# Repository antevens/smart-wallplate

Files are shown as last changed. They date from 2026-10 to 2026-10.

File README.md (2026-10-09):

# Smart wall plate

Replacement for a single-gang light switch: recessed IKEA BILRESA remote, hidden
emergency rocker, Apollo MSR-2 mmWave presence + SHT45 climate + a push-to-talk
microphone for Home Assistant voice, powered by a Mean Well IRM-03-5 on the wiring board.

Start with `AGENTS.md` (for people too), then `docs/SAFETY.md`. `docs/PRINTING.md` lists the print
jobs in order, `docs/ASSEMBLY.md` what holds each part, `docs/MEASUREMENTS.md` what is measured and
what is still an estimate.

Two variants: **NA** (single-gang Decora box, this page's main renders) and **EU** (round DIN 49073
box, `cad/build123d/eu/`, `pcb/eu/`). Both can run the BILRESA without batteries through a
replacement back cover powered from the plate.

The plate is two printed parts: a **box insert** (all mains/low-voltage barrier
geometry, UL94 V-0 PC-FR) and a **trim plate** (PETG/ASA), for an Elegoo Centauri
Carbon 2.

The house wiring lands on one board: L/N/PE in and out on a WAGO push-in block,
the Marquardt 1802.2504 DPST emergency rocker, and the PSU, all in a 2.5"
single-gang box. The KiCad project is in `pcb/`.

```bash
make system-deps     # once, Ubuntu 24.04 (KiCad 9, headless slicer libs)
make setup           # once (venv + pinned OrcaSlicer)
make cad check       # CAD -> build/, all checks must pass
make print           # OrcaSlicer projects -> print/*.3mf
make pcb             # all boards and flexes: ERC/DRC, STEP, PCBWay packs -> pcb/fab/, pcb/eu/fab/
make eu              # EU variant: CAD, checks, renders
make renders         # docs/renders/*.png
```

Nothing here is certified or code-compliant; see `docs/SAFETY.md`.

## How it is meant to be used

The design assumes every light bulb and device on the switched circuit is a smart
device that turns itself on and off (here IKEA Matter-over-Thread bulbs). The circuit
stays powered; day-to-day control is wireless: the BILRESA remote in the plate, Home
Assistant, the IKEA app, or Alexa / Google / other assistants.

The rocker hidden behind the remote is not the everyday light switch. It is there for
two cases:

- **Controller or cloud down.** When Home Assistant, the IKEA hub or the voice
  assistant is unavailable, turn the rocker off and on again. The bulbs restart and come
  on by themselves at their built-in power-on brightness. This needs each bulb's power-on
  behaviour set to "On" (D-8); check it per bulb.
- **Safety.** Off cuts line and neutral to the fixtures on this circuit (and powers down
  the plate's sensors), for example when a bulb or fixture misbehaves or needs changing.
  It is not a substitute for the breaker: turn the breaker off before working on any
  wiring (`docs/SAFETY.md`).

Voice: the plate's microphone streams to Home Assistant's Assist pipeline only when
listening is started from Home Assistant, for example by an automation on a BILRESA button
(D-29). There is no wake word and no speaker in the plate; replies go to another device.

Plain (non-smart) bulbs on this circuit would just follow the rocker, and the remote,
the sensors and the automations could not control them.

## Renders

### v0.3

Shaded views of the assembly: trim plate (white), box insert (grey), BILRESA
remote (model), Marquardt 1802.2504 rocker (red), wiring board (green, KiCad
model), board posts (orange). Regenerate with `make renders`.

| Front | Remote lifted out |
| --- | --- |
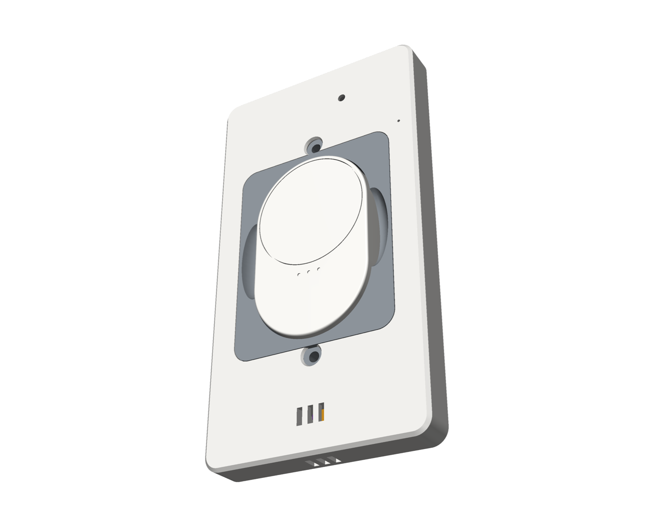
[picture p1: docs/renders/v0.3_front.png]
v0.3 front
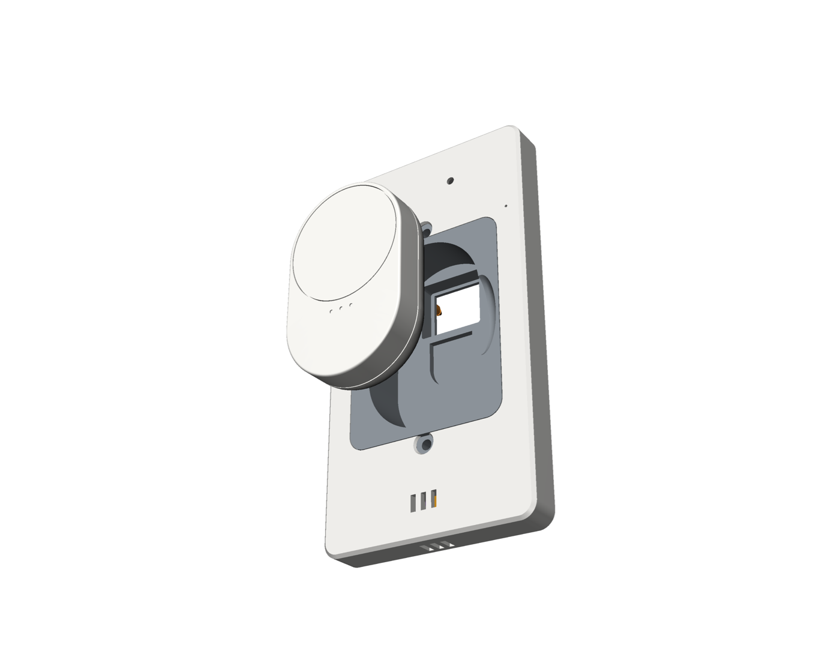
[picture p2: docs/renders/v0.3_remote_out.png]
v0.3 remote out
|  |  |

| Half-section | Back, mains side |
| --- | --- |
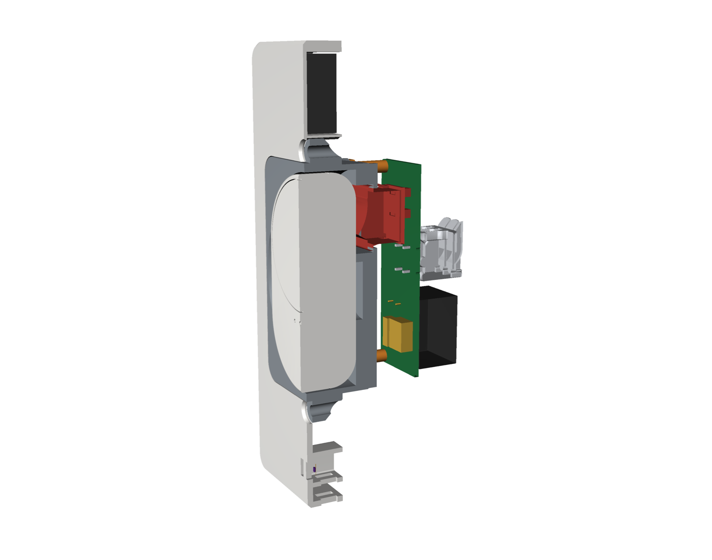
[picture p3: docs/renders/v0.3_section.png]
v0.3 half-section
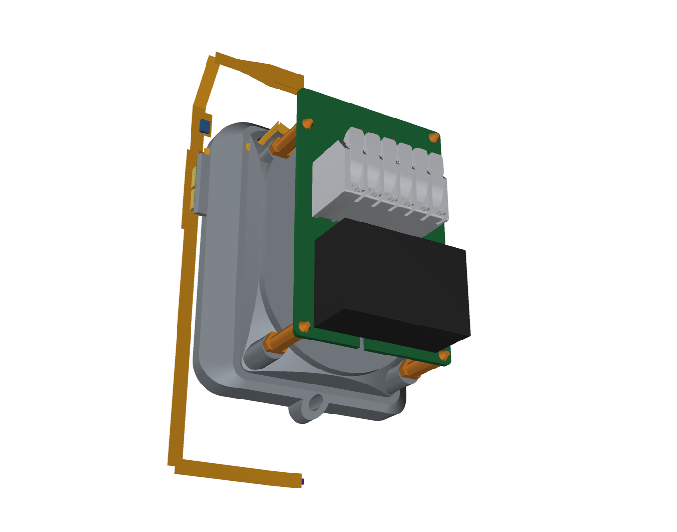
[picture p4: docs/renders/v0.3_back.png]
v0.3 back
|  |  |

Exploded: remote, trim plate, box insert, the four board posts that screw into
the insert's bosses (D-28), wiring board (with the rocker, WAGO block and PSU from
the KiCad model).

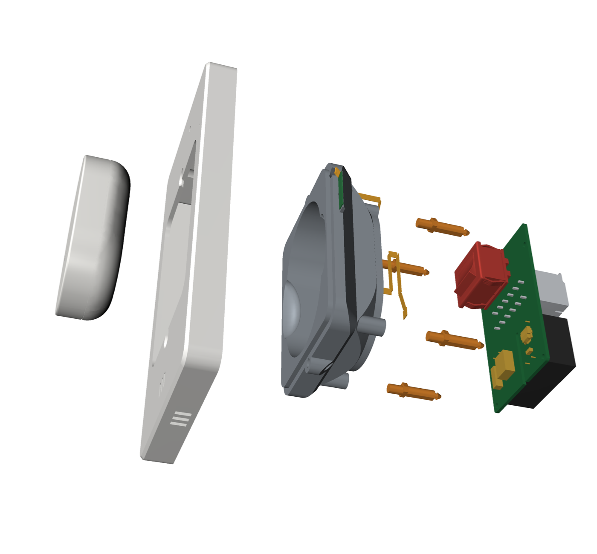
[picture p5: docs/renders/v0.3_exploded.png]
v0.3 exploded assembly


Sensor flex (D-27, trim and remote hidden): from the MSR-2's rear connector across
the top, down the right channel past the insert, to the SHT45 on its tail.

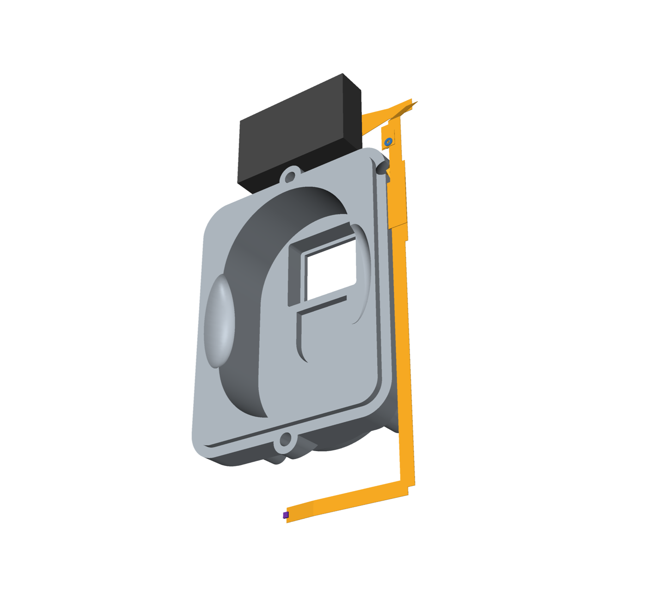
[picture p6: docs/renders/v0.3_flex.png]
v0.3 sensor flex route


Power contact: two spring fingers on the flex press on the gold pads of the 5 V jumper's
stiffened end, which sits on a shelf off the insert flange.

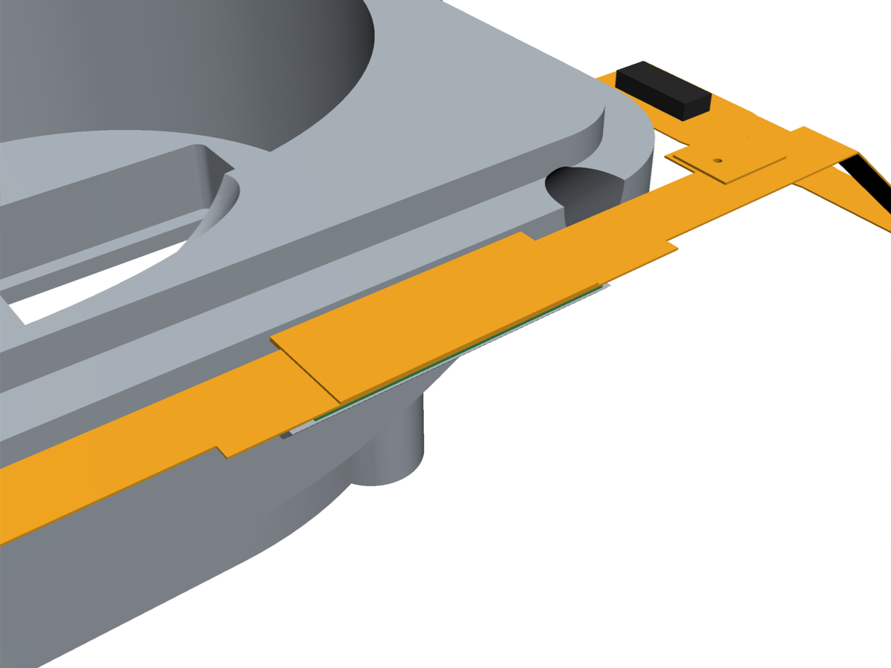
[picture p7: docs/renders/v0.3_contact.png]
v0.3 spring-finger power contact


5 V power path (insert cut at the pass-through, seen from the right): a single-layer flex
jumper plugs into J2 on the wiring board (Hirose FH12-6S, slide lock), folds once between the
board and the insert (a 40 mm service loop: plug it in with the board held beside the insert,
where the latch can be seen), goes up through the pass-through and out of the flange, and ends
on the shelf under the spring fingers. No wires, no solder joints at assembly.

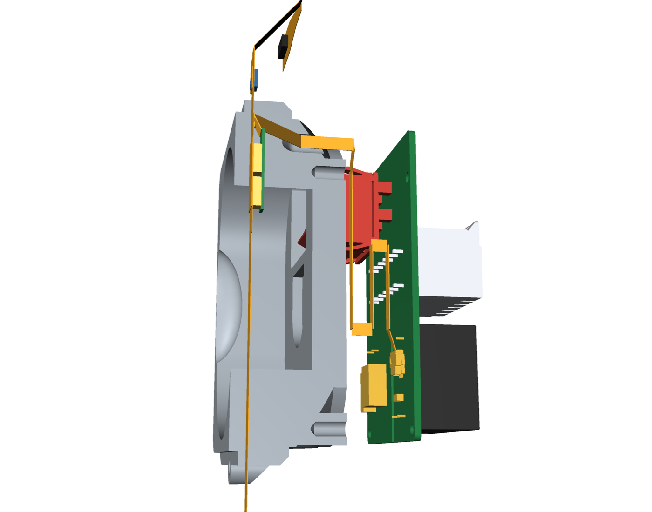
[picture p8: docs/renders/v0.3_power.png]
v0.3 5 V power path


Face plate lifted off (trim see-through): the flex with the MSR-2, SHT45, mic and spring fingers goes
with the face plate; the 5 V jumper (wiring board J2 -> pass-through -> pad end on the shelf) stays on
the insert side. The fingers on the jumper's pads are the only electrical interface (R9, checked).

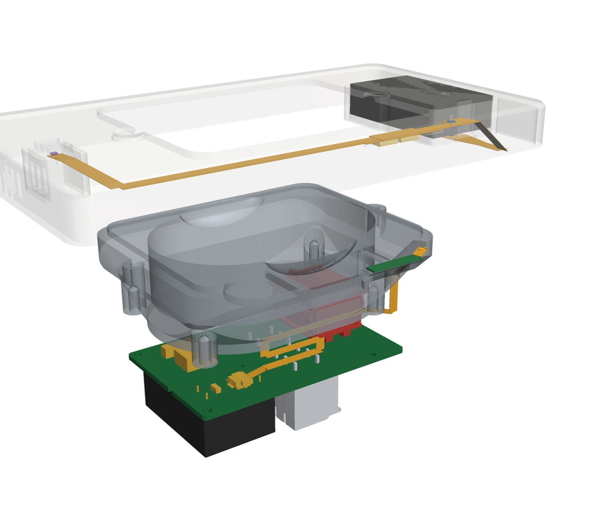
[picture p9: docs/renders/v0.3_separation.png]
v0.3 face plate and insert separated


Microphone (D-29, push-to-talk voice to Home Assistant): an I²S MEMS microphone under the
flex in the right channel, its port sealed by a gasket ring to a Ø1.0 sound hole in the face
skin. Sections through the sound hole, across and along the channel:

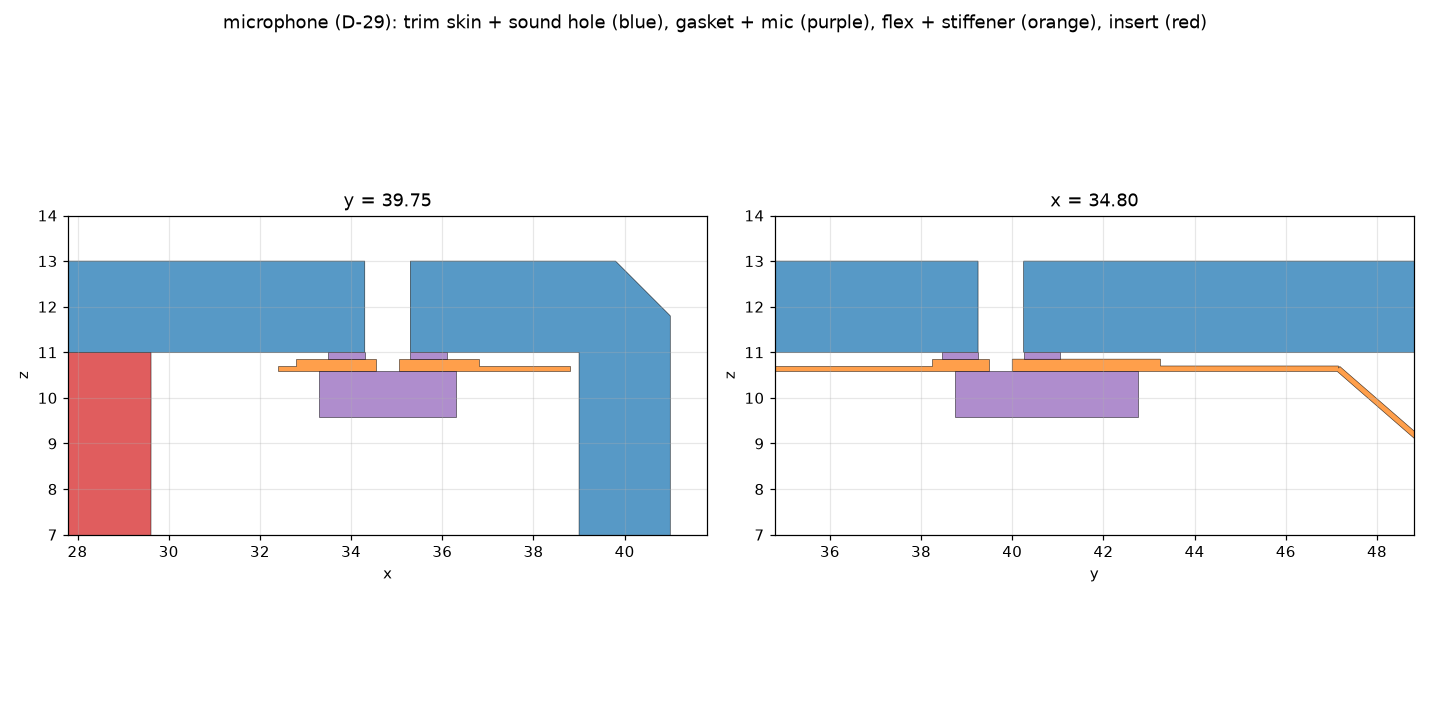
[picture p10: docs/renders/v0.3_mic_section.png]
v0.3 microphone sections


BILRESA model: stadium outline, wheel with its gap ring, three LEDs, side
parting line, and a back that curves from a flat central pad out to the sides.

| Front | Back |
| --- | --- |
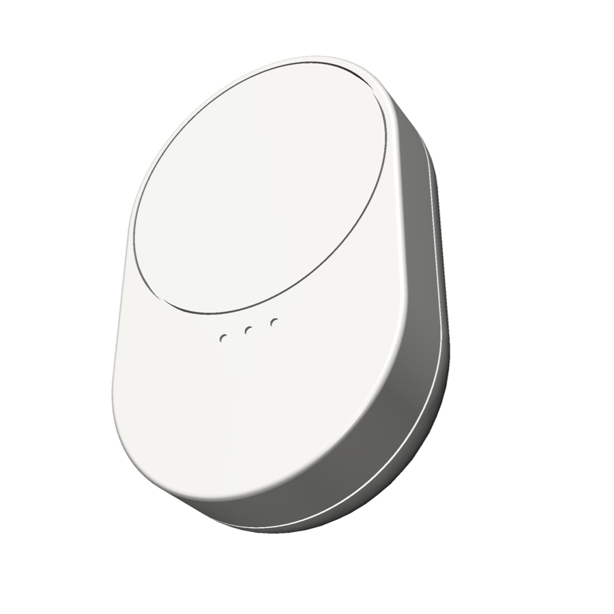
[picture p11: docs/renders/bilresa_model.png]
BILRESA model, front
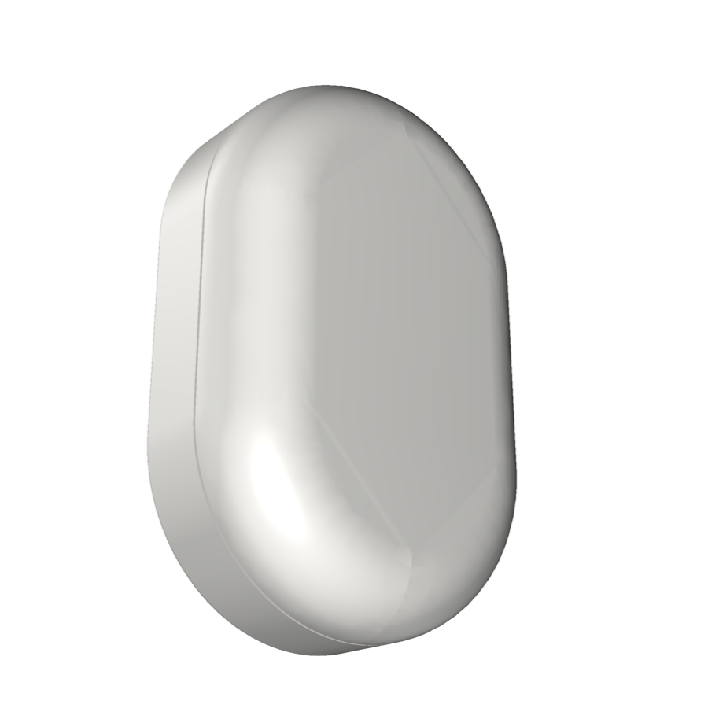
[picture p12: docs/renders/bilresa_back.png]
BILRESA model, back
|  |  |

Cross-sections: box insert (red, UL94 V-0), trim plate (blue), wiring board
(green), board posts (orange), BILRESA (grey). The dashed line is the wall surface;
the x = -21 cut runs through two posts and their bosses.

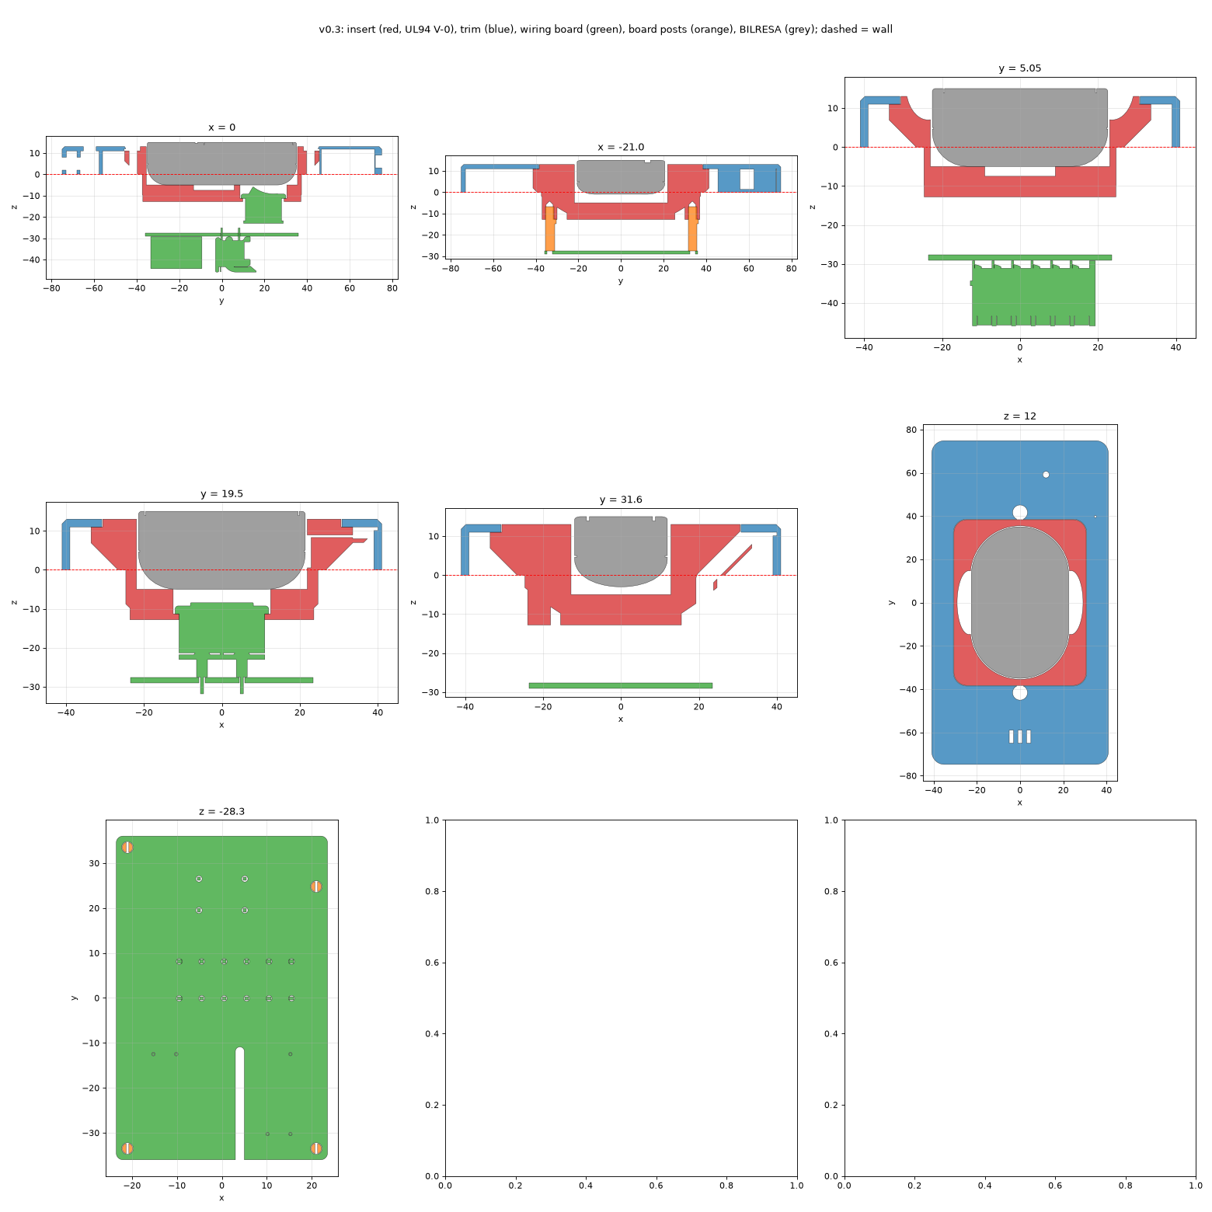
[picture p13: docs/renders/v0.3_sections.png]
v0.3 assembly cross-sections


### v0.3 wiring board

KiCad renders of `pcb/`. The front faces the plate (rocker, SMD
fuse and MOV, 5 V connector); the back faces the box (WAGO block, PSU). The four
corner holes take the insert's snap posts; they are unplated with no copper round them, and the
PE ring detours round them, so earth continuity never depends on the posts or on vias.

| Front | Back |
| --- | --- |
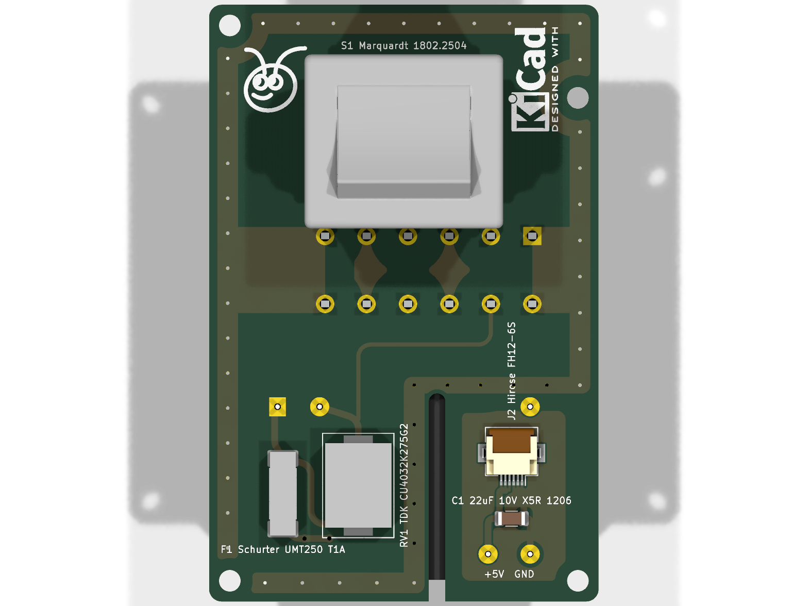
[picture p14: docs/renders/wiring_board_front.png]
Wiring board, front
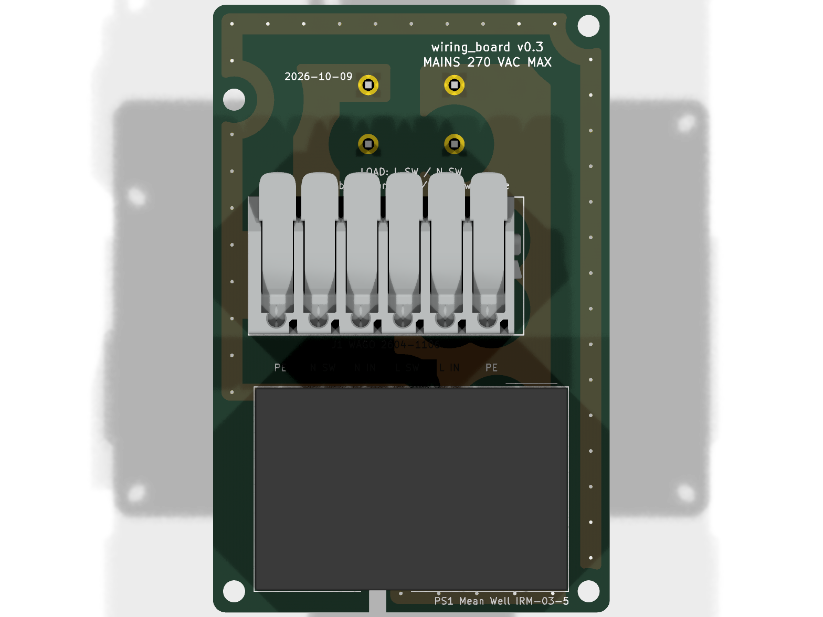
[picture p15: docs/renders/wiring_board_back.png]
Wiring board, back
|  |  |
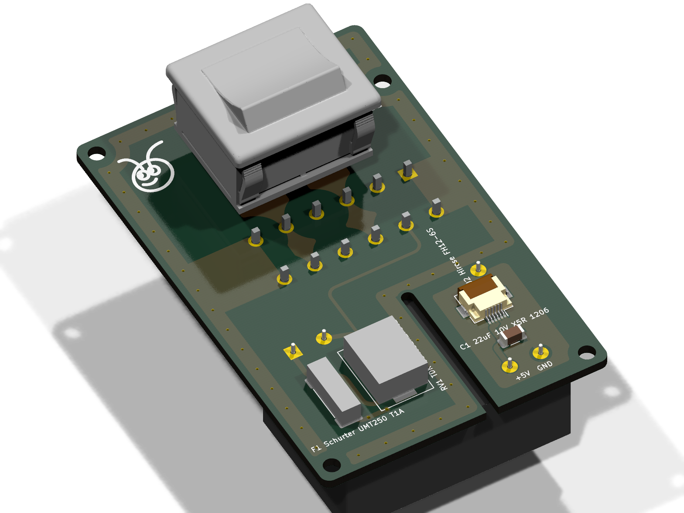
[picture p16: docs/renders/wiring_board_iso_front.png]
Wiring board, front, angled
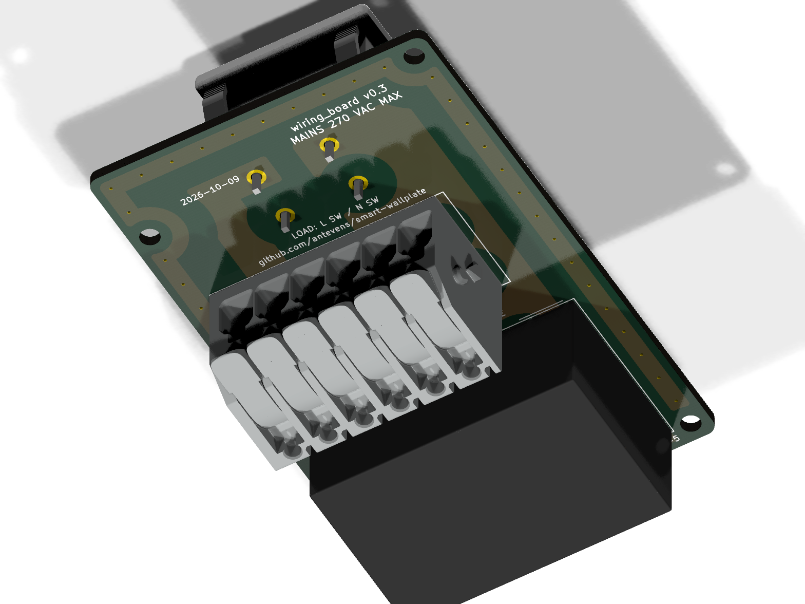
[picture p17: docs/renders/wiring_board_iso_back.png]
Wiring board, back, angled
|  |  |

Without components, so every trace and pour shows:

| Front | Back |
| --- | --- |
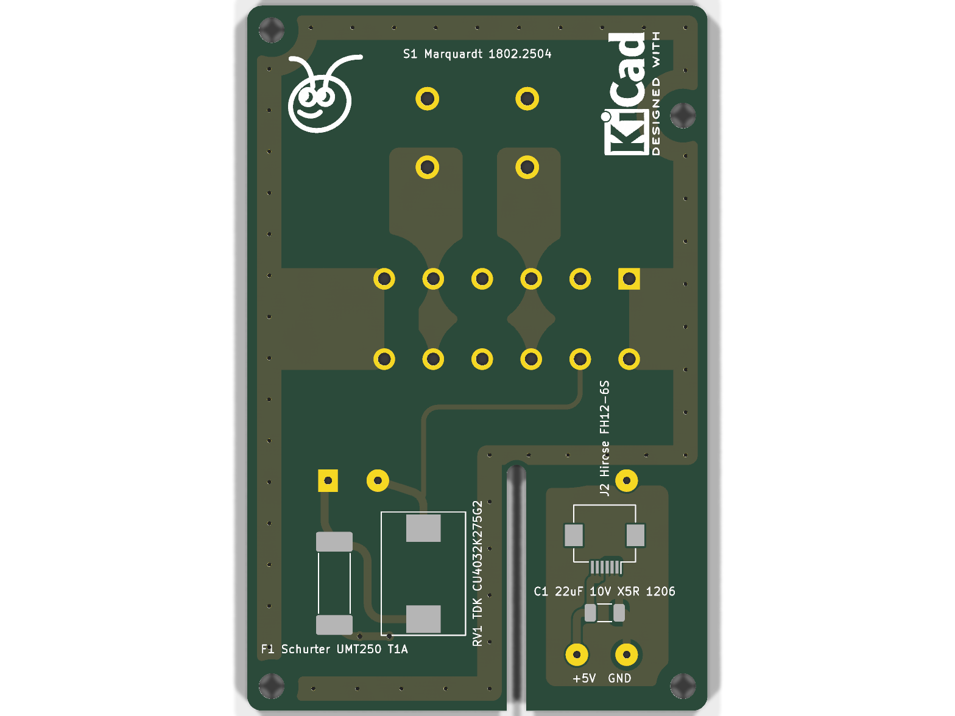
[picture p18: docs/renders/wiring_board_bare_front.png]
Wiring board, bare front
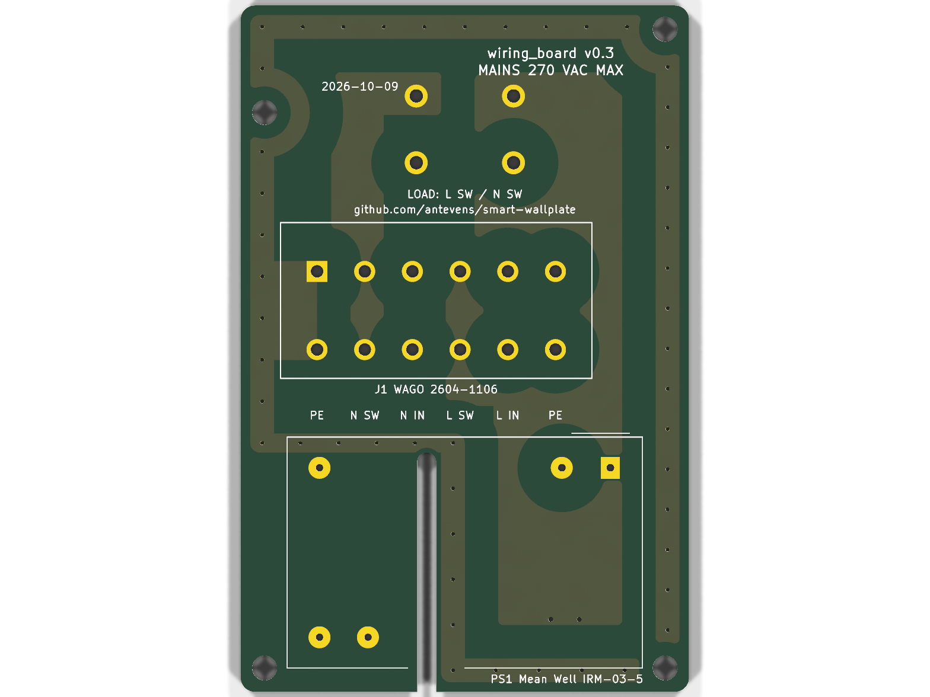
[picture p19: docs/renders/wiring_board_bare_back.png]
Wiring board, bare back
|  |  |
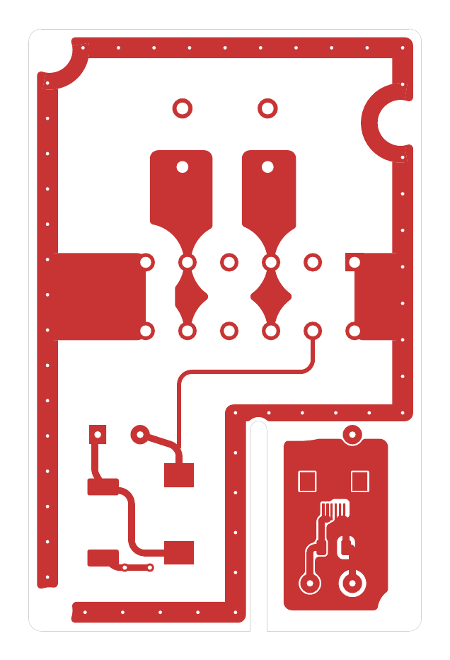
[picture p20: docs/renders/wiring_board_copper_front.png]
Wiring board, front copper
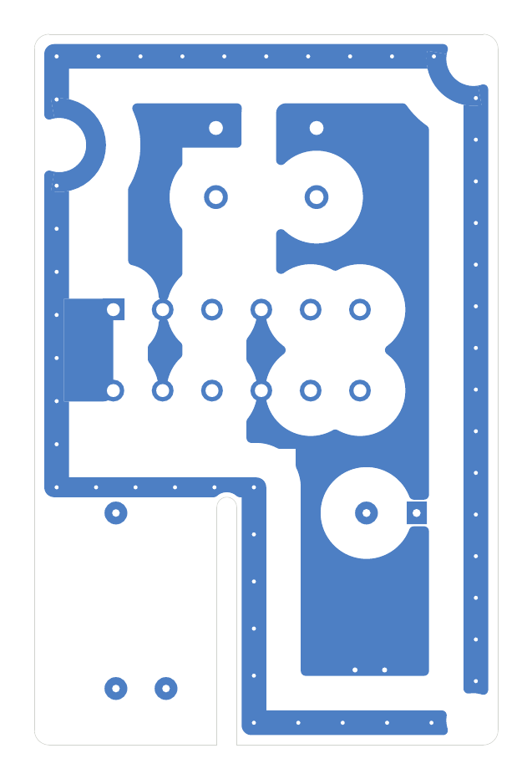
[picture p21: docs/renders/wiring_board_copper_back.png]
Wiring board, back copper, seen from behind
|  |  |

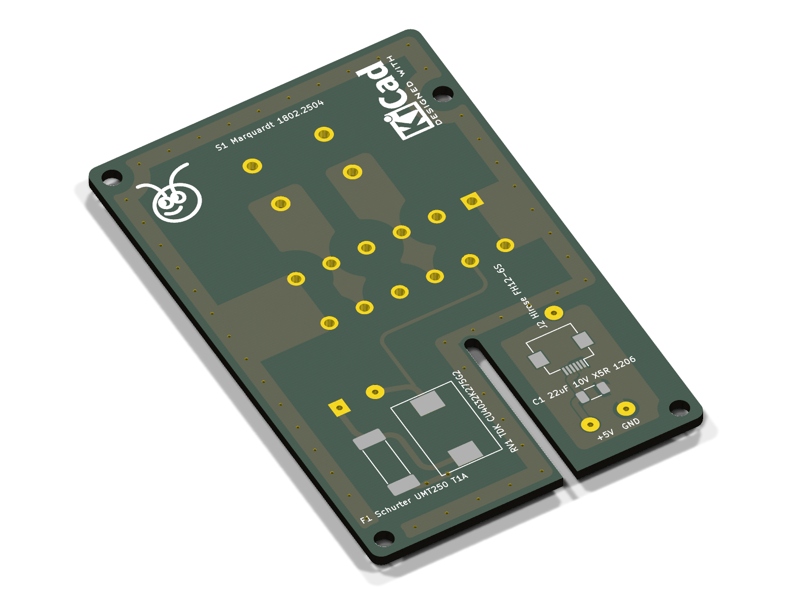
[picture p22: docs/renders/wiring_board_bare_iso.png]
Wiring board, bare, angled


### EU variant (concept, D-30, D-36)

A separate design for a round EU flush box (68 mm hole saw, Ø60 inside); `make eu`, `cad/build123d/eu/`,
`pcb/eu/`. The remote sits flush on a V-0 cap over the box; the emergency rocker (Marquardt 1802.2504,
as on the NA plate) under it is hidden until the remote is lifted out. Two boards: a mains board at
the rocker's PCB seat (rocker, two WAGO push-in blocks, fuse, MOV, PSU over a routed relief slot,
5 V island with a header) and a 5 V board just under the cap (pin socket on the header, two spring
pins up through the cap onto gold pads on the sensor flex: nothing soldered, wired or plugged
across). Box values are catalogue placeholders until measured; the stack reaches 43 mm deep (to be
tried in a box).

| Remote in place | Remote lifted: rocker |
| --- | --- |
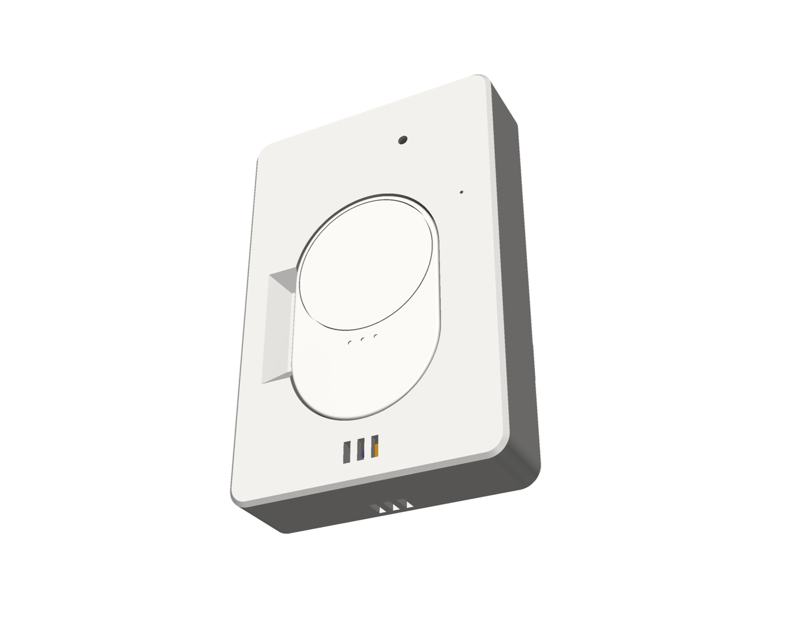
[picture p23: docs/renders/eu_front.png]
EU plate
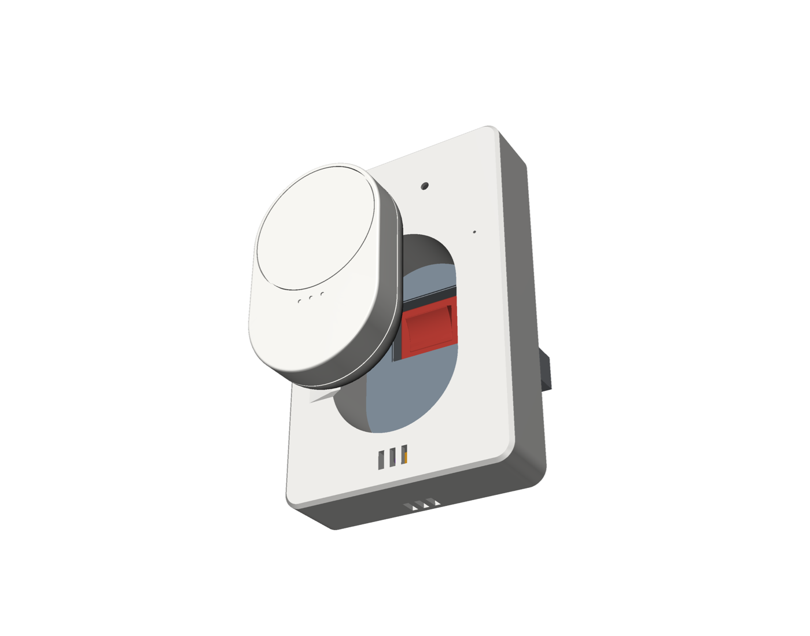
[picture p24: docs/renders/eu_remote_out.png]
EU plate, remote out
|  |  |
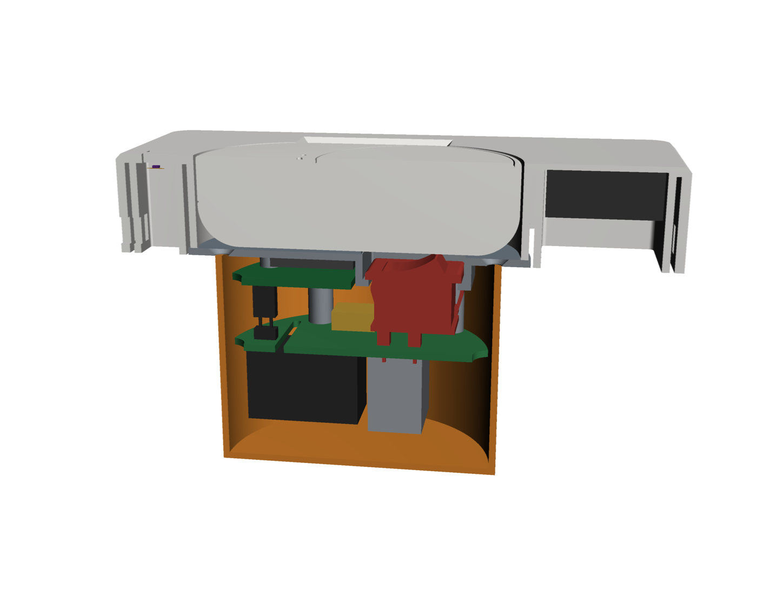
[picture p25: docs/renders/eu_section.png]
EU section
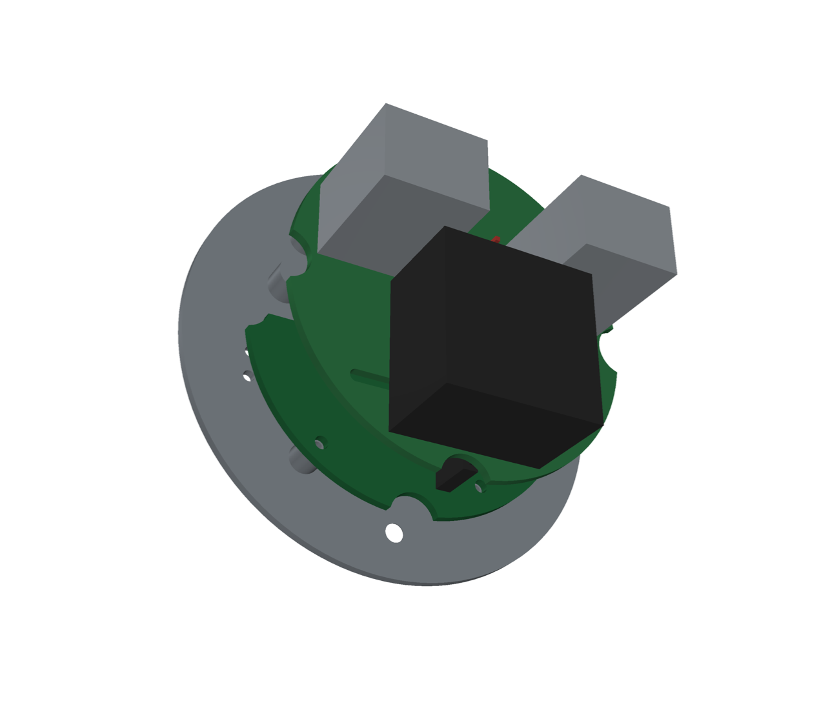
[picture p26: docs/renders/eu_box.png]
EU box from behind
|  |  |

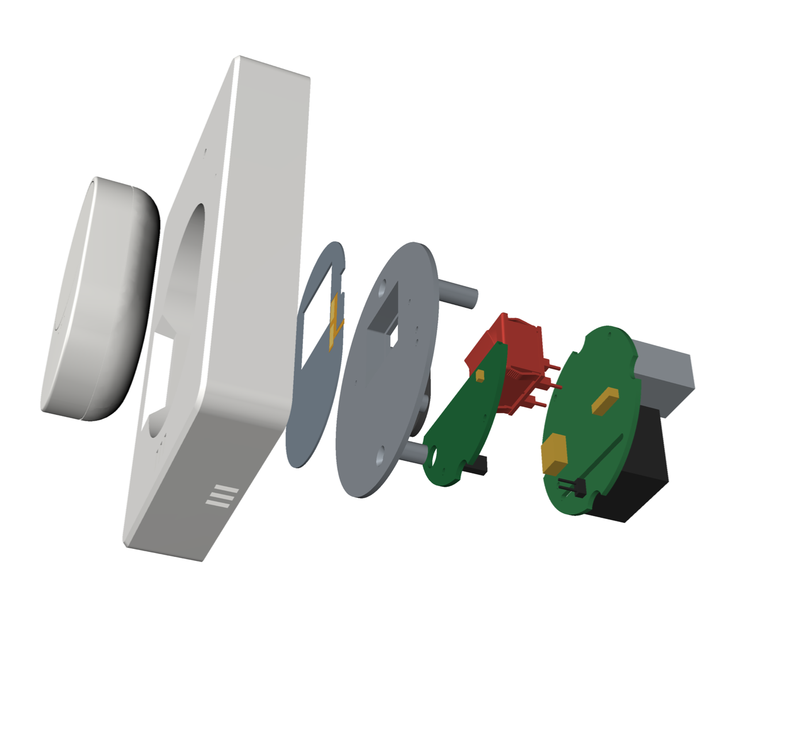
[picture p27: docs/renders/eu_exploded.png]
EU exploded


Face plate lifted off: the spring pins on the 5 V board stand through the cap; the flex's pads on
the pins are the only interface (R9, checked).

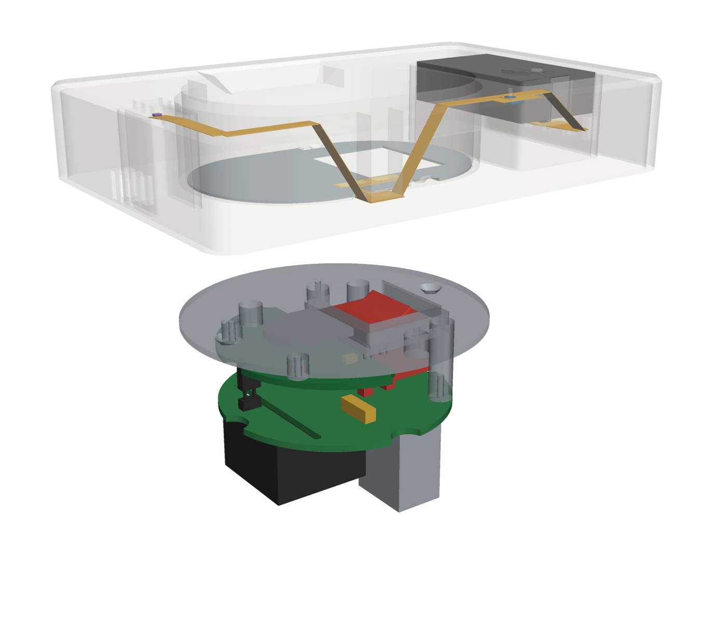
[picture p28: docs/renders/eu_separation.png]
EU face plate and cap separated


| Flex | Power contact through the cap |
| --- | --- |
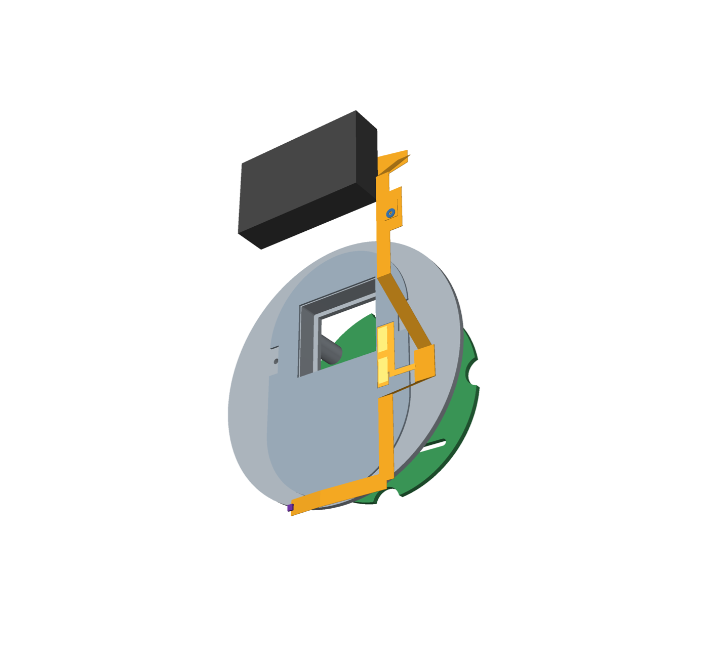
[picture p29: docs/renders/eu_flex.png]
EU flex
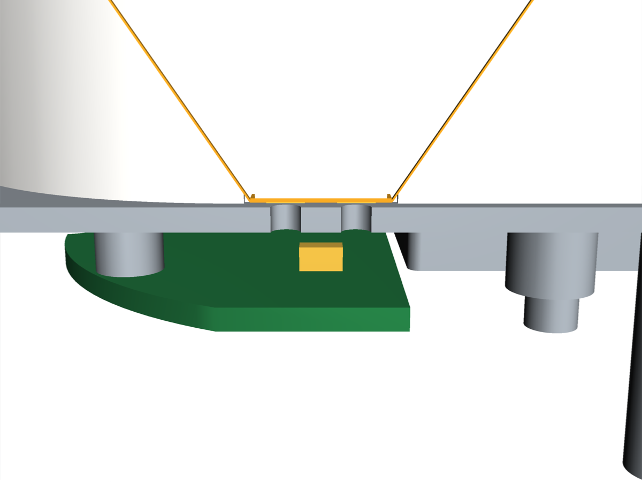
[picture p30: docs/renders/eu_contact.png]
EU spring-pin contact
|  |  |

Section through the spring pins: 5 V board, pins through the cap, flex pads, trim rib behind them.

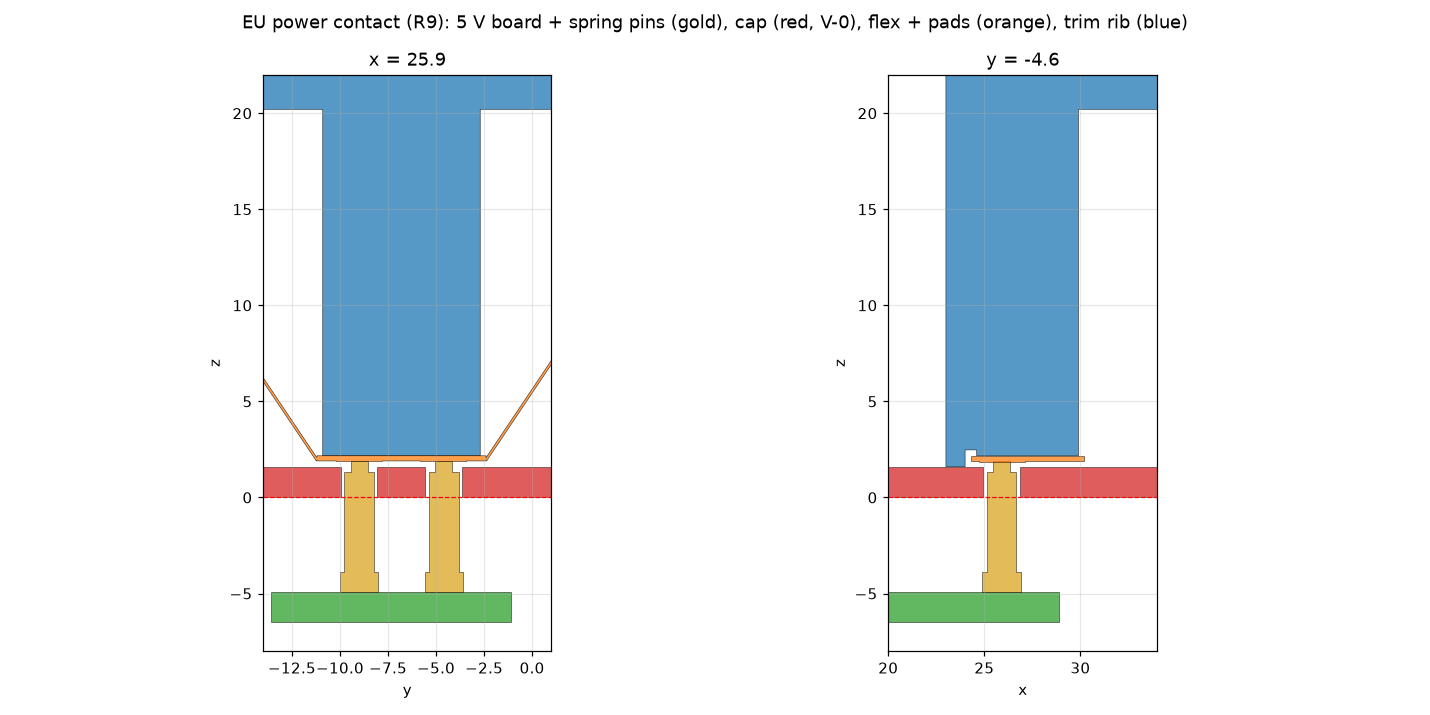
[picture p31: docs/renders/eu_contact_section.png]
EU contact section


Mains board: L pours on the front, N pours on the back, the relief slot under the PSU, the 5 V island
with the header; installer labels on the back.

| Mains board, front | Mains board, back |
| --- | --- |
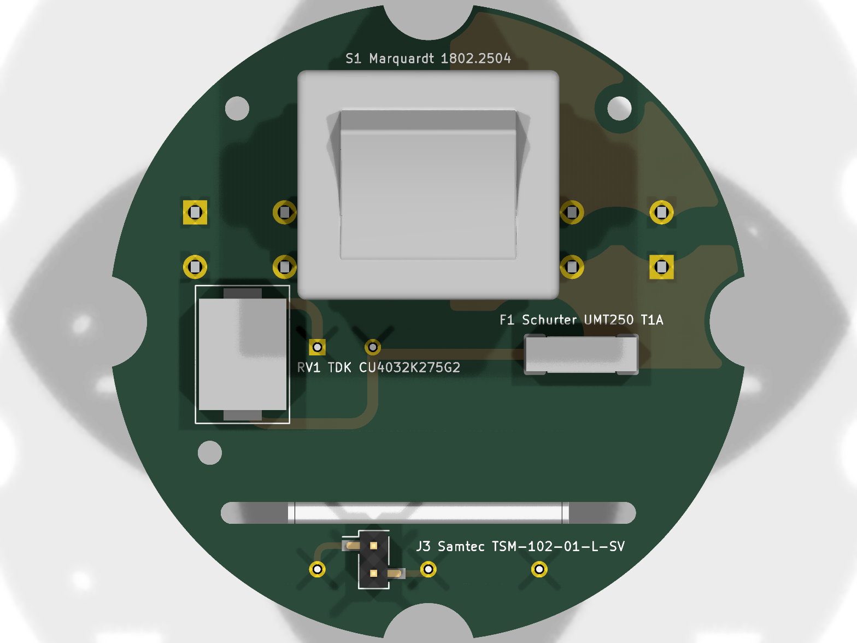
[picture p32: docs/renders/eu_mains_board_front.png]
EU mains board, front
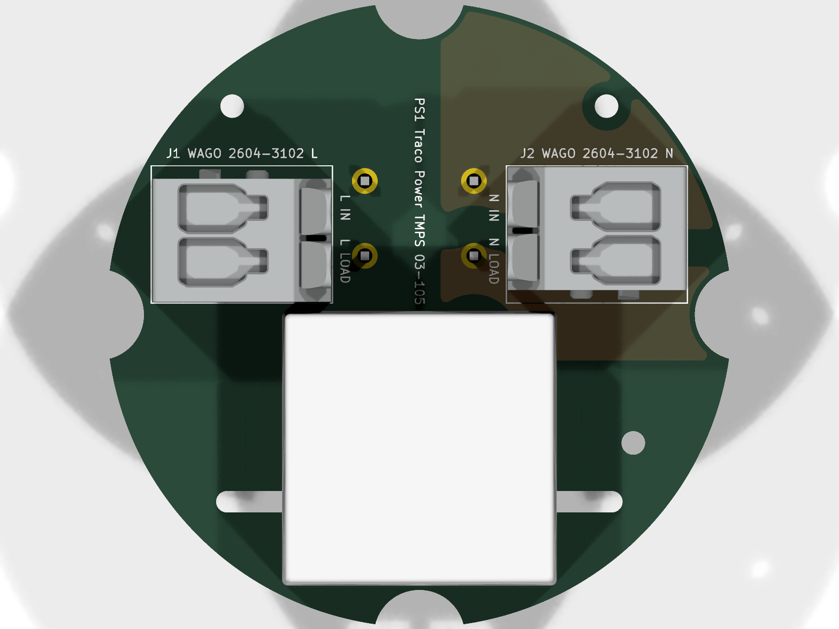
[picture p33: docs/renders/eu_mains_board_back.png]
EU mains board, back
|  |  |
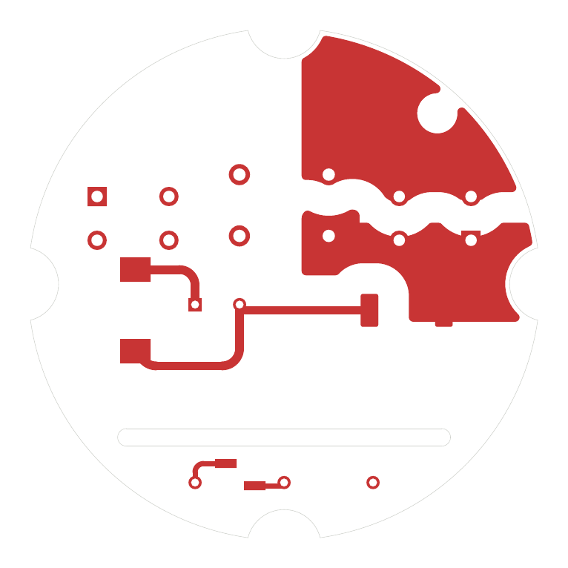
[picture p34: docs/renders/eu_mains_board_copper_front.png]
EU mains board, front copper
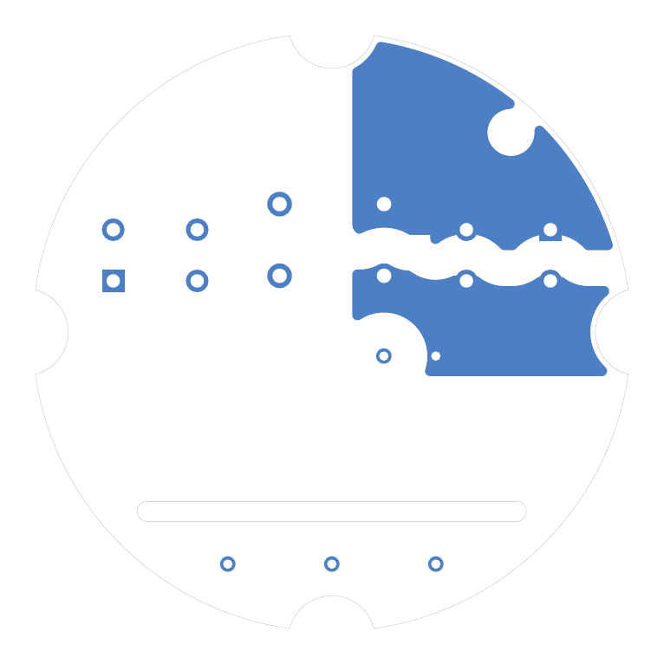
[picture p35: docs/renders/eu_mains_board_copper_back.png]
EU mains board, back copper
|  |  |

| 5 V board, front | 5 V board, back |
| --- | --- |
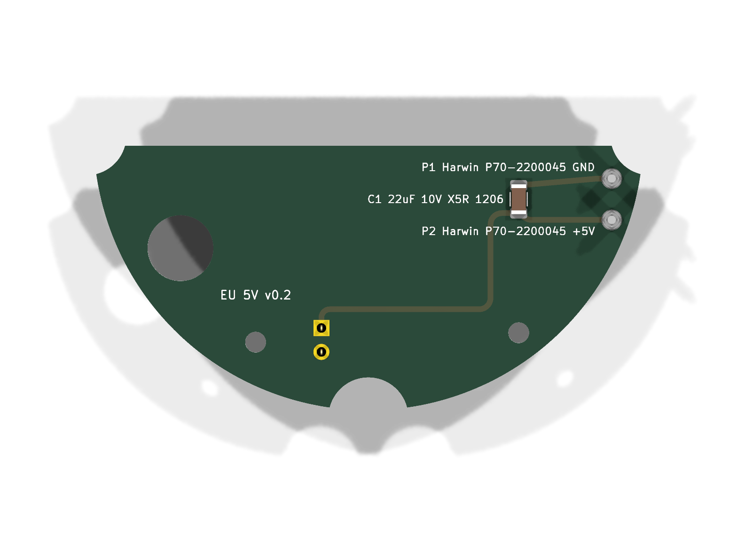
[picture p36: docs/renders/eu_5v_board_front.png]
EU 5 V board, front
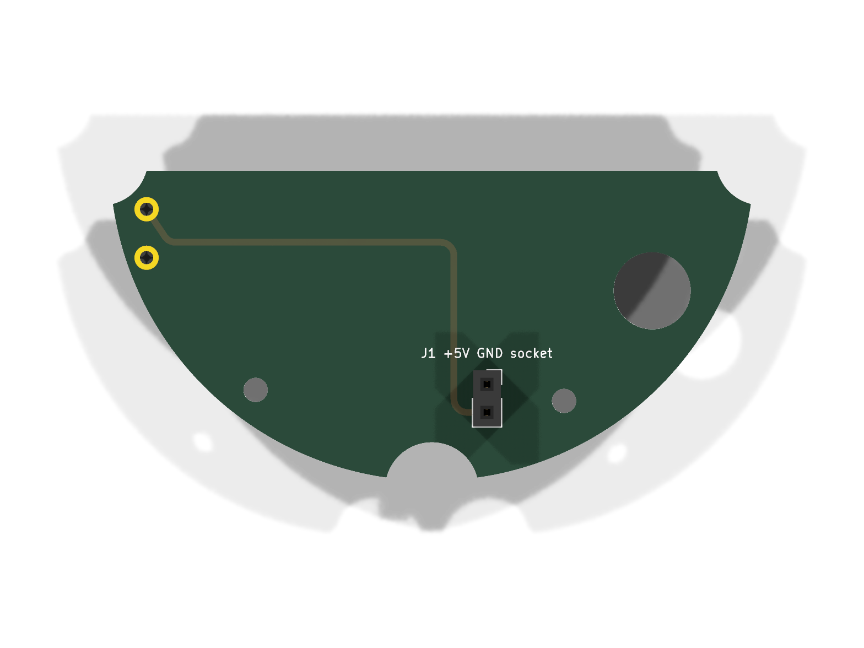
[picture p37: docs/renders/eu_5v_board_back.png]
EU 5 V board, back
|  |  |

### Replacement back cover (D-35, D-40, D-41, D-44, D-45)

Runs the remote without cells. The printed cover snaps onto the remote like the original (clips at
the top and bottom, side ribs, a pry notch) and carries the remote's magnet plate in a clipped pocket
and a flex: two spring fingers poke through windows in its back onto flush gold pads (+5 V, GND) in a
thin pocket-floor insert, a 3.3 V regulator on the flex feeds the remote, and at the terminal end two
more fingers press on the remote's VBAT plate and GND spring. The flex is held by a stiffener and two
heat-staked pegs and, at the end, by lips and hooks on the contact blocks. On NA the floor pads come
from a tongue of the 5 V jumper through the insert above the wall plane; on EU from a tongue of the
sensor flex. No new openings in the mains barrier. Several remote dimensions are still estimates
(`docs/MEASUREMENTS.md`).

| NA, exploded: floor insert, tongue, cover, remote | NA, section on the tongue |
| --- | --- |
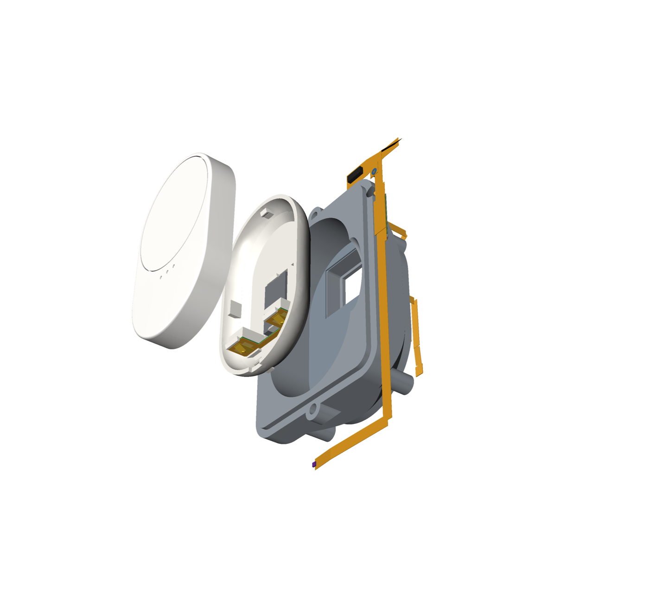
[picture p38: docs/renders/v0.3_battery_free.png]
Battery-free, exploded
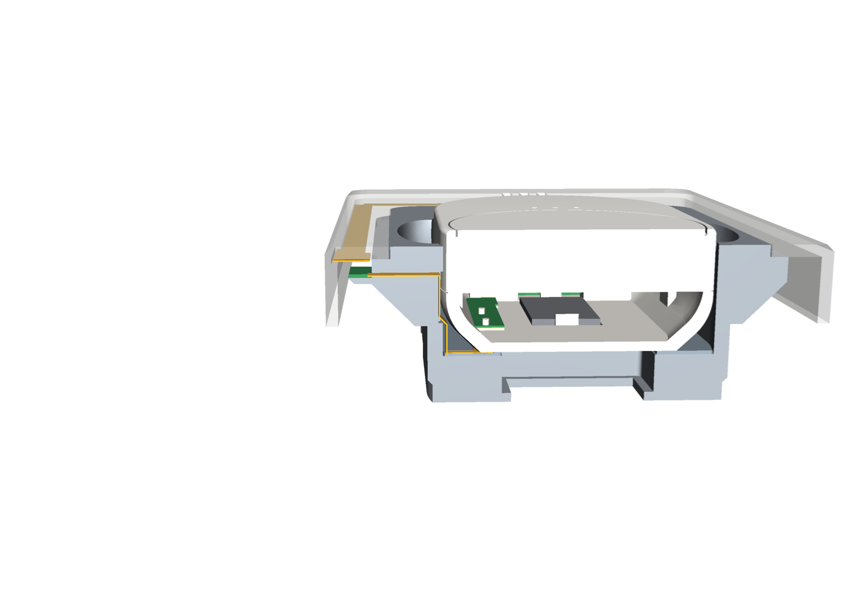
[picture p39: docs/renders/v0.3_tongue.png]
Battery-free, tongue section
|  |  |

| Cover, inside | Cover, back (fingers free) |
| --- | --- |
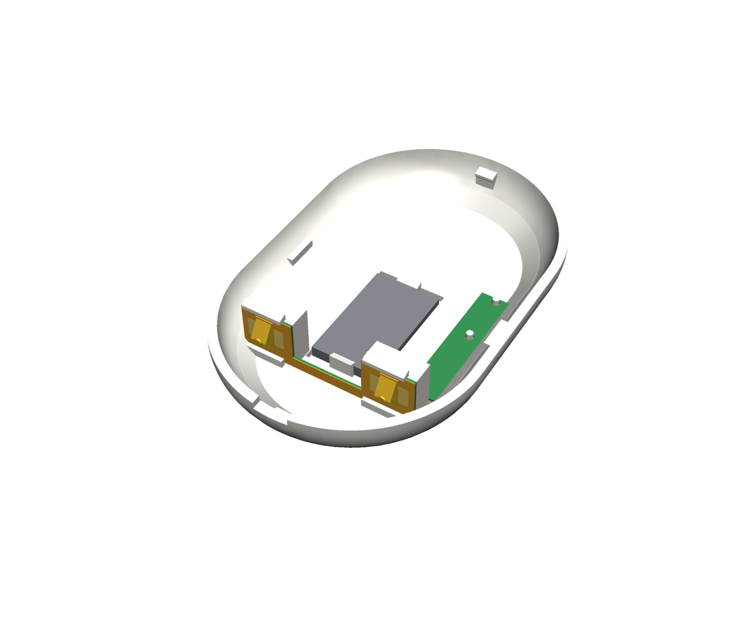
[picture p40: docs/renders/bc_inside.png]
Back cover, inside
|  | Back cover, back |

| Pocket-floor insert in the EU plate | Exploded: remote, cover, floor insert, plate |
| --- | --- |
| Pocket-floor insert | Back cover, exploded |

Cut through a finger: window, finger on the floor pad, ledge, flex. And through the VBAT contact:
the finger on the end section, its dome on the remote's battery plate.

Back cover, finger section

Back cover, VBAT contact section

Back cover flex, copper

### Sensor flex and 5 V jumper

KiCad projects in `pcb/sensor/` (D-27). The flex is drawn flat: one strip, folded twice at 45°
in the trim. Left to right: CN2 plug (placeholder, not for fabrication yet), the microphone on
its widened section (D-29), the two spring fingers over the jumper's pads, the SHT45 at the tail.

Sensor flex, copper

5 V jumper, drawn flat (two layers): FH12 contacts at the left, gold pads for the spring fingers at
the right (+5 V first, GND passing it to the far pad), and the battery-free tongue down to its two
floor pads.

5 V jumper, copper

EU sensor flex, drawn flat: CN2 plug, the microphone on its outer side, the two pads under the
spring pins, the battery-free tongue between them (folded 45° on the floor), the SHT45 at the tail.

EU sensor flex, copper

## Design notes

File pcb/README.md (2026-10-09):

# Wiring board (v0.3)

The single wiring board for the v0.3 plate (docs/DESIGN.md D-24, D-25, D-26). One board
carries the house wiring terminal block, the
emergency rocker that switches line and neutral, and the PSU that feeds the MSR-2.

Spacing values below are design targets for human review. Nothing here is a
compliance claim, and nothing on this board has been checked by a third party.

## Layout

Coordinates are front view in millimetres: X right, Y up toward the rocker, origin at
the board centre. F faces the plate, B faces the box.

- Board: 47 x 72 x 1.6 mm, corner radius 1.5 mm.
- Routed slot: 5 mm wide at X 3.0, from the bottom edge up to Y -10.9, under PS1.
- PE ring on both layers round the AC part, with stitching vias about every 4 mm. Earth
  continuity does not depend on vias or on copper the posts press on: on F.Cu alone, J1.6 ->
  left edge -> round MH1 -> top -> round MH3 -> J1.1 is one piece of copper, and `gen_pcb.py`
  fails the build if it is not (checked with the vias left out). The ring detours round MH1
  and MH3 on the inside; MH2 interrupts the ring's bottom-left corner (the lower part stays joined
  to both arms). B.Cu is a parallel ring joined to J1.6 by the vias.
- PE arms from the ring to J1.6 (left, F) and J1.1 (right, F and B): 10.4 mm wide, flush with
  the outer edges of the pin pair's pads (row distance 8.2 plus the 2.2 mm pad),
  ending square at the pins' centre line so the pads keep the 3.5 mm to the neighbouring
  L / N terminals.
- Pours that compete for copper have fixed priorities (line over neutral), so the fill is
  the same on every rebuild.
- 5 V area: bottom right (X 7 to 19.5, Y -33.5 to -13), GND pour on F.
- Mounting holes for the insert's snap posts (D-28), 2.6 mm, all unplated: MH1 (-21, 33.5),
  MH2 (-21, -33.5), MH3 (21, 24.77), MH4 (21, -33.5). A rule area keeps all copper 2.75 mm
  from each hole on both layers (the post's shoulder and snap head bear on bare laminate).
  Board-only footprints, not in the BOM or centroid. Mains copper keeps 1.0 mm from holes.

## Parts

| Ref | Part | MPN | Side, position | Source |
| --- | --- | --- | --- | --- |
| S1 | Marquardt rocker, DPST, PCB pins | 1802.2504 | F, (0, 19.5), turned 90 degrees | Marquardt drawing 1802.2504 rev g (K-drawing 18022504.03) |
| J1 | WAGO PCB terminal block, 6-pole, 5 mm, lever | 2604-1106 | B, pin 1 at (15.5, 8.1) and (15.5, -0.1) | <https://www.wago.com/global/pcb-terminal-blocks-and-pluggable-connectors/pcb-terminal-block/p/2604-1106> |
| PS1 | Mean Well AC-DC module, 5 V 600 mA | IRM-03-5 | B, under the slot | <https://www.meanwell.com/Upload/PDF/IRM-03/IRM-03-SPEC.PDF> |
| F1 | Schurter UMT 250 SMD fuse, T1A 250 VAC | 3404.2416.22 | F, (-14.6, -23) | <https://us.schurter.com/bundles/snceschurter/epim/_ProdPool_/newDS/en/typ_UMT_250.pdf> |
| RV1 | TDK SMD varistor 275 VAC | B72660M0271K093 (CU4032K275G2) | F, (-5.5, -22) | <https://www.farnell.com/datasheets/2921094.pdf> |
| C1 | Murata MLCC 22 uF 10 V X5R 1206 | GRM31CR61A226KE19L | F, (13, -26) | <https://www.murata.com> |
| J2 | Hirose FH12 FPC connector, 6 contacts, 0.5 mm, slide lock, 5 V out to the flex jumper | FH12-6S-0.5SH(55) | F, (13, -19.5) | <https://www.hirose.com/product/en/products/FH12/FH12-6S-0.5SH(55)/> |

S1 data from the drawing:

- Contacts 1-1a and 2-2a.
- Holes 1.3 (+0.1) mm (drilled 1.4 mm here) on a 10.2 x 7 mm grid as mounted.
- Body 22 x 18.6 mm below the panel, flange 24 x 21 mm.
- PCB seat 16.2 mm below the panel face; rocker 5.3 mm above it.
- Marked ratings: ENEC 12(4) A 250 V~; UL/CSA 15 A 125-250 VAC.
- The drawing is not in the repository.

## Nets

| Net | Class | Connects |
| --- | --- | --- |
| /L_IN | Mains_L | J1.5, S1.1 |
| /L_SW | Mains_L | J1.4, S1.1a, F1.1 |
| /L_F | Mains_L | F1.2, PS1.1 (AC/L), RV1.1 |
| /N_IN | Mains_N | J1.3, S1.2 |
| /N_SW | Mains_N | J1.2, S1.2a, PS1.3 (AC/N), RV1.2 |
| /PE | PE | J1.1, J1.6, PE ring |
| +5V | SELV | PS1.16, C1.1, J2.4–6 |
| GND | SELV | PS1.14, C1.2, J2.1–3 |

S1 pin positions (front view): L_IN (-5.1, 19.5), L_SW (-5.1, 26.5), N_IN (5.1, 19.5),
N_SW (5.1, 26.5). Pins 1 / 2 lie on the body's centre line, 1a / 2a 7 mm off it (drawing
1802.2504 rev g), so the body is centred on the in pins.

Load current path:

- Line: J1.5 to S1.1 on F, then S1.1a to J1.4 on B. The B path runs down under J1 and
  up the left edge.
- Neutral: J1.3 to S1.2 on F, then S1.2a to J1.2 on B. The B path runs up the right side.

## Rules

The rules are in `kicad/wiring_board.kicad_dru`, written by `tools/gen_project.py`.

- L to N: 3.5 mm.
- L_IN to L_SW and L_F: 3.5 mm.
- N_IN to N_SW: 3.5 mm.
- Mains to PE: 3.5 mm.
- Mains to SELV: 8.0 mm clearance and creepage, with the routed slot.
- Mains to the PSU NC pin: 8.0 mm.
- Mains copper to board edge: 1.0 mm; other copper 0.5 mm.
- Pads of one footprint keep the part's own spacing. This is the exception for
  certified parts.

Creepage is checked only for mains to SELV. On this flat board the surface path
between copper on one layer is never shorter than the straight gap, so the 3.5 mm
targets are checked as clearance. KiCad evaluates creepage rules without the
footprint, so a per-part creepage exception cannot be written.

## Status

Done:

- Generators for the libraries, the project and rules, the schematic, the board and the
  3D envelopes.
- Placement, outline and slot, PE ring with stitching vias, pours, tracks and silkscreen.
- All nets routed.
- ERC: 0 errors, 0 warnings.
- DRC (`--severity-all --schematic-parity`): 0 violations, 0 unconnected, 0 parity issues.
- STEP model in `build/wiring_board.step`; PCBWay order pack in `fab/`; renders in
  `docs/renders/wiring_board_*.png` (`make renders`).

Open:

- Meter-check the S1 pin numbering on a sample. The drawing's side view labels the
  pins 1a / 1 / 1b.
- Check the J1 pin rows on a part. They come from WAGO's 3D model (rows y 8.1 and -0.1,
  8.2 apart, D-37).
- Thermal review of the 15 A paths. The 3.5 mm targets to the neighbouring J1 pads (round,
  2.2 mm, 5 mm pitch) leave 1.6 to 1.8 mm of pour beside each pad (N_SW 1.3 mm, beside
  the PE arm) over the 2 to 3 mm where the pours leave J1. Options are 2 oz copper, or
  different targets between in and switched terminals of one pole.
- S1's body sits on the front over J1's first pin row: pad edge 1.0 mm from the body
  outline (`PAD_BODY_GAP`, checked by `make check` for every through-hole pad against the
  bodies on the other side). J1's levers overhang the S1 pins 13.9 mm or more above the
  board.
- F1 rating (T1A) is a designer's choice. Its 200 A breaking capacity at 250 VAC
  needs review against the branch circuit's prospective fault current.
- RV1 pad gap: the datasheet's D = 10.1 mm does not match B + C + B; the larger gap
  is used.
- C1 is a generic part; any 22 uF 10 V X5R 1206 fits.

## Silkscreen labels and 3D models (all boards)

Every part carries a silkscreen label with its reference and maker / model (value and size for
generic passives; net names on bare contact pads), on the side it is mounted, placed by
`tools/kigen.py` (`place_labels`): next to the part, clear of pads, other silkscreen, other parts'
courtyards and the board outline (slots included). On a single-layer flex with no room on the
copper side the label goes on the bare back. ERC / DRC (all severities) check the result.

3D models come from `tools/gen_3d.py` into each project's `kicad/3d/`: a vendor STEP from
`scratch/3d/` when present (moved into footprint coordinates by its entry), otherwise an envelope
from the datasheet dimensions. Vendor files stay in the git-ignored `scratch/` (their terms).

| Model | Source now | Vendor model |
| --- | --- | --- |
| Traco TMPS 03 | vendor (tracopower.com, 3D drawings; pins checked against the pads) | in use |
| Mean Well IRM-03, Hirose FH12-6S, Samtec TSM (EU J3), 0402 / 1206 passives | KiCad library | in use |
| Schurter UMT 250 | envelope | <https://www.schurter.com/en/datasheet/UMT%20250> |
| TDK SIOV CU4032K275G2 (B72660M0271K093) | envelope | <https://product.tdk.com/en/search/sensor/protect/varistor/info?part_no=B72660M0271K093> |
| WAGO 2604-3102 | vendor (wago.com, CADENAS; pins checked against the pads) | in use |
| WAGO 2604-1106 | vendor (wago.com, CADENAS; pins checked against the pads) | in use |
| Marquardt 1802.2504 | vendor 1802.1108 housing (Marquardt LIB_1802.1108; same 1802 flange, rocker, body) on the 1802.2504 underside from its drawing (body to 11.7, pin stems to the 16.2 seat, 0.8 pins; pins checked against the pads) | 1802.2504 itself: on request from Marquardt |
| Harwin P70-2200045 | envelope | <https://www.harwin.com/products/P70-2200045/> |
| Harwin S7081-42R | envelope (shape from the drawing) | <https://www.harwin.com/products/S7081-42R/> |
| PUI DMM-4026-B-I2S-R | envelope | <https://puiaudio.com/product/microphones/dmm-4026-b-i2s-r> |
| Sensirion SHT45 (DFN-4) | envelope | <https://sensirion.com/products/catalog/SHT45> |

To use a vendor model: put its STEP in `scratch/3d/`, add the file name and its transform to the
entry in `tools/gen_3d.py`, run `make pcb`, and check the pins against the pads (export the board
to STEP).

## Regenerate

Needs KiCad 9 (`kicad-cli` and the `pcbnew` Python module) and the repository's
`.venv` with build123d.

```bash
make pcb        # runs pcb/tools/build.sh
```

The script runs these steps:

- `gen_3d.py`: the 3D models in `kicad/3d/` (vendor STEP from `scratch/3d/` when present).
- `gen_libs.py`: the symbol and footprint libraries.
- `gen_project.py`: the project seed and DRC rules.
- `gen_schematic.py`: the schematic.
- `gen_pcb.py`: the board, including the zone fill.
- ERC and DRC: reports go to `build/`.
- STEP export to `build/` and the PCBWay order pack in `fab/` (`gen_fab.py` writes the
  BOM and the centroid; S1 is not fitted).

All part data, nets and geometry live in `tools/parts.py`.

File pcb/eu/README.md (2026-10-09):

# EU mains board and 5 V board (D-30, D-36)

Two boards in the round EU flush box (DIN 49073, Ø60 inside), both hanging from bosses under the
V-0 cap. Generated from `tools/eu_parts.py`, which takes its geometry from
`cad/build123d/eu/params_eu.py`.

## Mains board (`kicad/eu_mains_board.*`)

Round, at the rocker's PCB seat (16.2 mm below its panel face). The rocker breaks line and neutral
of the lights; the PSU is fed from the switched side, so the rocker also turns the sensor off.

| Ref | Part | Side | Nets |
| --- | --- | --- | --- |
| S1 | Marquardt 1802.2504 rocker, DPST, PCB pins, ENEC 12(4) A 250 V~, UL/CSA 15 A | front (through the cap's panel) | 1 L_IN, 1a L_SW, 2 N_IN, 2a N_SW |
| J1 | WAGO 2604-3102, push-in, 2-pole, 4 mm², entry 90° to the board, 400 V III/2; turned 180° from J2 | back | L_SW (pole 1), L_IN (pole 2, upper) |
| J2 | WAGO 2604-3102 (as J1) | back | N_IN (house neutral), N_SW (to the lights) |
| F1 | Schurter UMT 250, T1A 250 VAC | front | L_SW to L_F |
| RV1 | TDK CU4032K275G2, 275 VAC | front | L_F to N_SW |
| PS1 | Traco TMPS 03-105, 5 V 600 mA (IEC/UL 62368-1, IEC 60335-1; OVC II, PD2, reinforced) | back | inputs L_F / N_SW above the slot, outputs +5V / GND below it |
| J3 | Samtec TSM-102-01-L-SV, SMT pin header 1x2, 2.54 mm, 5.84 mm post (no pin tails under the PSU) | front, 5 V island | +5V, GND |
| MH1-MH3 | M2 holes on the cap's long bosses | - | - |

- The lights' current runs in copper pours: L_IN and L_SW on F.Cu (right), N_IN and N_SW on B.Cu
  (left), in above switched, as the rocker's poles; the split between them steps from the rocker's
  poles down to the WAGO block's. WAGO pin rows and body from WAGO's 3D model (8.2 mm apart, levers
  towards the board centre, where the blocks' pins stay 1.0 mm clear of the rocker body on the
  front); blocks at x ±16.6, y 7.5. The PSU feed (L_F, N_SW to F1 / RV1 / PS1) is
  1.0 mm track. Order with 2 oz copper for the load paths (sizing: human review).
- A routed relief slot under the PSU, between its input and output rows, cuts off the 5 V island
  (PSU outputs, J3). Mains copper keeps ≥ 8 mm (clearance and creepage) from it.
- Keep-out areas round the mounting holes: mains copper ≥ 1.0 mm from them.
- No PE on the board: the lights' protective earth is joined in the box (lever connector).
- Installer labels on the back: L IN / L LOAD, N IN / N LOAD at the WAGO blocks, MAINS 230 VAC.

## 5 V board (`kicad/eu_5v_board.*`)

D-shaped, just under the cap, cut below the switch cup; a hole lets the mains board's lower long
boss through. No mains on it.

| Ref | Part | Side | Nets |
| --- | --- | --- | --- |
| J1 | 2.54 mm pin socket 1x2 (8.5 mm), on the mains board's J3 | back | +5V, GND |
| C1 | 22 µF 10 V X5R 1206 | front | +5V to GND |
| P1, P2 | Harwin P70-2200045 SMT spring pins, 2 A | front | GND (P1, upper), +5V (P2) (through the cap onto the flex's pads; order set by the flex's tongue, D-42) |
| MH1, MH2 | M2 holes on the cap's bosses | - | - |

The header posts reach 3.2 mm into the socket (boards 13.8 mm apart; check with the parts).
Nothing is soldered or wired between the boards or across the cap (DESIGN R9, R10).

## Rules

`kicad/eu_mains_board.kicad_dru`: L–N ≥ 3.5 mm, any two different mains nets ≥ 3.5 mm (line / switched
line / fused line, neutral / switched neutral), mains to the 5 V side ≥ 8.0 mm (clearance and
creepage), mains to the PSU's NC pin ≥ 8.0 mm, mains copper ≥ 1.0 mm from the board edge and the
holes; pins of one rated part keep the part's own spacing. The mains pours carry their own 3.5 mm
clearance. Design targets for human review, not a compliance claim.

The net classes come from the project file; `tools/gen_eu.py` rewrites it after every save
(pcbnew's SaveBoard resets it). The single EU PSU board before D-36 was checked without them, so
its isolation was never verified by DRC.

## Regenerate

```bash
make pcb        # or pcb/eu/tools/build.sh
```

PCBWay packs for both boards in `fab/` (`fab/README.md`: order settings and the review checklist).
Order only after the review and a dry fit of the stack in a real box.

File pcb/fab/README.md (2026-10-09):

# Wiring board v0.3 – PCBWay order pack

Generated by `make pcb` (`pcb/tools/build.sh`). Do the human-review checklist below
before ordering. Spacing values are design targets, not a compliance claim.

| File | Use |
| --- | --- |
| `wiring_board_v0.3_gerbers.zip` | Upload as the PCB file: RS-274X Gerbers, Excellon drills in mm (PTH and NPTH separate), drill maps |
| `wiring_board_v0.3_bom.csv` | Assembly BOM with MPNs. S1 has quantity 0 (do not fit) |
| `wiring_board_v0.3_centroid.csv` | Centroid, both sides, origin = board centre. S1 is left out |
| `wiring_board_v0.3_assembly_front.pdf` | Assembly drawing, front (F) |
| `wiring_board_v0.3_assembly_back.pdf` | Assembly drawing, back (B), mirrored view |
| `wiring_board_v0.3_schematic.pdf` | Schematic |
| `erc.rpt`, `drc.rpt` | ERC and DRC reports of this build (all severities, schematic parity on) |
| `gerbers/` | The unzipped Gerber and drill files |

## PCB order settings

- Size 47 × 72 mm, 2 layers, FR-4, 1.6 mm.
- Copper weight: open, see the thermal review below (1 oz as designed, 2 oz option).
- Surface finish HASL lead-free or ENIG. Solder mask and silkscreen on both sides.
- **The outline has a 5 mm routed slot** from the bottom edge up under PS1. It is part of
  Edge.Cuts, not a drill. Add "routed isolation slot in outline, do not omit" to the order
  remarks.
- Four 2.6 mm mounting holes, all unplated (NPTH drill file), with no copper under the posts.
- No castellations, impedance control or V-cut.

## Assembly

- Front (F): F1, RV1, C1, J2 (SMD, reflow). Back (B): J1, PS1 (THT).
- **S1 is not fitted by PCBWay.** The rocker snaps into the printed insert from the front
  first, then the board goes onto its pins from behind and S1 is soldered by hand.
- PS1 sits flush on the back. IRM-03 soldering limits per its datasheet: wave 265 °C 5 s,
  hand 390 °C 3 s.
- J1 wire entries face the board's top edge (towards S1), away from PS1.
- Source exactly the BOM MPNs for S1, J1, PS1, F1 and RV1 (safety-critical; no substitutes
  without review). C1 may be any 22 µF 10 V X5R 1206.

## Human review before ordering

- [ ] F1 rating T1A is the designer's choice; Mean Well gives none (inrush 20 A typ at
      230 VAC). Its 200 A breaking capacity at 250 VAC needs review against the branch
      circuit's prospective fault current.
- [ ] Isolation targets in `../kicad/wiring_board.kicad_dru` (D-24: L–N, L in to switched
      L, mains to PE ≥ 3.5 mm; mains to 5 V ≥ 8.0 mm plus the slot) reviewed against IEC
      60664-1 / 62368-1 and UL/CSA 62368-1.
- [ ] Thermal review of the 15 A paths (narrowest 1.3–1.8 mm between J1's pads, D-37); choose
      the copper weight.
- [ ] J1 pin rows (8.2 mm apart, from WAGO's 3D model, D-37) checked on a part.
- [ ] S1 pin numbering checked with a meter on a sample (D-26).
- [ ] Approvals of S1, J1, F1 and RV1 adequate for the BC homeowner permit and inspector.
- [ ] Gerbers opened in a viewer (PCBWay's online viewer is fine): the slot is present.

## Sources

- IRM-03 datasheet, rev 2025-08-08: <https://www.meanwell.com/Upload/PDF/IRM-03/IRM-03-SPEC.PDF>
- Mean Well PCB-type installation manual: <https://www.meanwell.com/Upload/PDF/PCB_EN.pdf>
- Further part sources: `../README.md`.

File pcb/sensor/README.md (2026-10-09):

# Sensor flex and 5 V jumper (D-27, D-29)

Two flex circuits on the 5 V side, generated from `tools/sensor_parts.py`, which takes its
geometry from `cad/build123d/params.py` (the same routes and shelf as the CAD models in
`cad/build123d/sensor_flex.py` and `cad/build123d/jumper.py`).

Nothing here touches mains. Both boards are low-voltage only.

## Sensor flex

Single copper layer (F.Cu; KiCad keeps an empty B.Cu), polyimide, 0.12 mm, FR4 stiffeners.

In the trim the flex runs from the MSR-2 across the top, down the right channel and along the
bottom to the SHT45. Each of the two 90° corners is a 45° fold, which turns the strip over, so
in the flat it is one straight strip about 195 mm long with every part on the copper side:

- J1: mating plug for the MSR-2's rear connector CN2 (faces the MSR-2).
- J2, J3: Harwin S7081-42R spring fingers, +5 V and GND (face the jumper's pad end).
- U1: Sensirion SHT45 with C1 (100 nF) on the tail (face the trim's vents).
- MK1: PUI Audio DMM-4026-B-I2S-R I²S microphone with C2 (100 nF) and R1 (100 kΩ SD pull-down),
  in the right channel above the fingers, port towards the face skin (D-29).

The fold lines are on `Cmts.User`, the stiffeners (behind J1, behind J2/J3 and behind MK1) on
`User.1`.

Between the plug end and the strip the flex tapers over 10 mm (`FLEX_NECK_L`), shallow enough
for the ten lanes to run in parallel; the MSR-2 bay frame's notch is sized from that outline.

Over the finger section the flex widens: towards the flange over the finger pads, and into a
1 mm recess in the trim's side wall for the four tracks that pass the pads.

Above the finger section the flex widens towards the flange (to 4.4 mm from the centre line,
room y 38–46) for the microphone. Its pins face the plug, the port end the fingers; the GND ring
(soldered all round, it seals the port) surrounds a Ø0.5 hole through flex and stiffener. On the
skin side an adhesive gasket ring (OD 2.6, ID 1.0, 0.15 mm) seals the stiffener to the face
skin around the Ø1.0 sound hole.

Nets: +5V (fingers to CN2), GND, +3V3 (CN2 to the SHT45), SDA = IO1, SCL = IO0 (MSR-2 I²C
bus; SHT45 at 0x44), I2S_SCK = IO4, I2S_WS = IO6, I2S_SD = IO7, MIC_3V3 and MIC_GND (the
microphone's own CN2 contacts, joined to +3V3 and GND on the MSR-2, so its lanes cross no
others).

## Microphone firmware (D-29)

ESPHome on the MSR-2, push-to-talk: Home Assistant starts listening (for example from a BILRESA
button automation calling the action) and the voice pipeline ends it on silence. Untested
starting point:

```yaml
i2s_audio:
  - id: i2s_mic_bus
    i2s_lrclk_pin: GPIO6
    i2s_bclk_pin: GPIO4

microphone:
  - platform: i2s_audio
    id: plate_mic
    i2s_audio_id: i2s_mic_bus
    adc_type: external
    i2s_din_pin: GPIO7
    channel: left              # LR tied to GND
    bits_per_sample: 32bit     # 24-bit data in a 32-bit word
    sample_rate: 48000         # BCLK 3.072 MHz; the mic sleeps below 2.048 MHz

voice_assistant:
  microphone: plate_mic

api:
  actions:
    - action: start_listening
      then:
        - voice_assistant.start:
    - action: stop_listening
      then:
        - voice_assistant.stop:
```

Open: whether the pipeline accepts 48 kHz from this microphone on the C3 or needs 32 kHz, and
the C3's RAM / CPU headroom next to the radar, Wi-Fi and BLE.

**Not ready to fabricate.** J1's footprint (0.4 mm, 2 x 15) and its contact map are
placeholders: CN2's part and pin map are not confirmed (D-27, `docs/MEASUREMENTS.md`). The map
in `CN2_MAP` only keeps the single-layer fan-out from crossing. `tools/build.sh` writes no flex
fab files while `CN2_CONFIRMED` is false.

## 5 V jumper

Two copper layers, polyimide, 0.2 mm (design value, confirm with the PCBWay stack-up), 156 mm long
in the flat (`params.jumper_length()` plus the two ends) plus the battery-free tongue (D-41). It replaces the 5 V lead and the target board: nothing on the 5 V path is wired or
soldered at assembly (DESIGN R9).

- J1: six exposed contacts at 0.5 mm pitch on a stiffened end (3.5 wide, 0.3 thick in total,
  `JUMPER_END`, MEASURE: check against Hirose's FPC drawing for the FH12-6S) that plugs into J2
  of the wiring board (Hirose FH12-6S-0.5SH, slide lock). Contacts 1–3 GND, 4–6 +5V, as on J2.
  Which face carries the contacts against J2's bottom contacts is to be checked on a sample.
- Run: 3.0 mm wide, +5V and GND tracks 0.5 mm (the MSR-2 draws < 0.2 A).
- TP1, TP2: gold pads (4.5 × 1.8) on the stiffened pad end (0.6 mm in total, FR4), which lies
  on the insert's shelf under the spring fingers: +5 V nearer the run, GND at the far end, its
  track passing the +5 V pad on the wall side.

Assembly: plug the connector end into J2 with the wiring board held beside the insert, where
the latch can be seen; thread the end up through the pass-through (3.5 mm end, Ø4.5 hole); fit
the board; the 40 mm service loop (`JUMPER_SERVICE`) folds between board and insert; the pad end
lies on the shelf (adhesive on its stiffener).

- Battery-free tongue (D-41): leaves the pad end's inner edge between TP1 and TP2, through a tunnel in
  the insert flange (above the wall plane), down a groove in the pocket wall and the wall into the NA
  floor insert's recess (two 90° bends, copper stays up), then a run, a down strip clear of the switch
  well's opening and the pad strip: TP3 / TP4, 7 × 4 mm gold pads (+5V, GND) under the back cover's
  fingers. GND stays on F.Cu off the edge lane; +5V leaves TP1 through a via and passes under it on
  B.Cu, which is why the jumper has two layers. Drawn flat from `sensor_parts.TONGUE_PTS`.

## Back cover flex

Single copper layer, polyimide, for the replacement back cover that powers a BILRESA E2490
without cells (`cad/build123d/backcover.py`, DESIGN D-35). Drawn flat, seen from the copper side.

- J1, J2: Harwin S7081-42R spring fingers (+3V3, GND) on the pad section, which lies copper down
  on a ledge in the cover; the fingers reach through windows onto the plate's flush floor pads
  (working height 2.0 mm).
- A 2.6 mm run (through a slot under the GND contact block) to the terminal end; one 90° bend
  (copper outside).
- J1 takes +5 V from the floor (D-41); U1 TI TLV75533PDBVR (3.3 V, SOT-23-5) with C3 / C4 1 µF on
  the section below the fingers, copper down in a recess in the cover (0.4 mm wall left), feeds VBAT.
- J3, J4: Harwin S7081-42R spring fingers (VBAT, GND) on the end section, on the cell axes, long
  axis vertical with the bend end up (the battery contacts ride down the arm's ramp as the cover
  goes on), on a 0.4 mm FR4 stiffener (back side). The end section stands 2.0 mm (the fingers'
  working height) in from the cell end plane: J3 presses the remote's fixed VBAT plate, J4 its GND
  leaf spring (finger and leaf share the travel). Between them only a band passes under the
  remote's PCB strip.

Not ready to fabricate: the positions come from the FCC internal photos (REF) or are MEASURE;
`tools/build.sh` writes no `fab/cover_flex/` while `COVER_CONFIRMED` is false.

## EU sensor flex (`kicad/eu_sensor_flex.*`, D-30, D-42)

Single copper layer, the NA topology on the EU route (`cad/build123d/eu/sensor_eu.py`), drawn flat by
`tools/eu_flex_parts.py` (X developed along the strip through the dip, Y inwards).

- J1: CN2 mate (placeholder footprint and contact map, as on the NA flex). GND comes out on two
  contacts: GND (pin pad, tongue) and GND_SHT (the SHT45), joined on the MSR-2; MIC_3V3 / MIC_GND as
  on the NA flex.
- MK1 on the strip's outer side (mic section widened outwards): WS / SCK enter the inner pad column
  from above, SD from below through the gap with R1 (100k to MIC_GND) before the body; MIC_GND /
  MIC_3V3 run under the outer column with C2 across them; GND on to the port ring.
- TP1 / TP2: Ø2.4 pads under the 5 V board's spring pins, GND first (P1), then +5V (P2); +5V and
  the SHT45 lanes step under TP1.
- Battery-free tongue (D-41): off the pad section's inner edge between TP1 and TP2 (GND from TP1,
  +5V from TP2, no crossing on one layer), under the pocket wall, 45° fold beside the floor pads
  (copper up), TP3 / TP4 2.9 × 7 mm floor pads under the back cover's fingers.
- U1 SHT45 + C1 on the tail. Fab files withheld while the CN2 contact map is a placeholder.

## Regenerate

```bash
make pcb        # also builds the wiring board; or pcb/sensor/tools/build.sh
```

`build.sh` runs `tools/gen_sensor.py` (libraries, projects, schematics, boards), ERC and DRC
(all severities, schematic parity), then writes `fab/power_jumper/`. Reports go to `build/`.

## Open

- CN2 mate: part, footprint, contact count and contact map (from the GPIO add-on's plug or
  Apollo). Then set `CN2_CONFIRMED`, regenerate, check the fan-out.
- Flex fab notes for PCBWay: folds, stiffener thickness and side, rolled-annealed copper for
  the folds, MK1's port hole through flex and stiffener, the gasket ring.
- Jumper: the FH12 contact end (`JUMPER_END`, `FPC_PAD`) against Hirose's FPC drawing, and the
  contact side, before ordering; the jumper passes through the mains volume (SAFETY item 4).
- MK1 pin 1 orientation against a part (footprint mirrored from the datasheet's bottom view).
- Microphone firmware test on an MSR-2 (sample rate, load).

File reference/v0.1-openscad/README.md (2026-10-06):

# Smart wall plate – first pass (v0.1)

Recessed IKEA BILRESA (intact, batteries in) + hidden emergency rocker behind it +
Mean Well IRM-03-5 PSU slot + Apollo MSR-2 bay + vented SHT45 bay.
NA single-gang device box (2" × 3" opening, #6-32 ears at 83.3 mm).

## Files
- `wallplate.scad` – parametric OpenSCAD source (OpenSCAD 2021+). `part="plate"` exports the printable part; `part="assembly"` shows ghost components; `explode=50` lifts the remote out.
- `plate.stl` – printable plate (print face-down; open back sits against the wall).
- `01`–`04` renders, `05` PSU carrier PCB + box wiring concept.

## Key dimensions (v0.1)
| | |
|---|---|
| Plate | 82 × 150 mm, 13 mm proud of wall |
| Remote | sits 2 mm proud; seat 5 mm into the box |
| Rocker well floor | 15 mm into box; switch body to ~40 mm |
| PSU slot | 40 × 36 mm PCB, IRM-03-5 to ~28 mm into box |
| Left for wiring/wire nuts | ~23 mm in a 2.5" box |

## MEASURE before printing (placeholders in the .scad)
`B_W, B_H, B_D` (BILRESA outline/depth) · `SW_BEZEL, SW_ROCKER_H, SW_BODY, SW_PANEL_T` (Bulgin C1300 datasheet) · `MSR` (bare MSR-2 envelope) · `LUX_POS` (light sensor) · steel target size · your box depth `BOX_D`.

## Notes
- Pocket shell + collar form the barrier between mains (box) and low voltage (plate hollow). Print those in a flame-rated filament; PLA/PETG only for test fits.
- Metal boxes: ears intrude at top/bottom of the opening and can shield the remote's radio – check both.
- The lighting circuit (15 A) is switched with wire nuts, not through the PCB.
- PCB is a concept: take the IRM-03 footprint and pinout from Mean Well's datasheet; size F1/RV1 per datasheet.

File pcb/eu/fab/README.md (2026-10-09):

# EU boards v0.2 – PCBWay order packs

Generated by `make pcb` (`pcb/eu/tools/build.sh`), one folder per board. Do the review checklist
below before ordering. Spacing values are design targets, not a compliance claim, and the EU stack
depth is still to be tried in a real box (D-36).

| File (in each board's folder) | Use |
| --- | --- |
| `<board>_v0.2_gerbers.zip` | Upload as the PCB file: RS-274X Gerbers, Excellon drills in mm (PTH and NPTH separate), drill maps |
| `<board>_v0.2_bom.csv` | Assembly BOM with MPNs (the mains board's S1 has quantity 0: do not fit) |
| `<board>_v0.2_centroid.csv` | Centroid, both sides, origin = board centre (S1 and the mounting holes left out) |
| `<board>_v0.2_assembly_front.pdf`, `_assembly_back.pdf` | Assembly drawings (back mirrored) |
| `<board>_v0.2_schematic.pdf` | Schematic |
| `erc.rpt`, `drc.rpt` | ERC and DRC reports of this build (all severities, schematic parity on) |
| `gerbers/` | The unzipped Gerber and drill files |

## Mains board (`eu_mains_board/`)

- Round, 57.9 mm across, notched for the box's four screw domes; 2 layers, FR-4, 1.6 mm.
- Copper weight: 2 oz recommended for the load paths (L / N pours carry the lights' current);
  confirm in the thermal review.
- **The outline has a routed relief slot under the PSU.** It is part of Edge.Cuts, not a drill: add
  "routed isolation slot in outline, do not omit" to the order remarks.
- Three Ø2.2 holes for the cap's long bosses (M2), no copper within 1.0 mm.
- Front (F): F1, RV1, J3 (SMD). Back (B): J1, J2 (WAGO 2604-3102), PS1 (Traco TMPS 03-105), THT.
- S1 (Marquardt 1802.2504) is **not fitted** by PCBWay: it snaps into the cap's cup first and is then
  soldered by hand.

## 5 V board (`eu_5v_board/`)

- D-shaped, 57.9 × 27.9 mm, notched round the domes and the mains board's boss; 2 layers, FR-4, 1.6 mm,
  1 oz.
- Front (F): C1, P1 (GND) and P2 (+5V) Harwin P70-2200045 SMT spring pins. Back (B): J1, Samtec
  SSW-102-01-L-S socket (THT) onto the mains board's TSM header.

## Review checklist (before ordering)

- [ ] Isolation targets on the mains board (L–N and L–L(switched) ≥ 3.5 mm, mains to the 5 V island
      ≥ 8.0 mm plus the slot) reviewed against IEC 60664-1 / 62368-1.
- [ ] Thermal review of the load paths; choose the copper weight.
- [ ] F1 T1A (Traco's recommended input fuse) against the branch circuit's prospective fault current
      (UMT 250 breaking capacity).
- [ ] WAGO 2604-3102 pin rows checked on a part (from WAGO's 3D model).
- [ ] Header / socket stack: TSM post 5.84 mm into the SSW socket (body 8.51 mm), 13.8 mm between the
      boards; 3.08 mm engagement as designed.
- [ ] Spring pin working height on a printed cap (6.4–7.2 mm, designed 6.8 ± 0.3).
- [ ] EU stack depth tried in a real 47 mm box (−43.2 mm deepest part).
- [ ] Approvals of S1, J1, J2, PS1, F1 and RV1 adequate for the installation.

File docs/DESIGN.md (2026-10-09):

# Design: requirements and decision log

## Context
- NA single-gang device boxes, 2" × 3" opening (≈50.8 × 76.2 mm).
- Every light socket has an IKEA Matter (Thread) smart bulb(s). Typically controlled by Home Assistant.

## Requirements
| ID | Requirement |
|----|---|
| R1 | Replace each light switch with a plate that holds an IKEA BILRESA scroll-wheel remote, flush/recessed. |
| R2 | mmWave presence sensing in every switch location. |
| R3 | Temperature + humidity in every location. |
| R4 | Emergency means to (a) turn lights on when Home Assistant is down and (b) de-power the circuit. Need not be easily accessible. |
| R5 | Emergency off must also de-power the presence sensor. |
| R6 | Keep the face plate as thin as practical. |
| R7 | Same electronics usable in EU/UK (250 VAC-rated parts). |
| R9 | No soldered or plugged connection between the face plate (trim) and the insert / cap: every electrical interface across that split is a spring ("pogo") contact, so the face plate lifts off and goes back on blind (human requirement 2026-10-08). |
| R10 | No wires and no soldering at assembly between any two boards or modules. 5 V, NA and EU: spring (pogo) contacts preferred; a flex with a latching connector, long enough to plug and unplug by hand with the latch in view, only where spring contacts cannot reach. Mains: house wiring and mains leads end in WAGO push-in terminals on the board, never soldered (human requirements 2026-10-08). |
| R8 | Printable on a hobby FDM printer (Elegoo Centauri Carbon 2 Combo, ElegooSlicer); PCB fab + THT assembly by PCBWay. |

## Decision log
| ID | Decision | Why / rejected alternatives |
|----|---|---|
| D-1 | No existing product does R1+R2+R4 → custom plate. | Inovelli Blue mmWave dimmer (Zigbee, smart-bulb mode) considered; has no humidity, no Bilresa mount. |
| D-2 | Don't design own mains switching electronics or put Li-ion cells in the box. | Certification (CEC approved-equipment requirement), heat, fire risk. |
| D-3 | Presence: Apollo MSR-2 (ESPHome, Wi-Fi) rather than Matter sensor. | Aqara FP300 too big (42×42×50) and battery-tuned; IKEA has no mmWave (MYGGSPRAY is PIR); Everything Presence Lite too big, no climate. HA is the controller, so ESPHome native API is fine/better. MSR-2 is 40×24×15 cased. |
| D-4 | Climate: SHT45 on MSR-2 I²C, thermally isolated bay at plate bottom. | MSR-2's DPS310 reads high from ESP32 heat (Apollo says so); IKEA TIMMERFLOTTE (70×70×30) too big. |
| D-5 | Keep BILRESA intact (batteries in), recessed in box, removable. | De-cased board option explored (I-beam PCB, encoder + tactile) but intact is simpler, stays usable as handheld. |
| D-6 | Emergency control = mechanical rocker in series with the load, hidden behind the remote. | Shelly relay dropped: all bulbs are smart, a relay adds nothing. Spring-carrier "push the remote" idea dropped once the switch could be hidden. |
| D-7 | PSU fed from the load side of the rocker. | R5. |
| D-8 | Bulbs' Matter power-on behaviour set to On. | Off→on of the rocker then turns lights on without HA (R4a). Must be verified per bulb. |
| D-9 | Rocker: Bulgin/Arcolectric C1300AABBEN602A (16 A 250 VAC, CSA/UL, 27.3×12.3 cutout). | R7. E-Switch RB141C1100 is 125 V only. Würth 471005264152 has ENEC/UL but no Canadian mark listed. ENEC on the Bulgin part still to be confirmed from datasheet. |
| D-10 | PSU: Mean Well IRM-03-5 (85–305 VAC, 5 V 600 mA, 37×24×15, cURus/CB/TÜV) on a carrier PCB with fuse + MOV. | Encapsulated, reputable, universal input (R7). Headroom for MSR-2 CO₂ variant. |
| D-11 | Low-voltage electronics in the plate, mains parts in the box; plate stands ~13 mm proud. | 50 mm box width can't hold remote + sensor side by side; puts sensors in room air; clean barrier. |
| D-12 | **v0.2 (done):** split into V-0 "box insert" (all barrier geometry) + "trim plate". | Face-down single-piece print needs supports in the pocket; limits flame-rated material to the part that needs it. |
| D-13 | Fix the v0.1 scoop leak: the region between the pocket shell and the collar is now **solid insert material**, and the scoops sit wholly inside the insert. | In v0.1 that region was hollow under a 2 mm face skin; the finger scoops (bottom at z = 8.5) cut through the skin, opening the mains side to the room. Found by the new barrier test in `checks.py`. |
| D-14 | Insert printed floor-down with no supports: thick floor down to the bed, 45° taper carrying the flange underside, flange underside chamfered outside a 1.25 mm flat seal band on the wall, PSU rails integral with a **gabled (45°) roof** over the PCB back instead of a flat bridge. | Every downward face is either on the bed, ≤ 45°, or a ≤ 2.3 mm ledge (checked). A separate screwed PSU cradle was considered; no room for screws that don't block the PCB or breach the floor. |
| D-15 | PSU carrier 42 × 44 mm (was 40 × 36), slides in from the bottom end of the rails, stops at a top end stop; the box wall keeps it in. | 37 mm IRM-03 + 2 mm rail keep-outs need ≥ 41 mm; J1/F1/RV1 and the isolation slot need the extra height. Top edge stays 4 mm under the rocker body. |
| D-16 | Trim–insert interface: the insert's island is flush with the face; the trim's face clamps the insert flange; both are held by the two #6-32 box screws; two asymmetric Ø3 pins key the orientation. | One screw set, no extra fasteners in the barrier, can't be assembled rotated. |
| D-17 | 5 V pass-through: vertical leg out of the box (room-right, J2 side) then 45° out through the flange into the trim hollow; carries the 5 V flex jumper (D-31). | Only barrier opening; the jumper never crosses the box rim below the wall plane. |
| D-18 | Insert material: **Elegoo PC-FR** (retailer listing: UL 94 V-0; Elegoo's data sheet states no UL94 class or thickness. Certification deferred: a spool with a stated V-0 rating is chosen before an installed build, human decision 2026-10-08 → `V0_RATED_T`). Stock "Elegoo PC-FR @ECC2" slicer profile, 6 walls. | Printable on the CC2 (280 °C), has a vendor profile. A filament's V-0 rating is for moulded bars; a printed part is not certified by it. |
| D-19 | F1 = T1A 250 V TR5 (Littelfuse 39211000000). **Designer's choice, needs human review.** | Mean Well's IRM-03 spec and PCB installation manual give no external fuse rating; inrush 20 A typ at 230 VAC (datasheet). |
| D-20 | PCB: all THT, one side, PCBWay turnkey. Isolation targets enforced as KiCad 9 netclass + custom DRC rules (clearance and `creepage`). | See `pcb/SPEC.md` (removed with the v0.2 carrier; in git history). Targets, not a compliance claim. |
| D-21 | BILRESA modelled as 45 × 70 mm with an R8.5 back round-over; pocket clearance `CLR` 0.6 → 0.5 mm. | IKEA UK lists the product at 45 × 70 × 20 mm; a third-party wall mount's pocket measures 45.4 × 70.4 with a quarter-circle back of R≈8.5. At 45 mm, `CLR` 0.6 put the pocket shell 0.1 mm outside the insert's box-clearance outline. Reference values until measured. |
| D-22 | The supplied adhesive magnet goes in a recess in the pocket floor, centred under the remote's flat back, 0.5 mm below the seat (`MAGNET_SETBACK`). | The remote carries a steel plate; the magnet ships separately for wall mounting. Recessing it keeps the seat flat. The setback gap weakens the pull without cutting the magnet; spacers or shims tune it. Replaces the v0.1 "steel target" recess, which assumed the reverse. |
| D-23 | **Wiring board:** the house cables (line, neutral, ground in and out) land on push-in terminals on the PCB; the rocker switches line on the board; the PSU is fed from the switched line on the same board. Line on one side, neutral on the other, ground copper along both sides. Copper may be 2–6 oz. Supersedes hard constraint 1 ("15 A never on the PCB"), lifted by the human on 2026-10-07. | No tool-free termination exists for the certified rocker: the screw-terminal Bulgin 6000 option could not be confirmed as made, and users should not solder or crimp pigtails. Removes wire nuts and the internal pigtail. Cost: the uncertified board now carries the branch circuit. |
| D-24 | **One board, OVC III (human decision 2026-10-07):** L/N/PE in and out on push-in terminals, rocker on the board in the line path, PSU fed from the switched side, 5 V side isolated; must fit a single-gang box no deeper than 2.5". Spacing targets: L–N and L or N to PE ≥3.5 mm, mains to 5 V ≥8.0 mm plus a routed slot (IEC 60664-1 Tables F.2/F.5: 4 kV basic 3.0 mm, 6 kV reinforced 5.5 mm, 320 V PD2 group III creepage 3.2 mm basic / 6.4 mm reinforced; EN/UL/CSA 62368-1 to be checked for anything stricter). The IRM-03 is rated OVC II, so the fuse + MOV ahead of it carry the OVC III surge duty. | Replaces the two-board concept: the single board fits once the terminals (back, middle) and PSU (back, bottom) no longer overlap and the 5 V connector is surface-mount on the front. |
| D-25 | Field wiring lands on one 6-pole WAGO 2604-1106 push-in lever block (PE, L in, L out, N in, N out, PE; 4 mm², 12 AWG, 5 mm pitch), wire entry parallel to the board, on the board's back. Its pin spacing is covered by its voltage rating; the D-24 spacings apply to the board copper around it. | Human decision 2026-10-07. Rated for the voltage at OVC III / PD2 (verify the exact rating on the WAGO datasheet), so separate 1-pole blocks are not needed. |
| D-26 | Rocker: **Marquardt 1802.2504** (DPST, PCB pins, drawing 1802.2504 rev g 2003-09-16): ENEC 12(4) A 250 V~, UL-recognized/CSA 15 A 125–250 VAC; 5.3 mm above the panel, PCB seat 16.2 mm below; holes 1.3 mm on 7 × 10.2 mm; cutout 19.4 × 21.9 (1.25–2 mm panel). Human decision 2026-10-07. | Stack 21.5 mm against 28.5 mm for the Marquardt 1552.2602 (16(4) A), leaving ~12 mm behind the terminal block in a 2.5" box instead of ~5 mm. 12 A EU rating is above the usual 10 A wall-switch rating; inspector to confirm. Pinout to be checked with a meter on a sample. |
| D-27 | **Sensor flex.** One single-layer flex in the trim connects the MSR-2 and the SHT45 and takes 5 V from the insert: plug end under the MSR-2 on its rear connector CN2 (stiffened, flex + stiffener + mated stack fit the 1.8 mm behind the board), out through the bay frame, up the top-right corner to just under the face skin, down the right channel (X 34.8-38.8, leaving a 1.2 mm strip along the flange face for the 5 V jumper), along the bottom to the SHT45 bay, the SHT45 soldered on the flex tail under the vents. Signals: 5V, GND, 3V3, SDA = IO1, SCL = IO0 (Apollo pinout + ESPHome config). CN2: 0.4 mm pitch, 2 rows, ~26-30 contacts (measured from Apollo photos, scale from the board in the same plane); P4S / SlimStack / DF40 class; exact part and contact map open. Power contact: two Harwin S7081-42R SMT spring fingers (+5 V, GND; gold contact, 4 A, recommended working height 2.10 mm, minimum 1.70, free 2.30; drawing S7081-42R iss. 7) on the stiffened flex underside, working at 2.0 ± 0.2 mm on the gold pads of the 5 V jumper's stiffened end (0.6 mm, D-31), which lies on a shelf off the flange's right face (flat underside at z 7.0, where the flange is solid to its face, 2.8 mm wide, then 45° to the edge: prints unsupported). The MSR-2 is powered through CN2's 5V (human confirmed 2026-10-07). The flex is single-layer: each 90° corner of the route is a 45° fold, which turns the strip over, so the plug, fingers and SHT45 all sit on the copper side and the flat pattern is one straight strip (`pcb/sensor/`). | Replaces the sensor-board + pogo + breakout concept: one part, nothing to unplug when the trim comes off, and the flex fits the 1.8 mm behind the MSR-2 where a rigid board with Apollo's GPIO add-on (8.5 mm header) does not. Mill-Max 0907 / 825 pins dropped: their 6.5 mm height puts the target below the printable part of the flange (45° chamfer below z 6.8, printed floor-down); spring fingers need ~2 mm. |
| D-28 | **Board mounting: screw-in snap posts.** Four PC-FR posts screw into bosses on the insert's underside and snap through Ø2.6 holes near the board's corners (top right lowered to clear the 5 V pass-through). Bosses stand on the insert's print-bed plane; their blind holes are printed at M4 tap-drill size (Ø3.3, 7 mm + 45° cone tip) and tapped M4 × 0.7; the posts' studs are printed at Ø4.0 and cut with an M4 die. Post: stud, hex collar, Ø4.5 shoulder under the board's front face, Ø2.3 shaft, split Ø3.2 cone head over the back face; printed lying on a flat. All four board holes are unplated, with a 2.75 mm copper keep-out on both layers; the PE ring detours round MH1 and MH3 and is interrupted at MH2, so PE continuity (checked on F.Cu alone, no vias) never depends on copper under a post (human request 2026-10-08). | Edge arms needed space the box doesn't have; posts grown from the insert would have to be printed with supports under the whole floor and their snap heads across the layers; a separate frame would be flimsy. Screw-in posts keep the insert support-free, print the snap prongs along the layers, and a broken post is replaced alone. The top-right boss rises into the pocket corner under the remote's back round-over for a full thread (checked against the remote with `CLR`). |
| D-29 | **Microphone: push-to-talk voice to Home Assistant** (human decision 2026-10-08). PUI Audio DMM-4026-B-I2S-R (I²S, bottom port, 4.00 × 3.00 × 1.00 mm, 1.62–3.63 V) on the sensor flex's underside in the right channel at y 40.75, on a section widened towards the flange (where the flange corner rounds away). The port faces the face skin through a Ø0.5 hole in flex + stiffener, an adhesive gasket ring and a Ø1.0 sound hole through the skin. I²S on MSR-2 GPIOs SCK = IO4, WS = IO6, SD = IO7 (free on CN2; IO18/IO19 are the USB pins, IO2 a strapping pin); LR and CONFIG to GND (left channel), 100 nF, 100 kΩ SD pull-down per the datasheet. The mic has its own GND and 3.3 V contacts on CN2 (nets MIC_GND, MIC_3V3) so its lanes don't cross the others on the single layer. Listening starts from Home Assistant (e.g. a BILRESA button) via an ESPHome action calling `voice_assistant.start`; no on-device wake word, no speaker. | The ESP32-C3 on the MSR-2 has one I²S peripheral and no PSRAM; ESPHome supports PDM mics only on ESP32/ESP32-S3, and warns audio components use much RAM/CPU, so streaming only on demand is the realistic load. Rejected: ICS-43434 (TDK: EOL), SPH0645LM4H-B (DigiKey: obsolete), T5848 (1.62–1.98 V, needs a 1.8 V rail and level shifting), MSM261S4030H0R (top port: would have to sit on the SHT45 tail, 150 mm of flex from the MSR-2). Server-side wake word = continuous streaming; an S3-based voice board = a new board. |
| D-30 | **EU variant (concept, in progress; the push-button and single PSU board below are replaced by D-36)**: a design of its own for a round DIN 49073 flush box (68 mm hole saw, Ø60 inside), neutral assumed present, in `cad/build123d/eu/` (`make eu`). Shares only the BILRESA, the MSR-2, the SHT45 and the microphone with the NA plate (human decision 2026-10-08). The remote sits on a 1.6 mm V-0 cap floor over the box, centred on it, top flush with the face: plate 79.7 × 122.4 mm, 21.6 mm proud. The cap is the whole barrier: floor, a cup under the remote's upper half holding a latching DPST push-button (Marquardt 1684.1101, 16(4) A 250 VAC, ENEC/UL/CSA, 4.8 mm tabs), two holes for the spring pins (below); two countersunk screws into the box's top and bottom dome pair, in the pocket floor under the remote; the PSU board is notched round all four screw domes, which the checks model as obstacles. The push-button is hidden until the remote is lifted out. The supplied magnet is glued under the floor (box side). A D-shaped board (`pcb/eu/`, ERC/DRC clean) 6 mm behind the floor carries the PSU (Traco TMPS 03-105, D-32) on its back and fuse, MOV, capacitor on its front, held by two M2 screws in cap bosses; it carries only the PSU's current; L_SW from the push-button and N from the house neutral end in a WAGO 2604-3102 push-in block on its back (400 V III/2, conductors enter from the back of the box), no soldered leads (D-32). The sensor flex follows the NA topology in the trim's right channel (MSR-2 CN2, mic with its sound hole, SHT45 under its vents); two SMT spring pins on the PSU board's front (Harwin P70-2200045, 2 A, working height 6.4–7.2 mm, designed at 6.8 ± 0.3) stand through two Ø1.9 holes in the cap and press on gold pads on the flex where it dips in the channel, backed by a rib in the trim: no lead, no target board, no solder joint across (R9, R10). The pin barrels fill the holes (0.18 mm radial gap); the barrier check treats the holes as plugged by the pins. The PETG trim carries the face, pocket walls, 45° finger notches, MSR-2 and SHT45 bays, held by two M2 screws under the remote's rounded back edge. Deepest part −27.8 mm (the WAGO block): 19.2 mm free in a 47 mm box. | The remote cannot go below the wall in a Ø60 box (its flat back alone spans ~Ø60), so the plate is at least the remote's height plus the barrier floor; the magnet under the floor saves 2 mm (holding force to be tested). One piece with the floor and the cup would need supports either way up, hence the flat cap + trim split. Open: the push-button's 4.8 mm tabs take crimped receptacle leads (no PCB-mount latching DPST at 16 A 250 VAC found); push-button dimensions above / below the panel (MEASURE), magnet holding force through the floor, trim tab clearance against the remote's real back shape, KiCad EU sensor flex, fab files, box dimensions (MEASURE). |
| D-31 | **5 V flex jumper (NA).** The 5 V lead and the target board are replaced by one single-layer flex (`pcb/sensor/`, `cad/build123d/jumper.py`): a stiffened 6-contact end plugs into J2 on the wiring board (Hirose FH12-6S-0.5SH(55), 0.5 mm, slide lock; contacts 1–3 GND, 4–6 +5 V), the strip (3.0 mm wide) runs through a 40 mm Z-fold service loop between board and insert, up the pass-through (the 3.5 × 0.3 end threads the Ø4.5 hole) and out of the flange, and ends in a stiffened pad end (0.6 mm) on the insert shelf under the sensor flex's spring fingers. 156 mm flat. Plugged with the board held beside the insert, latch in view. Connector-end dimensions MEASURE (Hirose FPC drawing). | R10 (human requirement 2026-10-08). Spring pins board-to-flex are not possible on the NA plate: the board's front is about 37 mm behind the flange and the only route is the 45° pass-through, so pogo was the first choice and the human's second choice, a flex plus a snap connector, is used. The service loop sets the length: a 1-2 mm FPC latch needs room for fingers and eyes. |
| D-32 | **EU PSU and mains terminal (board split by D-36).** The IRM-03-5 (37 × 24 mm) is replaced on the EU board by a Traco TMPS 03-105 (25.4 × 25.4 × 16.3 mm, 5 V 600 mA, 780 mA peak 30 s; IEC/UL 62368-1, IEC 60335-1, CB, cURus; OVC II, PD2, reinforced, 3 kVAC; datasheet rev. 2026-07-01), which frees room for a WAGO 2604-3102 (12.4 × 16.7 × 21.3 mm, 2-pole, 4 mm², conductor entry 90° to the PCB, 400 V III/2, 32 A) beside it on the back. L on F.Cu, N on B.Cu. The soldered L_SW / N leads are gone (R10). | Human decision 2026-10-08 (shrink the PSU). A 2604 does not fit next to the IRM-03 in the Ø60 box; the smaller WAGO 2601 is rated 160 V at OVC III / PD2, below hard constraint 3. The 90° entry takes the house wires straight from the back of the box, where the round box has room; a 0° entry would point the wires at the box wall. |
| D-33 | **3.3 V rail for a battery-free BILRESA (EU board, first step). Superseded by D-35: the regulator moves to the face plate side, off the PSU board.** TI TLV75533PDBV (3.3 V, 500 mA, SOT-23-5) on the 5 V side with 1 µF in and out (TLV755P datasheet), net +3V3. Target: an insert version where the remote rests without batteries and back cover, powered on its battery contacts by spring pins (not placed yet). The IKEA manual (AA-2675003-2) gives 2 × AAA HR03 and recommends LADDA HR03 rechargeables (NiMH, 2.4 V nominal): 3.3 V is above that and near fresh alkaline cells. zigbee2mqtt (E2490 page) reports the remote's battery percentage as tuned for 1.5 V alkaline cells, i.e. a 3.0-3.2 V pack, and the remote reports its supply voltage in mV, so the voltage it sees can be read back. | Human decision 2026-10-08 (3.3 V rather than ~2.7 V). An LDO from 5 V keeps the certified AC-DC module unchanged; no 1 x 1 in certified module with 5 V + 3.3 V outputs was found. FCC ID FHO-E2490 internal photos: the cells are in series (strap at the radio-module end, GND / P1 terminals at the system-button end); the battery contacts face along the cell axis, so a spring pin square to the remote's back cannot press on them directly: a printed dummy-cell pair carrying the 3.3 V to the terminal contacts is the likely interface. Open: battery-contact positions (approx. in MEASUREMENTS) and spring travel, the remote's sleep and peak current, its response to 3.3 V (low-battery indication), the NA board's 3.3 V. |
| D-34 | **Dummy-cell insert (BILRESA E2490, first design). Superseded by D-35 (code removed).** A printed part replaces the remote's back cover and both AAA cells (`cad/build123d/dummy.py`): the remote's outline up to the parting line with a flat back (45° edge chamfer) and two D-shaped dummy cells (Ø10.3; dummy + stiffener + flex = 44.5, the AAA maximum). A single-layer flex (`pcb/sensor/` cell_flex) lies copper-down in a recess on the back with two gold pads 0.3 mm above the back face (+3V3, GND at (15, 2.8) and (15, −1.2), over the EU board's free SELV area at the EU spring pins' working height), runs to the terminal end, bends up once through a slot and stands against the dummy cells' end faces on a 0.4 mm FR4 stiffener, copper outwards: 6 × 6 mm gold pads on each cell axis meet the remote's VBAT (P1) and GND (P2) contacts; between the cells only a 2 mm band passes under the remote's PCB strip. The bridge-end contacts touch plastic (the remote's strap needs no current). The remote's steel plate moves into a pocket in the insert between the cells (0.4 mm under it). | No wires, no solder at assembly (R10); one bend, copper on the right side at both ends. Positions are REF from the FCC internal photos or MEASURE (cell axis height, PCB strip, steel plate, latch features), so the flex has no fab files (`CELL_CONFIRMED`). Open: how the insert clips to the remote (the cover's latches, MEASURE), the EU cap holes and pins for +3V3 / GND (two barrier openings: human approval), E2489 version. |
| D-35 | **Replacement back cover (BILRESA E2490).** A printed cover (`cad/build123d/backcover.py`) replaces the remote's back cover: the remote's back shape (below the round-over's 45° point filled out to its 45° tangent so it prints back down without supports) and the remote's steel plate in a pocket (0.4 mm wall under it). Inside, a single-layer flex (`pcb/sensor/` cover_flex) lies copper down on a ledge 2.0 mm above the back face; two Harwin S7081-42R spring fingers on it (free 2.30, working 2.0 ± 0.2, ≥ 1.2 N at 2.10, 4 A, 1000 cycles; drawing S7081-42R iss. 7) reach through windows onto the plate's floor pads. The flex runs (3 mm strip, slot under the GND contact block) to the terminal end, bends up once and stands on a 0.4 mm FR4 stiffener against two contact blocks: S7081-42R spring fingers on the cell axes press on the remote's VBAT (P1) and GND (P2) battery contacts (D-40); no dummy cells. On the face plate side a 0.6 mm printed pocket-floor insert (`eu/floor_eu.py`, bonded to the trim, openings over the push-button and round the trim tabs) carries a tongue of the sensor flex in a recess, its 4 × 7 mm gold pads flush; the tongue enters under the right pocket wall (notch) and folds 45° once so its copper faces up. The magnet holds the cover's back on the insert: that hard stop sets the fingers' working height. The 3.3 V regulator goes on the cover flex (D-41). EU plate +0.6 mm (remote seat on the insert). | Spring contact on the removable cover, flat wipeable pads in the plate (human: pad to pad is not reliable); no new openings in the barrier (D-34's pins would have needed two, exposed under the remote). Open: cover latches, steel plate, cell axis height, contact positions (MEASURE / REF), magnet hold vs. 2 fingers through 2.6 mm (cap + floor + cover wall), NA pocket (follows the original curve; the cover's 45° fill does not fit it), EU sensor flex KiCad layout with the tongue and regulator, E2489 version. |
| D-36 | **EU: two boards, PCB rocker.** The latching push-button and the single PSU board are replaced. The emergency rocker is the NA part (Marquardt 1802.2504, PCB pins, D-26), its panel in the cap's cup under the remote (SW_Y 12.5; the back cover's steel plate and the magnet move to y −8, clear of the cup). Mains board, round, at the rocker's PCB seat (front −20.3): rocker, two WAGO 2604-3102 blocks (L in / switched, N in / switched, wires from the back of the box), F1, RV1, TMPS 03-105 on the back over a routed relief slot; L pours on F.Cu, N pours on B.Cu, ≥ 3.5 mm between any two mains nets; the PSU's outputs land on the 5 V island below the slot, with a 2-pin header. 5 V board, just under the cap (as the old board): pin socket on the header (13.8 mm stack, 3.2 mm engagement), C1, the two P70 spring pins to the flex. Three long V-0 cap bosses carry the mains board (two beside the cup, one through the 5 V board). | Human request 2026-10-08: the single board had no relief slot and carried 230 V and 5 V side by side, and the push-button needed leads; the rocker on PCB pins removes them, and the only 5 V copper on the mains board is the island behind the slot. Depth: the stack reaches −43.2 mm, 3.8 mm short of 47 mm box; to be tried in a box before changing (human decision 2026-10-08), a 61 mm Elektronikdose leaves 18 mm. Open: load-path copper sizing (2 oz), header / socket engagement with the parts, PE joined in the box. |
| D-37 | **NA J1 re-laid from WAGO's 3D model.** The 2604-1106 has its two solder-pin rows 8.2 mm apart (not 5.0 as inferred from the 2601), the first row 5.0 behind the entry face, the second 2.9 inside the closed back; body 16.1 mm deep at the board, the levers overhang the entry side up top (≥ 13.9 mm above the board past the S1 pads). J1 moves to pin rows y 8.1 / −0.1 (centre at the board y 5.05), pads round 2.2 mm (drill 1.3), the pours reach both rows, the PE ring notch inner edge moves to y −8.9, the N_SW feed under J1 is 0.5 mm at y −5.0 (PSU current, behind F1). J1's closed back is 6.4 mm from the PSU; its entry face 0.2 mm short of the S1 pads. ERC / DRC clean; WAGO's model is the J1 3D model (kept in scratch/). | Human decision 2026-10-08 (re-lay the NA board). The old footprint would not take the part. Cost: the pours beside J1's pads narrow to 1.3–1.8 mm (were 2.4–2.9), for the thermal review. |
| D-38 | **Through-hole pads clear of bodies on the other side; EU WAGO from WAGO's 3D model.** Every through-hole pad keeps its edge `PAD_BODY_GAP` = 1.0 mm from the fab outline of any part on the other side of the board (pin tail, solder fillet, iron); `make check` / `make eu` check it on the KiCad files. NA: rocker S1 moves to y 19.5 (was 18.0; its body sat 0.5 mm over J1's first pin row), J2 to y −19.5 (PS1.5 was 0.95 mm from it). EU: the 2604-3102 has its pin rows 8.2 mm apart, 0.65 mm off the body centre towards the entries; footprint, round 2.2 mm pads and the vendor 3D model follow it; blocks at x ±16.6, y 7.5 with the levers towards the centre (J1 turned 180° from J2), the in / switched pour split steps from the rocker's poles to the blocks', F1 at y −3.0. | Human observation 2026-10-08: the rocker sat on the WAGO pins. EU J3 header pins under the PSU body: see D-39. |
| D-39 | **Rocker footprint centred on the body; combined rocker 3D model; EU 5 V board kept, SMT header.** Drawing 1802.2504 rev g puts pins 1 / 2 on the body's centre line and 1a / 2a 7 mm off it; the footprint had the body centred on the 7 mm grid (3.5 mm off the panel opening). Footprint origin = body centre (SW_Y in params); `SW_SW_DIR`: NA switched pins 7 mm above (in pins at 19.5, switched at 26.5, pours extended), EU 7 mm below (in 12.5, switched 5.5). 3D model: the 1802.1108 housing (Marquardt LIB_1802.1108: same flange 21 × 24, rocker 5.3, body 22 wide, terminals on the same 10.2 × 7.05 grid, but solder lugs and no PCB seat) above its body bottom, on the 1802.2504 underside from its drawing. EU: the 5 V board stays; J3 becomes a Samtec TSM-102-01-L-SV SMT header (insulator 2.54, post 5.84, 4.7 A per pin with SSW; datasheet F-226), 3.08 mm into the socket. | Human decisions 2026-10-08: build the combined model; remove the 5 V board only if it is easier. Board-mount spring pins top out near 10 mm (Mill-Max 3 mm stroke series 9.6 mm, SMT 807 series 8.5 mm); the 22.2 mm span from the mains board to the flex would need test-fixture probes in receptacles, and the 13.8 mm between the boards is too long for a spring pin, so header / socket stay. |
| D-40 | **Back cover: spring fingers on the battery contacts.** The E2490 has, at each end of the compartment, one leaf spring (− side) and one fixed plate with a dimple set in a pocket in the end wall (+ side; FCC FHO-E2490 internal photo 1), so at the terminal end only GND springs back; VBAT is a fixed plate. The cover flex's 6 × 6 mm pads are replaced by two Harwin S7081-42R (J3 VBAT, J4 GND) on the cell axes, long axis across x; the end section stands FINGER_WH (2.0 mm) in from the plate (`BC_COPPER_Y`; plate setback `BC_TERM_SETBACK` MEASURE, 0 for now), so J3 works at 2.0 mm on the plate and J4 shares the travel with the leaf spring. One flat end section, one bend, as before. | Human observation 2026-10-08 (one terminal is recessed and needs a spring); human decision: S7081 at VBAT. A flat GND pad on the same end section would meet the leaf spring 2 mm before the cell end plane, with little or no preload, so GND gets a finger too; it also works whichever side turns out to be the fixed one. Open: plate setback and pocket opening, leaf spring travel (MEASUREMENTS). |
| D-41 | **Battery-free remote on NA and EU.** The 3.3 V regulator moves to the replacement back cover's flex (TI TLV75533PDBVR, SOT-23-5, 1 µF in / out, TLV755P datasheet; copper down in a recess in the cover, 0.4 mm wall left), so the plate brings +5 V and GND to the floor pads on both variants (supersedes D-35's regulator on the sensor flex). Cover fingers at (14, 4.0) +5V and (14, −5.0) GND (moved 0.5 mm down so the NA floor strip clears the switch well's opening). End fingers stand vertical, bend end up: the battery contacts ride down the arm's ramp onto the dome as the cover goes on. NA: a printed floor insert (`floor_na.py`, 0.6 mm, openings over the switch well and the corner board-post boss) raises the remote 0.6 mm (face 2.6 mm proud); the 5 V jumper becomes a 2-layer flex (0.2 mm) whose pad end grows a tongue between its two contact pads (y 18.65): through a 2.8 mm tunnel in the insert flange at the pad end's height, down a 0.4 mm groove in the pocket wall (the stadium's curved end, wall position computed) to z 0.5, down the wall into the floor's recess, then to two 7 × 4 mm pads under the fingers; copper stays up after the two bends. Tunnel and groove lie wholly above the wall plane, between the trim hollow and the remote pocket (both low voltage); the mains-air check passes. EU: the floor insert and the tongue from the sensor flex's pin pads already exist in CAD (`floor_eu.py`, `sensor_eu.py`), carrying +5V / GND. | Human decisions 2026-10-08: battery-free on both variants; allow a slot above the wall plane (AGENTS hard constraint 2 wording updated); end contacts with the ramp into the remote. On one copper layer the jumper's GND edge lane cuts +5V off from any tongue on the inner edge (and the sensor flex has no +5V past its fingers), hence two layers. Open: the EU sensor flex has no KiCad layout yet (tongue included), jumper stack-up thickness, plate setback / leaf spring travel (MEASUREMENTS), magnet hold through floor + cover (90 % of the NA magnet over the cover's steel). |
| D-42 | **EU sensor flex in KiCad; estimates from photos.** `pcb/sensor/kicad/eu_sensor_flex` (`eu_flex_parts.py`): the NA topology on the EU route (plug, fold 1, mic on the outer side, dip to the spring-pin pads, fold 2, SHT45), single layer, ERC / DRC clean; fab files withheld with the CN2 placeholder. The battery-free tongue leaves the pad section between the pin pads; to need no crossing after its 45° fold the spring pins swap (P1 GND above, P2 +5V below; C1 on the 5 V board turned) and the plug brings GND out twice (GND, GND_SHT). EU floor pads x 13.5–16.3 (clear of the switch cup's opening), tongue at y −6.8 between the pins (trim notch moved), fold at x 17.6. Back cover fingers at x 14.4 (strip to x 16.5 for the estimated back curve), steel plate at y −5.5; NA magnet recess at y −1.0 (`MAGNET_REC_Y`, over the remote's own plate and the cover's steel), EU magnet derived (clear of the cup). `ESTIMATE` values from the FCC photos, the IKEA label drawings (1:1) and the IKEA product page (MEASUREMENTS) replace placeholders for the remote's outline details, seam, wheel, LEDs, steel plate, cell axes. | Human request 2026-10-08: estimates from pictures, finish the EU version. Open: the supplied magnet looks ~47 × 17.5 mm (drawing), too long for the space under the remote (decision); BC_TERM_SETBACK, BC_BRIDGE_H, leaf spring travel stay MEASURE; CN2 part. |
| D-43 | **Supplied magnet cut to length.** The BILRESA's magnet (~47.4 × 17.5 mm, full round ends, ESTIMATE from the label drawing) is cut once across by the user: an 18.5 mm piece from one round end. NA: in the insert's recess from y −13.0 (round end, in the recess's round end) to +5.5 (cut edge, SEAT_T clear of the switch well), 82 % under the remote's own steel plate (battery use) and 93 % under the back cover's. EU: the same piece under the cap, cut edge 0.5 below the switch cup, 79 % under the cover's steel. | Human decision 2026-10-08. Open: the real magnet size and thickness, pull test. |
| D-44 | **Back cover snap clips, side ribs, plate clips.** As the original cover (human photos IMG_5088-5090 and measurements 2026-10-09): cover 9.8 mm rim to back, 1.6 mm shell; snap clips at the top and bottom ends (x 0), 3.5 × 1.2 mm, from a ledge on the end wall up past the rim into the housing, 0.5 mm hook outwards, the bottom one at the flat-blade pry notch in the rim; free-standing ribs at mid-length on the curved floor, 36.1 mm apart inside, rising past the rim (stiffening, no hook); the plate in the cover (a magnet, 12 × 20 × 2) held by a clip at each end of its pocket. All print back down without supports. | Human corrections 2026-10-09. Open: clip and rib rise, hook size, pry notch size (MEASURE). |
| D-45 | **Every part held.** Review 2026-10-09 found loose parts; now: MSR-2 board by two snap hooks at its short ends hanging from the radar skin (0.5 mm lip over its back face, a relief in the bay frame behind each so it flexes; NA and EU trims); the back cover's flex by a 0.3 mm FR4 stiffener on its pad and regulator sections and two printed pegs heat-staked through it (between the fingers, above the +5V finger), its end section by a lip at each contact block's foot and a hook on each block's top; the 5 V jumper's pad end by a stop at the shelf's lower end plus tape; tape (3M 467MP) at named points for the light parts (sensor-flex stiffeners, SHT45 tail, NA floor insert, tongues). Inventory in docs/ASSEMBLY.md. | Human review 2026-10-09 ("the more I look the more parts I find that aren't secured"); mechanical holds where a spring loads the part, tape where nothing does. Open: MSR-2 board thickness and edge clearances, hook feel on a print. |

## Known risks / to verify
- Metal boxes: ears may collide with the pocket; BILRESA Thread signal may drop when recessed.
- Neutral may be missing in switch-loop boxes → PSU can't be fed there.
- BILRESA scroll wheel reportedly laggy/flaky over Matter in HA; test before scaling.
- Concealed emergency switch vs. code expectation of a wall switch: ask inspector.
- Plate is 82 × 150 mm (larger than standard); may shrink once the bare MSR-2 is measured.
- The insert reaches z = −12.8 (rocker panel) with a 45° corner taper to −10 mm, and the wiring board with the WAGO block and PSU sits behind it: include both in the box-fill calculation. The taper reaches into the box's opening corners; check against your box ears / device-screw bosses.
- The rocker body closes the panel cutout and is part of the barrier: never energise with the rocker removed.
- Board posts (D-28) are tapped and die-cut by hand: cut the threads square and clear the chips before fitting.
- Elegoo PC-FR V-0 rating thickness unknown until the datasheet is on file.
- Microphone (D-29): the DMM-4026 needs a bit clock of 2.048–4.096 MHz (below that it sleeps), so
  sample at ≥ 32 kHz (BCLK = 64 × fs; 48 kHz gives the datasheet's 3.072 MHz). Whether the C3 runs
  the voice pipeline at that rate alongside the radar, Wi-Fi and BLE is untested.
- Microphone pin 1 orientation is read from the datasheet's bottom view (mirrored for the top-view
  footprint): check against a part before ordering the flex.
- IO4 / IO6 / IO7 as free GPIOs on CN2 come from the GPIO add-on's listing; confirm with the CN2
  map (D-27).
- A microphone in every room: listening is on demand only, but the device can stream audio.

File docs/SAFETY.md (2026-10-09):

# Safety rules (humans and agents)

This device puts home-built parts in a mains wall box. Nothing in this repo is
certified, and nothing here makes it code-compliant. Treat every rule below as a
hard requirement.

## Electrical
1. Breaker off and verified dead (non-contact tester + meter) before opening any box.
2. The lighting load (up to 15 A) is switched by the certified rocker only. Line,
   neutral and ground pass through the wiring PCB via listed push-in terminals
   (D-23). That board is not certified: it is the part an inspector is most likely
   to question.
3. Mains-side parts must carry recognised marks: rocker (CSA/cUL; ENEC for EU/UK),
   IRM-03-5 (cURus/CB/TÜV), terminal block, fuse, MOV.
4. The 5 V flex jumper runs from inside the box to the plate, through the single
   collar hole. It is not a rated wire: polyimide base and coverlay, copper exposed
   only at its two ends (J2 on the board's 5 V side, the pads on the shelf outside
   the box). Its distance to mains-side parts along its route, and whether the
   film is sufficient insulation where it passes them, are open for human review.
5. Bond grounds per local code. The printed plate is non-conductive and is not grounded.
6. Box fill must be calculated with the insert, the rocker body and the wiring board
   (terminal block, PSU) counted.
7. The rocker breaks line and neutral of the lighting load; the line feed and ground
   stay connected on the board. Use the breaker for work on fixtures.

## Mechanical / material
8. Barrier geometry (pocket shell, switch well, collar; the box insert) is
   printed in a UL94 V-0 filament with its datasheet on file. PLA/PETG are for
   test fits only.
9. No holes may be added to the barrier other than the 5 V pass-through. The rocker
   panel cutout is closed by the rocker body itself: never energise with the rocker out.
   `make check` runs a barrier-continuity test (mains air must not reach the pocket,
   trim hollow or room); it must pass.

## Regulatory (BC, Canada)
10. Work under a homeowner electrical permit; ask the inspector about the concealed
    emergency switch and the uncertified assembly before installing more than one.
11. Expect questions from your insurer about non-approved equipment.
12. EU/UK: local rules differ (e.g. England Part P). Check before building there.

## For AI agents
- Don't claim compliance, safety, or code approval. Report what was checked.
- Don't relax constraints 2, 8, 9 or the PCB creepage targets to make something fit;
  stop and ask.

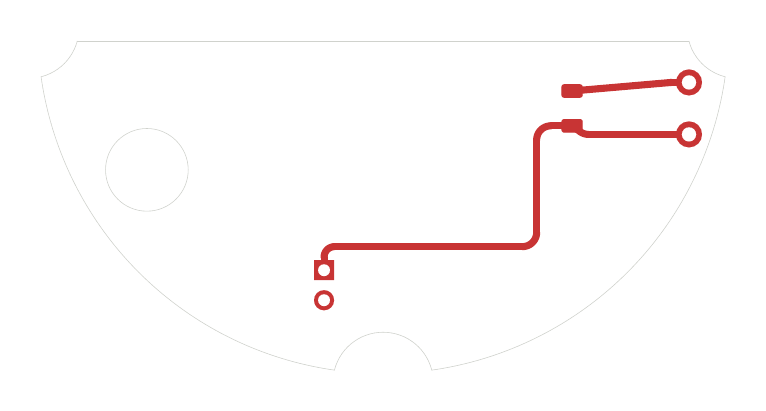
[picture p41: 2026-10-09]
docs/renders/eu_5v_board_copper_front.png

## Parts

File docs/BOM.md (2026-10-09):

# Bill of materials (per plate)

Prices/stock as seen Oct 2026; re-check. Bold = safety-critical, don't substitute without review.

| Ref | Part | MPN / source | Notes |
|-----|---|---|---|
| — | IKEA BILRESA remote, scroll wheel | IKEA 906.174.56 (white) | Kept intact, 2×AAA. Remove nothing. |
| — | Adhesive magnet | supplied with the BILRESA | Glued into the recess in the pocket floor. Cut to size. |
| S1 | **Rocker DPST, PCB pins** | **Marquardt 1802.2504** (drawing 1802.2504 rev g) | ENEC 12(4) A 250 V~; UL-recognized/CSA 15 A 125–250 VAC; cutout 19.4 × 21.9 (1.25–2 mm panel); 5.3 mm above the panel, PCB seat 16.2 mm below. Pinout to be checked with a meter (D-26). |
| J1 | **Terminal block, push-in lever, 6-pole, 5 mm, 4 mm² / 12 AWG** | **WAGO 2604-1106** | L/N/PE in and out; 400 V (III/2). On the board's back, wire entries face the top edge. |
| PS1 | **AC-DC 5 V 600 mA** | **Mean Well IRM-03-5** (DigiKey 1866-3020-ND) | 85–305 VAC, 37×24×15 mm, on the board's back. |
| F1 | **Fuse T1A 250 VAC, SMD** | **Schurter UMT 250 3404.2416.22** | Rating is the designer's choice (Mean Well gives none); 200 A breaking capacity: human review. |
| RV1 | **Varistor 275 VAC, SMD** | **TDK B72660M0271K093** (CU4032K275G2) | Covers 120 V and 230 V. |
| C1 | 22 µF 10 V X5R 1206 | Murata GRM31CR61A226KE19L or equiv. | 5 V output. |
| J2 | FPC connector, 6 contacts, 0.5 mm, SMD, slide lock | Hirose FH12-6S-0.5SH(55) | 5 V out to the flex jumper (1–3 = GND, 4–6 = +5 V). |
| PCB | Wiring board 47 × 72 mm, 2-layer 1.6 mm | PCBWay; order pack in `pcb/fab/` | Routed isolation slot in the outline. S1 is soldered by hand after it is snapped into the insert. Copper weight: thermal review. |
| — | Apollo MSR-2 mmWave multisensor | apolloautomation.com / The Pi Hut | ESP32-C3, LD2410B, DPS310, LTR-390; optional SCD-40. Used out of case. |
| U? | SHT45 | Sensirion SHT45 (DFN-4 1.5 × 1.5) | Soldered on the sensor flex tail, I²C from the MSR-2 (D-27). |
| — | Sensor flex | PCBWay flex, single layer, 0.12 mm, FR4 stiffeners 0.15 mm; `pcb/sensor/` | D-27: MSR-2 CN2 → spring fingers → SHT45 on the tail. Not orderable until CN2 is confirmed. |
| — | CN2 mating plug | TBD (0.4 mm, 2 rows; part open) | D-27; confirm from the GPIO add-on's plug or Apollo. |
| MK1 | I²S MEMS microphone, bottom port, 4 × 3 × 1 mm | PUI Audio DMM-4026-B-I2S-R | D-29: on the sensor flex, port through flex + stiffener (Ø0.5) to the face skin's Ø1.0 sound hole. |
| C2, R1 | 100 nF X7R 0402; 100 kΩ 1 % 0402 | any | D-29: mic decoupling; I²S SD pull-down (datasheet). |
| — | Mic gasket: double-sided adhesive ring OD 2.6, ID 1.0, 0.15 mm | die-cut | D-29: seals the mic stiffener to the face skin around the sound hole. |
| — | SMT spring fingers ×2 | **Harwin S7081-42R** (gold, 4 A) | D-27: on the sensor flex, +5 V and GND, working height 2.0 mm. |
| — | 5 V jumper: flex, two layers, 0.2 mm, 156 mm + battery-free tongue (D-41), stiffened ends (PI 0.3 mm total at the plug, FR4 0.6 mm total at the pads), ENIG | PCBWay; `pcb/sensor/fab/power_jumper/` | D-27, R9: plugs into J2 (FH12-6S, slide lock) → pass-through → pad end on the insert shelf under the spring fingers. No wires, no soldering at assembly. |
| — | Replacement back cover (BILRESA E2490): printed cover + single-layer flex with 0.4 mm FR4 stiffener, ENIG; the remote's own steel plate | printed; PCBWay flex, `pcb/sensor/` cover_flex (no fab files yet) | D-35: replaces the remote's back cover; no cells. |
| — | SMT spring fingers ×4 (back cover) | **Harwin S7081-42R** | D-35, D-40: on the cover flex, +5V and GND onto the floor pads; VBAT and GND onto the remote's battery contacts. |
| U1 (cover flex) | LDO 3.3 V 500 mA, SOT-23-5 | **TI TLV75533PDBVR** | D-41: the remote's 3.3 V from the floor's +5 V, on the cover flex. Datasheet: https://www.ti.com/lit/ds/symlink/tlv755p.pdf |
| C3, C4 (cover flex) | 1 µF 10 V X5R 0402 | Murata GRM155R61A105KE15D | LDO input / output (TLV755P: ≥ 1 µF). |
| — | Pocket-floor insert (EU): printed 0.6 mm floor, bonded to the trim | printed | D-35: carries the sensor-flex tongue with two flush gold pads. |
| — | Double-sided tape, 0.06 mm | 3M 467MP | D-45: tape points in docs/ASSEMBLY.md (jumper pad end, tongues, NA floor insert, sensor-flex stiffeners, SHT45 tail). |
| — | Cover flex stiffener, FR4 0.3 mm, with two Ø1.4 holes | PCBWay (with the cover flex) | D-45: on the pad and regulator sections; the cover's pegs are heat-staked through it. |
| — | Supplied BILRESA magnet, cut | (ships with the remote) | D-43: cut once across to an 18.5 mm piece from one round end (~47.4 × 17.5 magnet, ESTIMATE); round end down in the recess (NA) / under the cap (EU). |
| — | Pocket-floor insert (NA): printed 0.6 mm floor on the insert's pocket floor | printed | D-41: carries the jumper's tongue with two flush gold pads (battery-free remote). |
| — | EU sensor flex | PCBWay flex, single layer, 0.12 mm, FR4 stiffeners 0.15 mm; `pcb/sensor/` eu_sensor_flex | D-42: MSR-2 CN2 → spring-pin pads → tongue to the floor pads, SHT45 on the tail, microphone. Not orderable until CN2 is confirmed. |
| — | Board posts ×4 (+1 spare) | printed, `print/posts_PC-FR.3mf` | D-28: screw into the insert, snap through the board's mounting holes. |
| — | M4 × 0.7 tap and M4 die | any | Tap the insert's four boss holes, cut the posts' studs after printing. |
| — | #6-32 × 1" oval-head screws | — | ×2, to box ears. |
| — | **Filament, insert: Elegoo PC-FR** (UL 94 V-0 per listing) | see PRINTING.md | ≈ 44 g. Keep the TDS on file. |
| — | Filament, trim + test fits: PETG (ASA in sun) | see PRINTING.md | ≈ 33 g trim, ≈ 110 g test prints. |

## Links
- PCB order pack + human-review checklist: `pcb/fab/README.md`
- IRM-03 datasheet (2025-08-08): https://www.meanwell.com/Upload/PDF/IRM-03/IRM-03-SPEC.PDF
- Harwin S7081-42R drawing: https://content.harwin.com/asset/8cd5d0a8-d578-46b3-8278-7289045a1613/DRG-02322-Technical-Drawing-Datasheet-S7081R-pdf.pdf
- Elegoo PC-FR listing (UL 94 V-0 claim): https://www.3djake.com/elegoo (search PC-FR); get Elegoo's TDS
- MSR-2 GPIO add-on (mezzanine pins 3V, 5V, GND, I²C, 6 GPIO): https://thepihut.com/products/gpio-add-on-for-apollo-automation-msr-2
- MSR-2 ESPHome page: https://devices.esphome.io/devices/apollo-automation-msr-2
- MSR-2 firmware repo: https://github.com/ApolloAutomation/MSR-2
- DMM-4026-B-I2S-R datasheet: https://api.puiaudio.com/filename/DMM-4026-B-I2S-R.pdf
- BILRESA: https://www.ikea.com/us/en/p/-70617457/

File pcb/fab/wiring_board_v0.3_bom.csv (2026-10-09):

Item | Designator | Qty | Manufacturer | Manufacturer Part Number | Description/Value | Package/Footprint | Layer | Datasheet | Notes
1 | S1 | 0 | Marquardt | 1802.2504 | 1802.2504 - Rocker switch DPST, ENEC 12(4) A 250 V~, UL/CSA 15 A 125-250 VAC, PCB pins, emergency off (line and neutral) | Marquardt_1802.2504_DPST_PCB | Top | Marquardt drawing 1802.2504 rev g, 2003-09-16 (K-drawing 18022504.03) | Do not fit. Soldered by hand after the rocker is snapped into the printed insert
2 | J1 | 1 | WAGO | 2604-1106 | 2604-1106 - PCB terminal block, push-in, lever, 6-pole, 5 mm pitch, 4 mm2 / 12 AWG, entry parallel to PCB | WAGO_2604-1106_1x06_P5.00mm_Horizontal | Bottom | https://www.wago.com/global/pcb-terminal-blocks-and-pluggable-connectors/pcb-terminal-block/p/2604-1106 | Safety-critical, do not substitute. Back (B) side, wire entries face the board's top edge
3 | PS1 | 1 | Mean Well | IRM-03-5 | IRM-03-5 - AC-DC module 85-305 VAC in, 5 V 600 mA, 37x24x15 mm | Converter_ACDC_MeanWell_IRM-03-xx_THT | Bottom | https://www.meanwell.com/Upload/PDF/IRM-03/IRM-03-SPEC.PDF | Safety-critical, do not substitute. Back (B) side, sit flush on the board
4 | F1 | 1 | Schurter | 3404.2416.22 | T1A 250V - SMD fuse UMT 250, time-lag 1 A 250 VAC. Rating is a designer's choice: human review | Fuse_Schurter_UMT250 | Top | https://us.schurter.com/bundles/snceschurter/epim/_ProdPool_/newDS/en/typ_UMT_250.pdf | Rating T1A is the designer's choice (Mean Well gives none) - confirm before ordering
5 | RV1 | 1 | TDK | B72660M0271K093 | CU4032K275G2 - SMD varistor SIOV-CU4032K275G2K1, 275 VAC | Varistor_TDK_CU4032 | Top | https://www.farnell.com/datasheets/2921094.pdf | Safety-critical, do not substitute without review
6 | C1 | 1 | Murata | GRM31CR61A226KE19L | 22uF 10V X5R - Ceramic 22 uF 10 V X5R 1206 (or equivalent) | C_1206_3216Metric | Top | https://www.murata.com
7 | J2 | 1 | Hirose | FH12-6S-0.5SH(55) | 5V out (flex jumper) - FPC connector 0.5 mm, 6 contacts, slide lock: 5 V to the flex jumper (D-27, R9) | Hirose_FH12-6S-0.5SH_1x06-1MP_P0.50mm_Horizontal | Top | https://www.hirose.com/product/en/products/FH12/FH12-6S-0.5SH(55)/

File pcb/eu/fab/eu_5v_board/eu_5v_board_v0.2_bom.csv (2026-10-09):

Item | Designator | Qty | Manufacturer | Manufacturer Part Number | Description/Value | Package/Footprint | Layer | Datasheet | Notes
1 | J1 | 1 | Samtec | SSW-102-01-L-S | Socket 1x2 2.54 - 5 V from the mains board's header (5 V island) | PinSocket_1x02_P2.54mm_Vertical | Bottom | https://suddendocs.samtec.com/catalog_english/ssw.pdf | THT socket on the back (B), mates the mains board's J3 (Samtec TSM): confirm 8.51 mm body (SOCKET)
2 | C1 | 1 | Murata | GRM31CR61A226KE19L | 22uF 10V X5R - Ceramic 22 uF 10 V X5R 1206 (or equivalent) | C_1206_3216Metric | Top | https://www.murata.com
3 | P1 | 1 | Harwin | P70-2200045 | P70-2200045 GND - Spring pin, 2 A, 7.1 mm working height: GND to the flex pad through the cap | Harwin_P70-2200045 | Top | https://content.harwin.com/asset/7e702b12-8f84-42b5-9282-d7e22f3466f3/DRG-02624-Technical-Drawing-Datasheet-P70-220-pdf.pdf | SMT spring pin, front (F), peg into the 1.2 mm hole
4 | P2 | 1 | Harwin | P70-2200045 | P70-2200045 +5V - Spring pin, 2 A, 7.1 mm working height: +5 V to the flex pad through the cap | Harwin_P70-2200045 | Top | https://content.harwin.com/asset/7e702b12-8f84-42b5-9282-d7e22f3466f3/DRG-02624-Technical-Drawing-Datasheet-P70-220-pdf.pdf | SMT spring pin, front (F), peg into the 1.2 mm hole

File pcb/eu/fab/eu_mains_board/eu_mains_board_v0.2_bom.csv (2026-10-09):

Item | Designator | Qty | Manufacturer | Manufacturer Part Number | Description/Value | Package/Footprint | Layer | Datasheet | Notes
1 | S1 | 0 | Marquardt | 1802.2504 | 1802.2504 - Rocker switch DPST, ENEC 12(4) A 250 V~, UL/CSA 15 A 125-250 VAC, PCB pins: emergency off (line and neutral of the load) | Marquardt_1802.2504_DPST_PCB | Top | Marquardt drawing 1802.2504 rev g, 2003-09-16 (K-drawing 18022504.03) | Do not fit. Soldered by hand after the rocker is snapped into the printed cap
2 | J1 | 1 | WAGO | 2604-3102 | 2604-3102 - PCB terminal block, push-in, 2-pole, 4 mm2, entry 90 deg to the PCB, 400 V III/2: house line in, switched line to the load | WAGO_2604-3102_1x02_P5.00mm_Vertical | Bottom | https://www.wago.com/global/pcb-terminal-blocks-and-pluggable-connectors/pcb-terminal-block/p/2604-3102 | Safety-critical, do not substitute. Back (B) side, levers towards the board centre
3 | J2 | 1 | WAGO | 2604-3102 | 2604-3102 - PCB terminal block, push-in, 2-pole, 4 mm2, entry 90 deg to the PCB, 400 V III/2: house neutral in, switched neutral to the load | WAGO_2604-3102_1x02_P5.00mm_Vertical | Bottom | https://www.wago.com/global/pcb-terminal-blocks-and-pluggable-connectors/pcb-terminal-block/p/2604-3102 | Safety-critical, do not substitute. Back (B) side, levers towards the board centre
4 | F1 | 1 | Schurter | 3404.2416.22 | T1A 250V - SMD fuse UMT 250, time-lag 1 A 250 VAC (TMPS 03 recommended input fuse T1.0 A / 250 V) | Fuse_Schurter_UMT250 | Top | https://us.schurter.com/bundles/snceschurter/epim/_ProdPool_/newDS/en/typ_UMT_250.pdf | T1A 250 V per the Traco TMPS 03 datasheet's recommended input fuse - confirm before ordering
5 | RV1 | 1 | TDK | B72660M0271K093 | CU4032K275G2 - SMD varistor SIOV-CU4032K275G2K1, 275 VAC | Varistor_TDK_CU4032 | Top | https://www.farnell.com/datasheets/2921094.pdf | Safety-critical, do not substitute without review
6 | PS1 | 1 | Traco Power | TMPS 03-105 | TMPS 03-105 - AC-DC module 85-264 VAC in, 5 V 600 mA, 25.4x25.4x16.3 mm, IEC/UL 62368-1, IEC 60335-1 | Converter_ACDC_TRACO_TMPS03_THT | Bottom | https://www.tracopower.com/sites/default/files/products/datasheets/tmps03_datasheet.pdf | Safety-critical, do not substitute. Back (B) side over the routed relief slot, sit flush
7 | J3 | 1 | Samtec | TSM-102-01-L-SV | TSM-102-01-L-SV - SMT pin header 1x2, 2.54 mm, 5.84 mm post, gold on post: 5 V to the 5 V board's pin socket (5 V island) | PinHeader_1x02_P2.54mm_Vertical_SMD_Pin1Left | Top | https://suddendocs.samtec.com/catalog_english/tsm.pdf | SMT header on the 5 V island (no pin tails under the PSU)

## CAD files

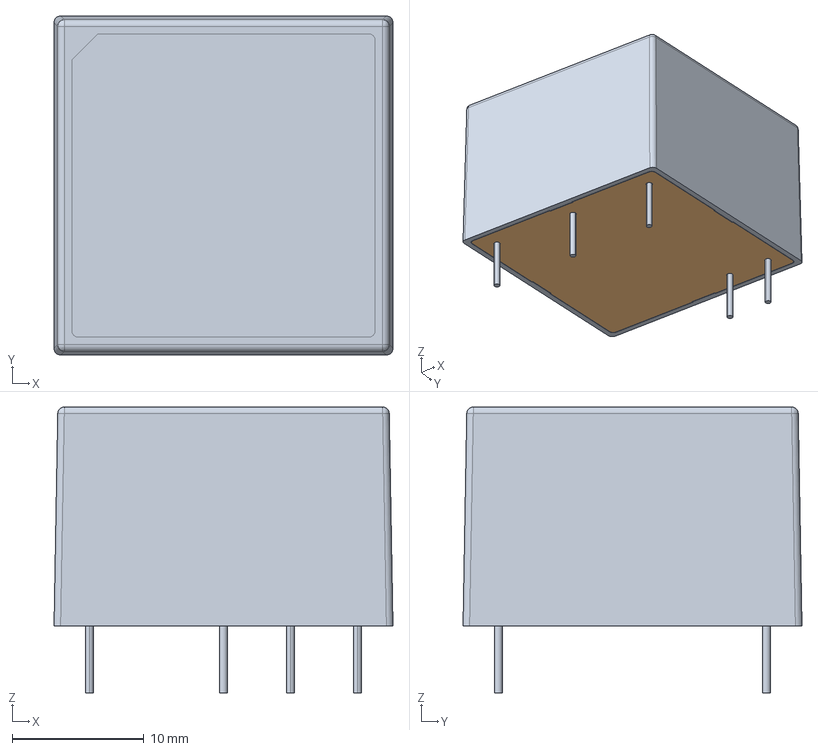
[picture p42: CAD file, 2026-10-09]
pcb/eu/kicad/3d/Converter_ACDC_TRACO_TMPS03_THT.step
25.7 x 25.7 x 21.7 mm
case
base

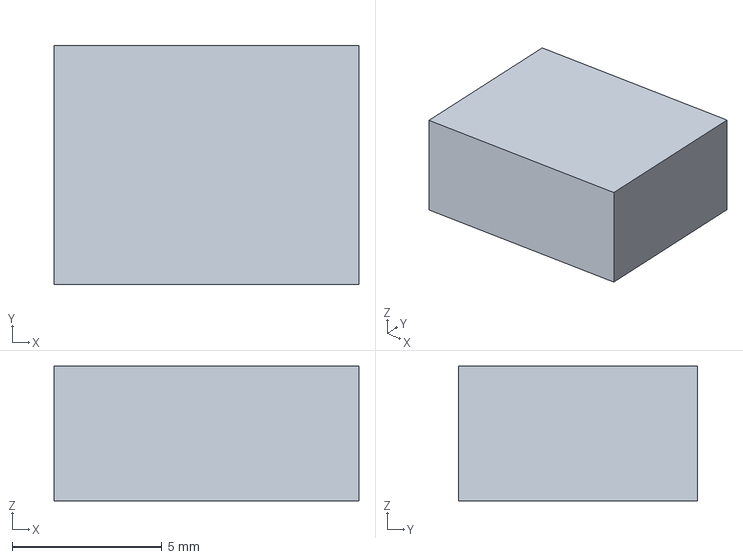
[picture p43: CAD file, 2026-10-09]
pcb/kicad/3d/Varistor_TDK_CU4032.step
10.2 x 8.00 x 4.50 mm

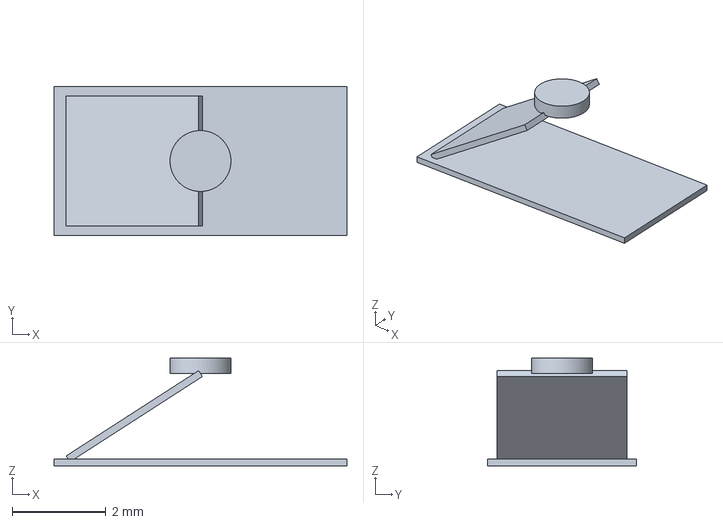
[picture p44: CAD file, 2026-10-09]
pcb/sensor/kicad/3d/Harwin_S7081-42R.step
6.25 x 3.18 x 2.30 mm

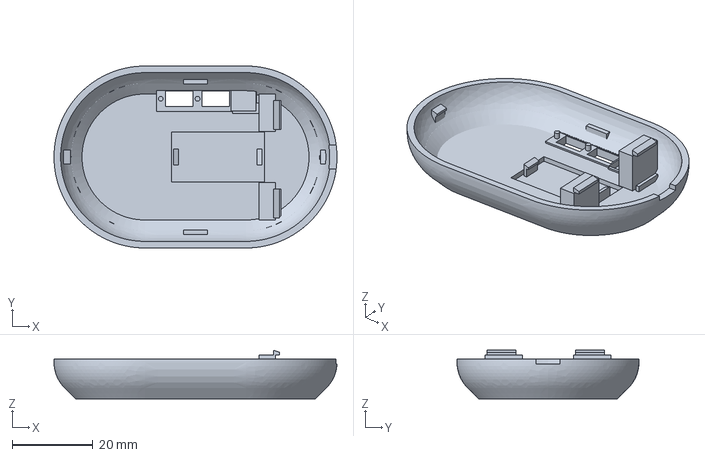
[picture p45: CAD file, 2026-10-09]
print/backcover_PETG.3mf
70.0 x 45.0 x 12.0 mm

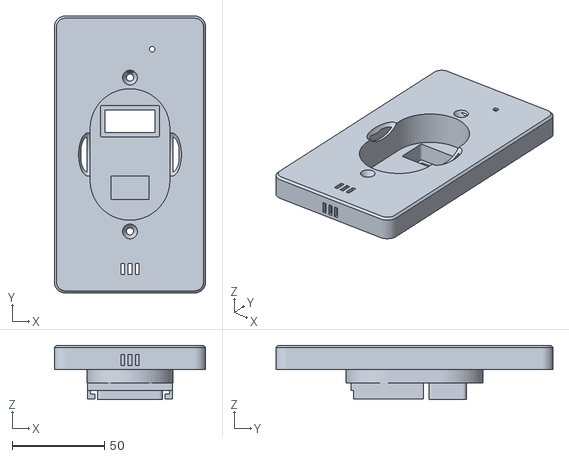
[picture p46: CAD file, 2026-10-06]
reference/v0.1-openscad/plate.stl
82.0 x 150.0 x 29.5

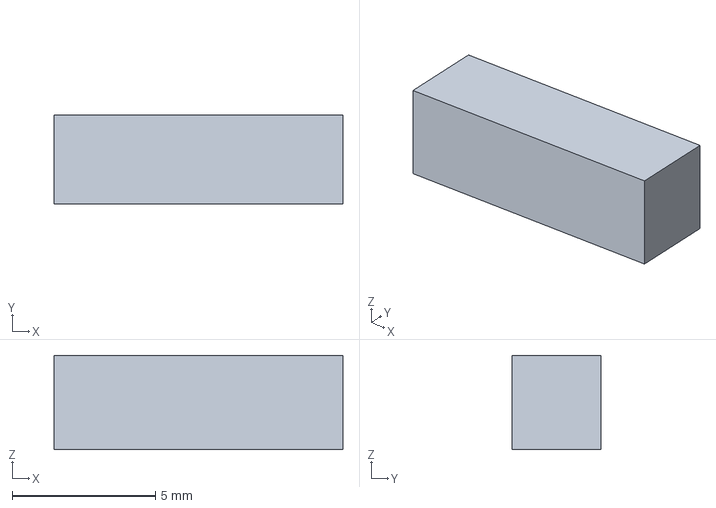
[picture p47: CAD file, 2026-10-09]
pcb/eu/kicad/3d/Fuse_Schurter_UMT250.step
10.1 x 3.10 x 3.30 mm

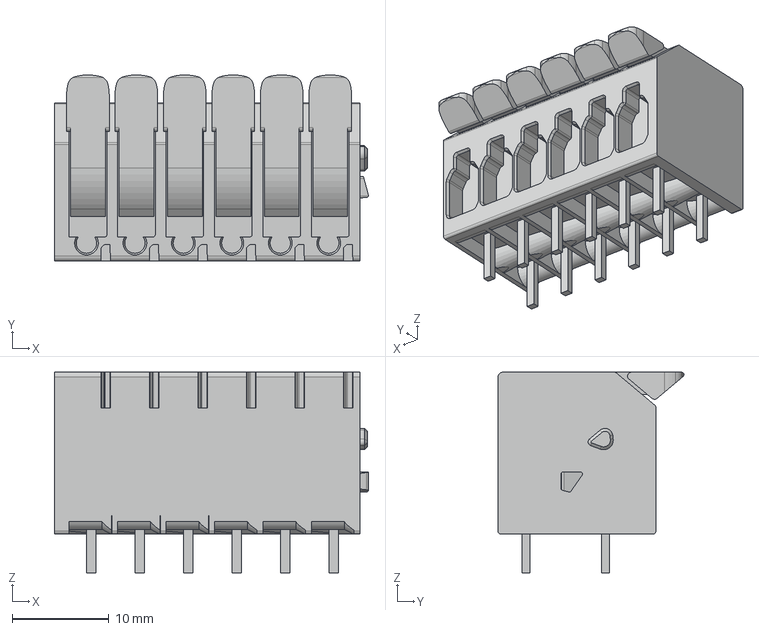
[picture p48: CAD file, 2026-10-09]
pcb/kicad/3d/WAGO_2604-1106.step
32.4 x 19.2 x 20.7 mm

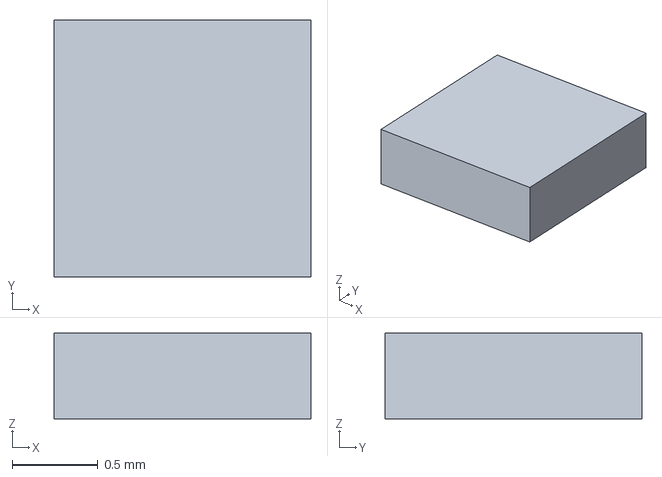
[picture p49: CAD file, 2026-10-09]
pcb/sensor/kicad/3d/Sensirion_DFN-4_1.5x1.5mm_P0.8mm_SHT4x_NoCentralPad.step
1.50 x 1.50 x 0.5 mm

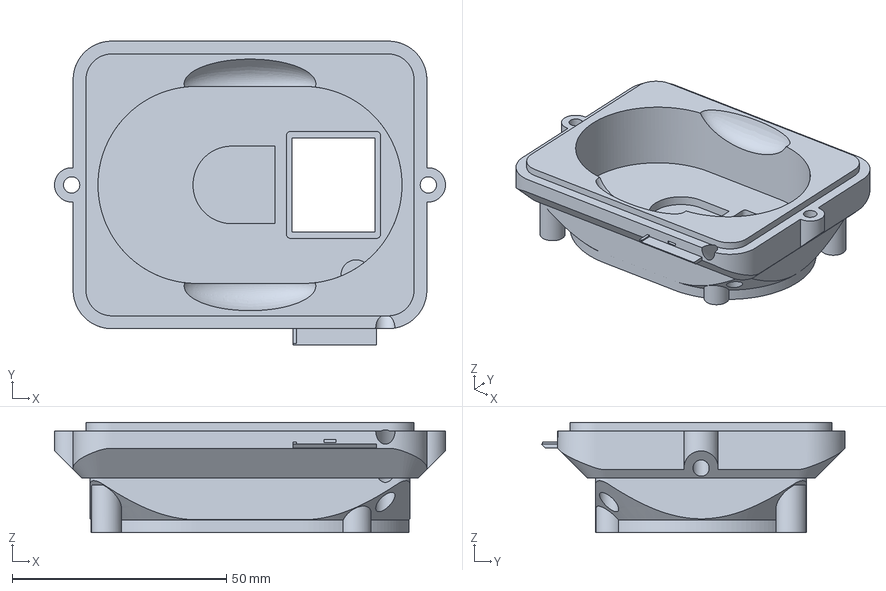
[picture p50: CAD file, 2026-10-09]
print/insert_PC-FR.3mf
91.3 x 70.9 x 25.8 mm

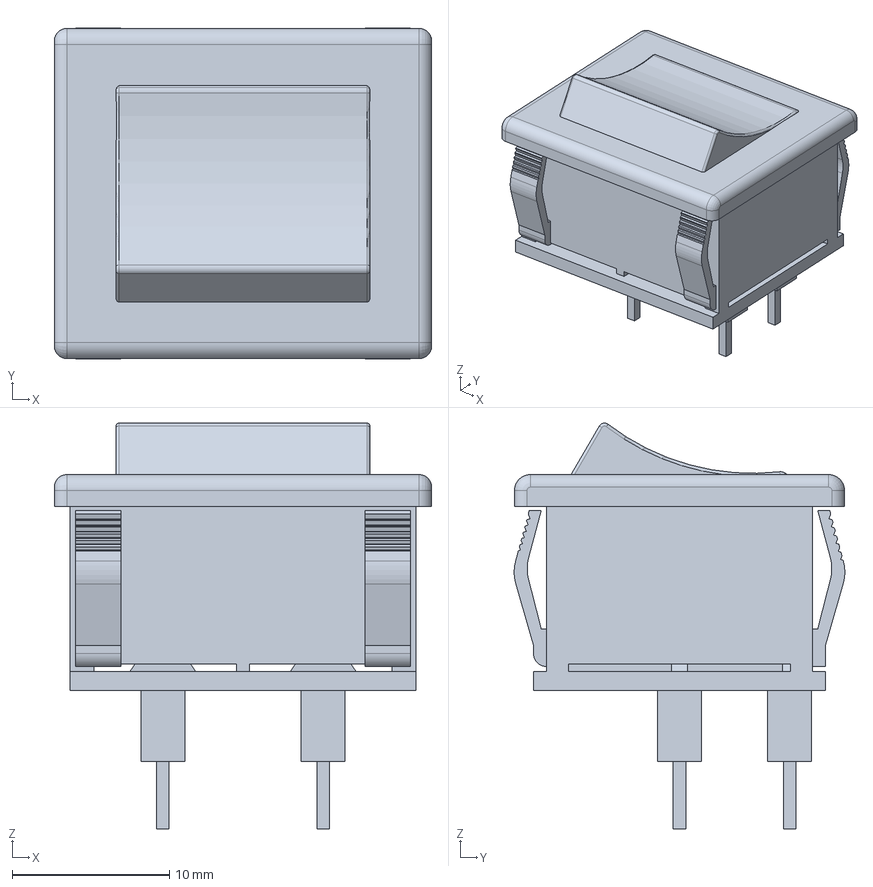
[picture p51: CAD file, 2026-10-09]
pcb/eu/kicad/3d/Marquardt_1802.2504.step
24.0 x 21.0 x 25.8 mm

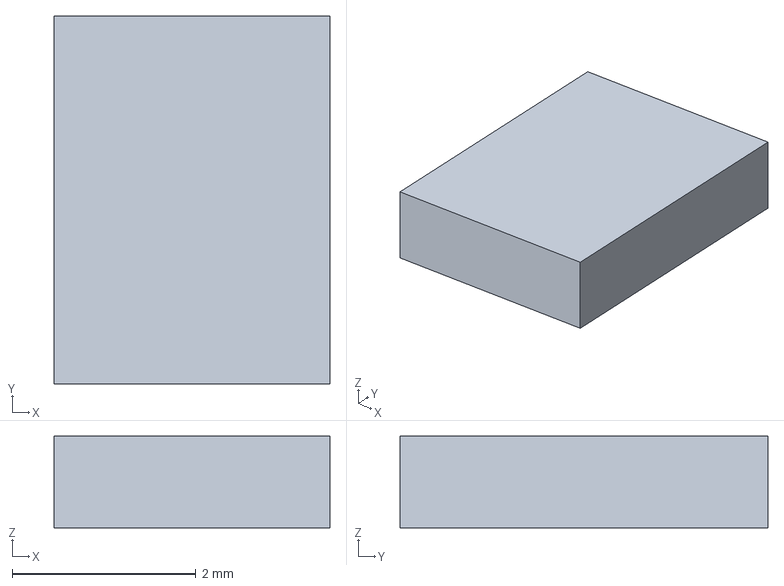
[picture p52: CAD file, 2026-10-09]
pcb/sensor/kicad/3d/PUI_DMM-4026-B-I2S_4x3mm.step
3.00 x 4.00 x 1.00 mm

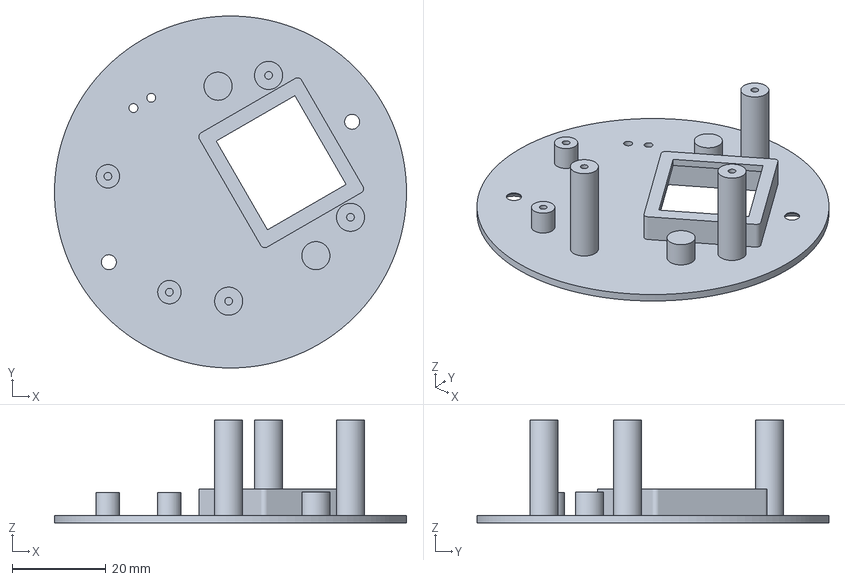
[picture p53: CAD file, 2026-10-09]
print/eu_cap_PETG_testfit.3mf
75.2 x 75.2 x 21.9 mm

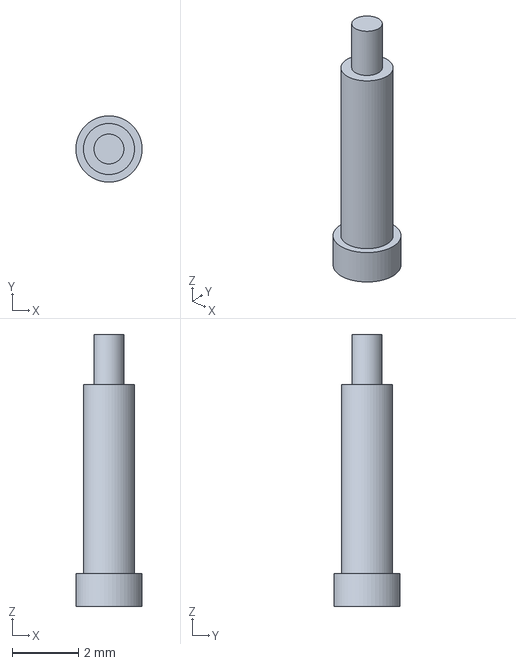
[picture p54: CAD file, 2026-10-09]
pcb/eu/kicad/3d/Harwin_P70-2200045.step
2.00 x 2.00 x 8.20 mm

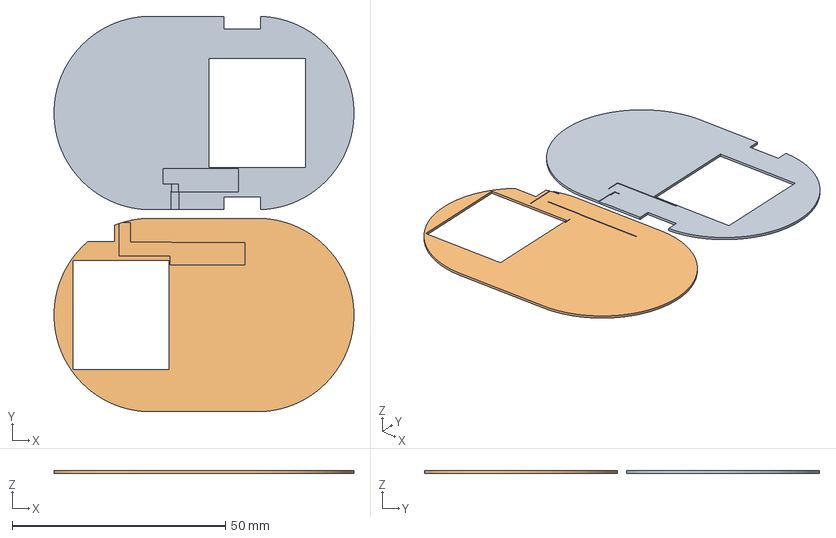
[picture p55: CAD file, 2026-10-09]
print/floor_inserts_PETG.3mf
70.4 x 92.8 x 0.6 mm
floor_eu.stl
floor_na.stl

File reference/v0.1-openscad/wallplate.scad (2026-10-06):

// =====================================================================
//  Smart wall plate – FIRST PASS (v0.1)
//  Recessed IKEA BILRESA (scroll wheel) + hidden emergency rocker +
//  Mean Well IRM-03-5 PSU carrier slot + Apollo MSR-2 bay + SHT45 bay
//  North American single-gang device box (2" x 3" opening)
//
//  Coordinates: X = width, Y = height (up), Z = out of wall.
//  z = 0 is the wall surface. Plate face is at z = PT.
//  Everything with z < 0 is inside the box (MAINS SIDE).
//
//  !! All values marked MEASURE are placeholders - caliper them !!
// =====================================================================

$fn = 64;
part = "plate";
show_wall = false;
explode = 0;           // lift the remote out of its pocket (mm)
use_stl = false;       // previews: use pre-rendered plate.stl
sec = "";              // 2D section export of one part

// ---------------- plate ----------------
PW  = 82;     // plate width
PH  = 150;    // plate height (taller than std to fit MSR-2 + SHT45)
PT  = 13;     // plate proud of wall (set by MSR-2 bay depth)
PR  = 6;      // corner radius
SKIN = 2.0;   // face / side wall thickness of hollow plate

// ---------------- box ----------------
BOX_W = 50.8; BOX_H = 76.2;   // 2" x 3" opening
BOX_D = 63.5;                 // 2.5" deep box (MEASURE yours)
SCREW_PITCH = 83.3;           // 3-9/32" device-ear spacing, #6-32

// ---------------- BILRESA ----------------
B_W = 42;   B_H = 70;   B_D = 20;   // MEASURE (stadium outline)
B_PROUD = 2;                        // remote face sits 2 mm proud
CLR = 0.6;                          // fit clearance
POCKET_WALL = 1.6;                  // pocket shell = mains barrier
SEAT_T = 2.5;                       // pocket floor thickness

// ---------------- emergency switch (Bulgin C1300) ----------------
SW_CUT = [27.3, 12.3];      // panel cutout from datasheet
SW_PANEL_T = 1.5;           // snap-in panel thickness - CHECK datasheet range
SW_BEZEL = [31, 16];        // bezel footprint  - MEASURE
SW_ROCKER_H = 10;           // bezel+rocker height above panel - MEASURE
SW_BODY = [26, 11.5, 24];   // body + 6.3mm tabs behind panel - MEASURE
SW_Y = 18;                  // well centre (upper part of pocket)

// ---------------- PSU carrier PCB ----------------
PCB = [40, 36, 1.6];
PCB_Y = -14;                // centre, lower part of pocket
PCB_STANDOFF = 4;
IRM = [37, 24, 15];         // Mean Well IRM-03-5

// ---------------- MSR-2 ----------------
MSR = [40, 24, 10];         // bare board envelope - MEASURE
MSR_Y = 57;
RADAR_WALL = 1.2;           // thin front skin over the radar
LUX_POS = [12, 0];          // light sensor offset from bay centre - MEASURE

// ---------------- SHT45 tab ----------------
SHT = [12, 8, 4];
SHT_Y = -62;

// ---------------- derived ----------------
seat_z  = PT + B_PROUD - B_D;               // remote back rests here
floor_z = seat_z - SEAT_T;                  // back of pocket floor
pin_w = B_W + 2*CLR;  pin_h = B_H + 2*CLR;  // pocket inner
pout_w = pin_w + 2*POCKET_WALL; pout_h = pin_h + 2*POCKET_WALL;
well_floor = seat_z - SW_ROCKER_H;          // top of switch panel

module rrect(w, h, r) {
    offset(r) square([w-2*r, h-2*r], center=true);
}
module stadium(w, h) {          // rounded-end oval like the BILRESA
    r = w/2;
    hull() { translate([0,  h/2-r]) circle(r); translate([0, -(h/2-r)]) circle(r); }
}

// ---------------------------------------------------------------------
module plate_body() {
    difference() {
        union() {
            // hollow plate shell (open to the wall)
            difference() {
                hull() {
                    linear_extrude(PT-1.2) rrect(PW, PH, PR);
                    linear_extrude(PT) rrect(PW-2.4, PH-2.4, PR-1.2);
                }
                translate([0,0,-0.01]) linear_extrude(PT-SKIN+0.01)
                    rrect(PW-2*SKIN, PH-2*SKIN, PR-SKIN);
            }
            // collar around the box opening: separates the mains-side
            // box from the low-voltage hollow of the plate
            linear_extrude(PT) difference() {
                square([BOX_W+2+3.2, BOX_H+2+3.2], center=true);
                square([BOX_W+2,     BOX_H+2],     center=true);
            }
            // screw bosses
            for (s=[-1,1]) translate([0, s*SCREW_PITCH/2, 0])
                cylinder(r=5.5, h=PT);
            // pocket shell (continuous barrier)
            translate([0,0,floor_z]) linear_extrude(PT-floor_z)
                stadium(pout_w, pout_h);
            // switch well shell
            translate([0, SW_Y, well_floor-SW_PANEL_T])
                linear_extrude(seat_z-well_floor+SW_PANEL_T)
                    rrect(SW_BEZEL[0]+2*CLR+2*POCKET_WALL,
                          SW_BEZEL[1]+2*CLR+2*POCKET_WALL, 2);
            // PSU slot: two rails hanging off the pocket floor
            psu_rails();
            // MSR-2 bay frame
            translate([0, MSR_Y, 0]) linear_extrude(PT)
                difference() { rrect(MSR[0]+2*CLR+3.2, MSR[1]+2*CLR+3.2, 2);
                               rrect(MSR[0]+2*CLR,     MSR[1]+2*CLR,     1); }
            // SHT45 bay frame (isolated from everything else)
            translate([0, SHT_Y, 0]) linear_extrude(PT)
                difference() { rrect(SHT[0]+4, SHT[1]+4, 1.5);
                               rrect(SHT[0]+0.8, SHT[1]+0.8, 0.5); }
        }
        // ---- cuts ----
        // pocket cavity
        translate([0,0,seat_z]) linear_extrude(PT+5) stadium(pin_w, pin_h);
        // switch well cavity
        translate([0, SW_Y, well_floor]) linear_extrude(seat_z-well_floor+0.1)
            rrect(SW_BEZEL[0]+2*CLR, SW_BEZEL[1]+2*CLR, 1);
        // snap-in cutout
        translate([0, SW_Y, well_floor-SW_PANEL_T-1])
            linear_extrude(SW_PANEL_T+2) square(SW_CUT, center=true);
        // steel target recess for the remote's magnet (lower seat)
        translate([0, -18, seat_z-0.8]) linear_extrude(1) square([20.5,12.5], center=true);
        // finger scoops either side of the remote
        for (s=[-1,1]) translate([s*(pin_w/2+1), 0, PT+2.5])
            scale([0.8, 1.8, 1]) sphere(r=7);
        // screw holes, countersunk #6
        for (s=[-1,1]) translate([0, s*SCREW_PITCH/2, 0]) {
            translate([0,0,-1]) cylinder(d=3.8, h=PT+2);
            translate([0,0,PT-3.8]) cylinder(d1=3.8, d2=8, h=3.81);
        }
        // MSR-2 cavity (thin radar skin left at the front)
        translate([0, MSR_Y, -0.01]) linear_extrude(PT-RADAR_WALL)
            rrect(MSR[0]+2*CLR, MSR[1]+2*CLR, 1);
        // light-sensor window
        translate([LUX_POS[0], MSR_Y+LUX_POS[1], PT-3]) cylinder(d=3, h=5);
        // MSR-2 heat vents in top edge
        for (i=[-2:2]) translate([i*7, PH/2-SKIN-1, 3]) cube([3, 6, 6], center=false);
        // SHT45 cavity + vents (face and bottom edge)
        translate([0, SHT_Y, -0.01]) linear_extrude(PT-SKIN)
            rrect(SHT[0]+0.8, SHT[1]+0.8, 0.5);
        for (i=[-1:1]) translate([i*4-1, SHT_Y-3, PT-3]) cube([2, 6, 4]);
        for (i=[-1:1]) translate([i*4-1, -PH/2-1, 2]) cube([2, 10, 6]);
        // 5 V lead pass-through in the collar (SELV, double-insulated lead)
        translate([BOX_W/2+1, 30, 4]) rotate([0,90,0]) cylinder(d=3.5, h=5);
    }
}

module psu_rails() {
    // U-shaped slot: PCB slides in from the top, edge grooves hold it
    rail_len = PCB[1] + 2;
    z_top = floor_z - PCB_STANDOFF;          // component-free face of PCB
    for (s=[-1,1]) difference() {
        hull() {
            translate([s*(PCB[0]/2+1), PCB_Y, (floor_z + z_top-PCB[2]-3)/2])
                cube([4, rail_len, floor_z-(z_top-PCB[2]-3)], center=true);
        }
        translate([s*(PCB[0]/2+0.25), PCB_Y+1, z_top-PCB[2]/2])
            cube([2.5, rail_len+2, PCB[2]+0.4], center=true);
    }
    // bottom end stop
    translate([0, PCB_Y-PCB[1]/2-1.6, (floor_z + z_top)/2])
        cube([PCB[0]+6, 1.6, PCB_STANDOFF+0.01], center=true);
}
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

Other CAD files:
pcb/kicad/3d/Fuse_Schurter_UMT250.step
pcb/eu/kicad/3d/WAGO_2604-3102_1x02_P5.00mm_Vertical.step
print/insert_PETG_testfit.3mf
pcb/eu/kicad/3d/Varistor_TDK_CU4032.step
print/coupons_PETG.3mf
print/eu_cap_PC-FR.3mf
print/eu_trim_PETG.3mf
print/posts_PC-FR.3mf
print/trim_PETG.3mf

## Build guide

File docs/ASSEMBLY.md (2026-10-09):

# Assembly: what holds each part

Every board, flex and electronic part is held by a screw, a solder joint, a printed snap or hook, a
heat-staked peg, or a named tape point. Tape is **3M 467MP** (0.06 mm, double-sided), cut to the pad
sizes below. Nothing here is a compliance statement; mains work is a human decision (SAFETY).

## NA plate

| Part | Held by | Notes |
| --- | --- | --- |
| Insert | the two #6-32 box screws through its flange | |
| Trim | clamped by the same screws; two pins key it | |
| Wiring board | four screw-in snap posts (D-28) | |
| Rocker, WAGO, PSU, F1, RV1, J2 | soldered; the rocker also snaps into the insert's panel | |
| 5 V jumper, connector end | FH12 slide latch on J2 | |
| 5 V jumper, pad end | tape on its stiffener to the shelf; a stop at the shelf's lower end; the spring fingers press it down | shelf stop D-45 |
| Jumper tongue (battery-free) | routed in the tunnel and the wall groove; on the floor, tape under it in the floor insert's recess | pads face up |
| NA floor insert (battery-free) | tape on its underside to the pocket floor (the barrier stays closed: no holes) | |
| MSR-2 board | two snap hooks at its short ends in the trim's bay (D-45), plus CN2 | snap in from behind |
| Sensor flex | CN2 plug; tape: the finger-section stiffener and the microphone stiffener to the face skin (the mic's own gasket ring seals its port); the SHT45 tail's back to the floor of its bay | |
| Supplied magnet (cut piece) | its own adhesive in the pocket-floor recess | D-43 |

## EU plate

| Part | Held by | Notes |
| --- | --- | --- |
| Cap | two screws into the box's top and bottom domes | |
| Trim | two M2 screws through its tabs into the cap | |
| Mains board, 5 V board | M2 screws on the cap's long bosses | |
| Rocker, WAGO blocks, PSU, header, socket, spring pins | soldered; the rocker also snaps into the cup | |
| Floor insert | glued to the trim (lifts off with it) | |
| Tongue | tape under it in the floor insert's recess; it enters under the pocket wall's notch | |
| MSR-2 board | two snap hooks at its short ends in the trim's bay (D-45), plus CN2 | |
| Sensor flex | CN2 plug; tape: the pad section's stiffener to its rib in the trim (the spring pins press it up against it), the microphone stiffener to the skin, the SHT45 tail to its bay | |
| Cut magnet piece | glued under the cap floor | |

## Replacement back cover

| Part | Held by | Notes |
| --- | --- | --- |
| Cover on the remote | two snap clips (top, bottom) on the housing's wall; side ribs keep it from flexing | pry it off at the notch |
| Plate (magnet, 12 × 20 × 2) | a clip at each end of its pocket | snap in from above |
| Cover flex, pad and regulator sections | 0.3 mm FR4 stiffener on top; two printed pegs through it, heat-staked | melt each peg head over with a soldering iron (about 250 °C, a flat tip), 1 mm of peg above the stiffener |
| Cover flex, run | the slot under the GND contact block | |
| Cover flex, end section | its foot drops into the slot behind a lip on each contact block; the top snaps under a hook on each block | the battery contacts press it into the blocks |

## Order of work for the back cover

1. Snap the plate into its pocket.
2. Thread the flex's run through the slot under the GND block from the cell side; lay the pad and
   regulator sections on the ledge over the pegs, the regulator into its recess.
3. Heat-stake both pegs.
4. Fold the end section up: foot into the lip slots, top under the hooks.
5. Snap the cover onto the remote (both clips), notch at the bottom end.

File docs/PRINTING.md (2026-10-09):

# Printing

Printer: **Elegoo Centauri Carbon 2 Combo** (256 × 256 × 256 mm, enclosed, hardened
0.4 mm nozzle up to 350 °C, bed up to 110 °C, CANVAS 4-filament hub). Slicer:
**OrcaSlicer** (tested 2.4.2, Linux AppImage). ElegooSlicer (an OrcaSlicer fork, tested
1.5.3.5) ships the same CC2 profiles and opens the same projects. The CANVAS hub isn't needed:
every part is single-material.

## Files
| File | Part(s) | Filament | Est. time / mass (OrcaSlicer 2.4.2) |
|---|---|---|---|
| `print/coupons_PETG.3mf` | pocket+well+magnet coupon, MSR-2 bay coupon, rocker panel ladder | PETG | 2 h 06 m / 53 g |
| `print/insert_PETG_testfit.3mf` | NA box insert (fit check only, **not for mains**) | PETG | 2 h 04 m / 50 g |
| `print/trim_PETG.3mf` | NA trim plate | PETG (ASA if in sun) | 56 m / 31 g |
| `print/insert_PC-FR.3mf` | NA box insert, **final** | Elegoo PC-FR (UL94 V-0) | 1 h 56 m / 45 g |
| `print/posts_PC-FR.3mf` | NA board posts ×5 (4 + 1 spare), lying on their flat | Elegoo PC-FR (UL94 V-0) | 7 m / 2 g |
| `print/backcover_PETG.3mf` | replacement back cover for the battery-free BILRESA (D-35), back down | PETG | 19 m / 7 g |
| `print/floor_inserts_PETG.3mf` | pocket-floor inserts, NA and EU (0.6 mm, 0.08 mm layers for the flex recess) | PETG | 11 m / 3 g |
| `print/eu_cap_PETG_testfit.3mf` | EU cap (fit check only, **not for mains**), face down | PETG | 40 m / 11 g |
| `print/eu_cap_PC-FR.3mf` | EU cap, **final** (the EU barrier), face down | Elegoo PC-FR (UL94 V-0) | 35 m / 10 g |
| `print/eu_trim_PETG.3mf` | EU trim plate, face down | PETG | 1 h 23 m / 48 g |

Open a `.3mf` in OrcaSlicer, check the plate, slice, send. The projects carry the
printer (CC2 0.4 nozzle), filament and process settings; the parts are already
oriented. `print/profiles/*.json` hold just the process overrides, importable as
user presets. Thumbnails are missing (generated headless); the slicer redraws them.

Regenerate after any CAD change: `make cad check print`. `make print` downloads the
pinned OrcaSlicer AppImage into `.tools/` (checksum-verified) on first use; set `SLICER`
to use another OrcaSlicer build. Headless machines need `xvfb-run` (`make system-deps`). Sliced G-code for checking
time/material lands in `build/print/gcode/`.

## Order of work
1. `coupons_PETG`: rocker ladder → find the panel thickness that latches firmly,
   record it as `SW_PANEL_T` in `docs/MEASUREMENTS.md`. Pocket+well coupon → remote
   drop-in/lift-out, rocker snap-in, key pin, pass-through. MSR-2 coupon → board fit,
   radar skin, light-sensor hole.
2. Update `params.py` from the measurements, `make cad check print`.
3. `insert_PETG_testfit` + `trim_PETG` → full dry fit in the box (breaker off, nothing
   connected). Check the corner taper against the box ears.
4. `insert_PC-FR` for the installed part. Keep the filament datasheet with the build record.
5. Battery-free remote: `backcover_PETG` on a BILRESA (latches, steel plate, contact positions,
   the end fingers' ramp), `floor_inserts_PETG` in the pocket. Cut the supplied magnet first (D-43:
   one straight cut, an 18.5 mm piece with one round end; check its real size).
6. EU: `eu_cap_PETG_testfit` + `eu_trim_PETG` in a 60 mm round box (domes, depth of the board
   stack), then `eu_cap_PC-FR`.

Many BILRESA dimensions are `ESTIMATE` (from photos and drawings, `docs/MEASUREMENTS.md`): the
first prints of the trim pockets, the back cover and the floor inserts are for measuring and
adjusting, not final parts.

## Settings (and why)
- **Back cover** (`COVER`): back down as modelled, 3 walls (1.2 mm), 2 bottom layers (the 0.4 mm
  floor under the steel plate and the regulator), 30 % gyroid, no supports (the back's round-over
  is filled to 45° below its 45° point for that).
- **Floor inserts** (`FLOOR`): flat, 0.08 mm layers after a 0.2 mm first layer, so the flex
  recess (0.14 mm, 0.26 mm at the EU fold) prints; solid.
- **EU cap**: the EU barrier, `BARRIER` settings like the NA insert, face down.
- **Insert** (`BARRIER`): the whole insert is barrier, so no modifiers are needed:
  6 walls (≈ 2.7 mm, so every 1.6 mm barrier wall prints solid), 6 top/bottom layers,
  40 % gyroid, no supports, 5 mm outer brim for PC-FR (warping). Orientation: as
  modelled, lowest face (the rocker panel's underside) on the bed. `make check` verifies
  there is no unsupported overhang wider than 3 mm (worst: 2.3 mm seal band; the flange
  underside is a 45° chamfer).
- **Trim** (`TRIM`): face down on the textured PEI sheet (gives the face its finish).
  7 bottom layers so the 1.2 mm radar skin over the MSR-2 is fully solid; 4 walls, 20 %.
  Only bridges are the 2–3 mm vent windows.
- Base process: "0.20mm Strength @Elegoo CC2 0.4 nozzle"; bed: Textured PEI Plate.
- PC-FR: stock "Elegoo PC-FR @ECC2" profile. Elegoo's data sheet (as listed on
  spoolscout.com/data-sheets/elegoo): dry 80 ± 5 °C for 8 h before use (required); print
  and store at ≤ 20 % RH (sealed, desiccant); nozzle 260–280 °C, hardened steel ≥ 0.4 mm;
  bed 90–110 °C on textured/smooth PEI with glue (required); enclosure required, chamber
  45–60 °C; speed < 100 mm/s. Keep the chamber closed and let the part cool on the plate.
- PC-FR is much weaker across layers than along them (tensile 26 vs 55 MPa, impact
  12.2 vs 70.9 kJ/m², data sheet), which is why the board posts print lying down.

## Materials
- Test fits: PETG.
- Insert (barrier): Elegoo PC-FR for now. Its data sheet claims flame retardancy and
  rapid self-extinguishing but states no UL94 class or test thickness. Certification is
  out of scope for this stage (human decision 2026-10-08); a spool with a stated UL94 V-0
  rating will be chosen before an installed build, and its rated thickness goes into
  `V0_RATED_T` (`make check` compares it with the thinnest barrier wall, 1.6 mm).
- Trim: PETG or ASA.

## Checks after printing
- Remote drops in and lifts out with the finger scoops; magnet holds.
- Magnet strength: fit the supplied magnet in its recess on the pocket coupon
  first. It sits 0.5 mm below the seat (`MAGNET_SETBACK`).
  - Too strong: add a thin non-magnetic spacer on top of it (tape, card), or
    reprint with a larger `MAGNET_SETBACK`. If the magnet is a flexible sheet,
    it can also be cut down with scissors.
  - Too weak: shim under the magnet to bring it up to the seat.
  - Do not cut a rigid magnet: ceramic magnets shatter, and neodymium dust
    can ignite.
- Rocker snaps in and latches; rocker clears the remote's back in both positions.
- Trim seats on the flange with the two key pins; island flush with the face.
- Board posts (D-28): tap the insert's four boss holes M4 × 0.7 (7 mm deep, keep the tap
  square, clear the chips), cut the posts' Ø4 studs with an M4 die, screw the posts in by
  the hex collar until it seats on the boss. The board then snaps over the four heads.
- MSR-2 detection range compared with and without the radar skin.

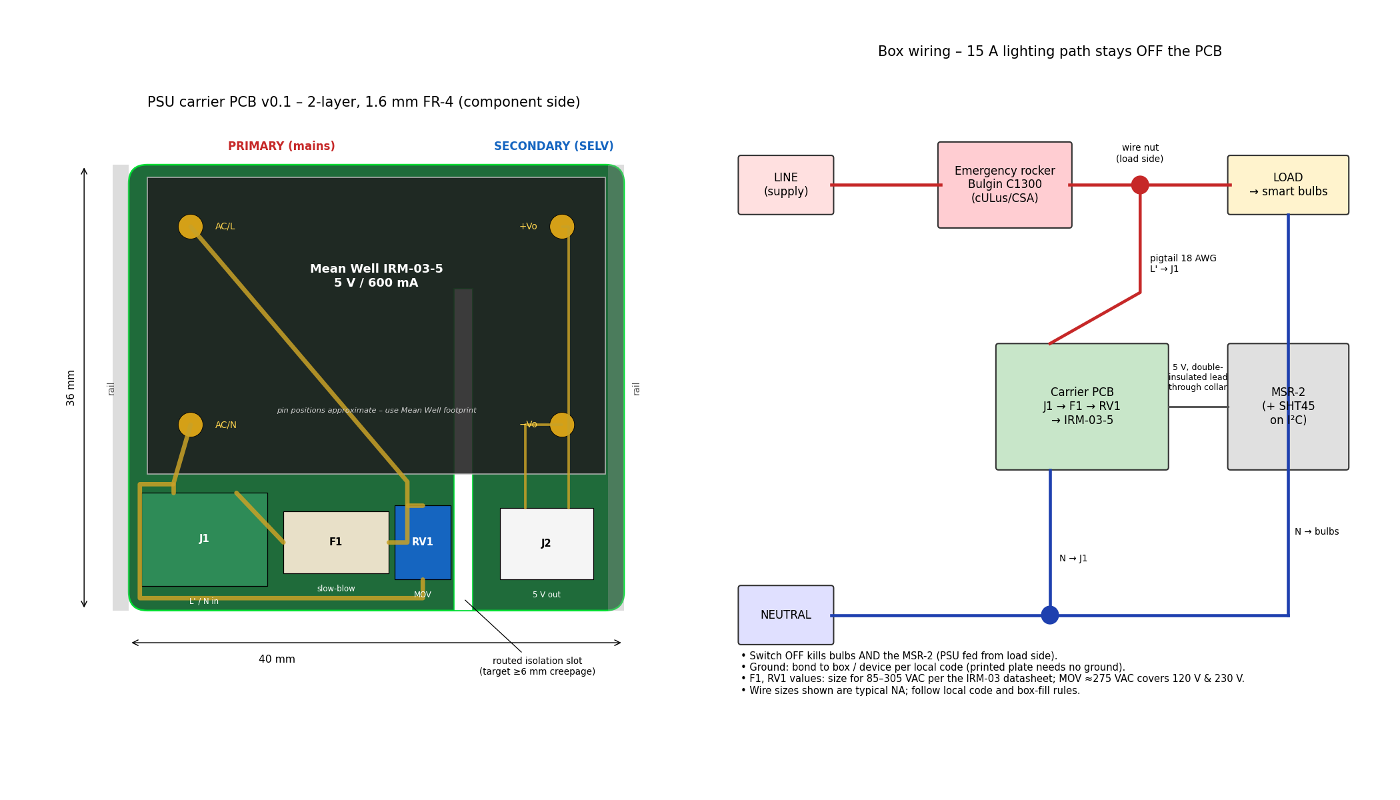
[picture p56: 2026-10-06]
reference/v0.1-openscad/renders/05_psu_pcb_and_wiring.png

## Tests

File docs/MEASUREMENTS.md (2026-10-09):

# Measurements to take (fill in, then update cad/build123d/params.py)

Use calipers; record to 0.1 mm. Measure 2 samples where possible. `status`: TODO / DONE /
REF (published or third-party reference value in use until measured).

| param | what | how | value | status |
|---|---|-----|---|---|
| B_W | BILRESA width (widest) | across the short axis | 45.0 (reference: IKEA UK product size; third-party mount pocket 45.4) | REF |
| B_H | BILRESA height | long axis | 70.0 (reference: IKEA UK product size; third-party mount pocket 70.4) | REF |
| B_D | BILRESA depth | back cover to top of wheel | | TODO |
| — | BILRESA face profile | photo + depth of wheel ring vs body | | TODO |
| B_BACK_RUN, B_BACK_RISE | BILRESA back round-over (inset and height of the curve) | radius gauge or profile photo | 8.5 / 8.5 (reference: third-party mount pocket, quarter circle R≈8.5) | REF |
| — | BILRESA supply | IKEA manual AA-2675003-2 (2025), technical data | 2 × AAA HR03 (NiMH, 2 × 1.2 V nominal); recommended LADDA HR03 rechargeable; types E2490, E2704; 0–40 °C | DONE (manual) |
| — | BILRESA battery contacts: positions in the compartment, spring travel, polarity | open the back cover; calipers from the remote centre. FCC ID FHO-E2490 internal photos (TÜV Rheinland, pictures 1, 3, 4): 2 cells side by side along the long axis, the PCB strip between them; SERIES, confirmed: at the radio-module end one metal strap (silk P3) joins both contacts; at the system-button (S1) end two separate terminals, silk "GND"/P2 and P1 (P1 = VBAT: the E2489 board, same layout, labels these positions VBAT and GND/P2). Which slot is + / − at the terminal end: from the compartment markings on a unit. Approx. from picture 1 scaled to its ruler (perspective, ±1 mm): contacts centred on the remote, 45 mm apart along the long axis (≈ AAA length), 23 mm apart across | ±22.6 along, ±11.7 across (approx.) | REF |
| — | BILRESA battery contact types at each end | FCC ID FHO-E2490 internal photo 1 (cover open): diagonal pairs, at each end one leaf spring (bent out of its slot, − side) and one fixed plate with a dimple set in a pocket in the end wall (+ side); at the terminal end GND meets the leaf spring, VBAT the fixed plate (series chain). Measure on a unit: the plate's setback behind the end wall face (`BC_TERM_SETBACK`, behind the cell end plane), the pocket opening round the plate (the S7081 dome, Ø1.3, must reach it), the leaf spring's rest position and travel, which end is the terminal end | 0.0 (placeholder) | TODO |
| JUMPER_T | 2-layer flex jumper thickness (D-41) | PCBWay stack-up for the ordered flex | 0.2 (design value) | TODO |
| — | BILRESA dual button (E2489) battery contacts | FCC ID FHO-E2489 internal photos (TÜV Rheinland, pictures 1-4): same layout as the E2490, 2 cells side by side along the long axis with the PCB strip between; SERIES: metal strap along the radio module joins the two contacts at that end, terminals at the other end silk "VBAT" and "GND"/P2. Approx. from picture 1 scaled to its ruler (perspective, ±1 mm): centred on the remote, 44.8 mm apart along the long axis, 20.1 mm across. Outline and depth: measure | ±22.4 along, ±10.0 across (approx.) | REF |
| — | BILRESA supply as the remote sees it | zigbee2mqtt E2490 page: reports battery voltage in mV and a percentage that "seems to be tuned for Alkalines (1.5V)"; Qorvo chipset; sleeps between presses. Read the voltage in HA with the 3.3 V supply | | TODO |
| BC_* | BILRESA back cover: outline, wall, latch hooks (position, depth), steel plate size and position, cell axis height above the back | calipers on the original cover and the open remote | | TODO |
| — | Magnet hold vs. the back cover's two spring fingers | pull the remote (with the printed cover) off the plate with a force gauge; fingers need >= 2 x 1.2 N at 2.1 mm (S7081-42R) | | TODO |
| — | BILRESA current: sleep and transmit peak | supply at 2.4 V through a current meter / shunt + scope | | TODO |
| WAGO_ROW (NA) | WAGO 2604 solder-pin rows and body, 2604-11xx (0° entry) | WAGO STEP models 2604-1102 / 2604-1106 (CADENAS download 2026-10-08, kept in scratch/) | pole pitch 5.0; 2 pins per pole in rows 8.2 apart (pins 0.8 × 1.0, 4.0 long); first row 5.0 behind the entry face, second row 2.9 inside the closed back (body 16.1 deep at the board, 16.7 high); levers overhang the entry side at the top to 8.1 beyond the first row | DONE (vendor model) |
| WAGO_ROW (EU) | WAGO 2604-3102 (90° entry) pin rows and body | WAGO STEP model 2604-3102 (CADENAS download 2026-10-08, kept in scratch/) | poles 5.0 apart; 2 pins per pole in rows 8.2 apart (pins 0.8 × 1.0, 4.0 long); body 16.7 along the rows, 3.6 before the first row, 4.9 past the second (lever side, levers up to 21.3); 12.4 across the poles, 0.1 off their centre | 8.2 (rows' centre 0.65 from the body centre) | DONE (vendor model) |
| MAGNET | supplied adhesive magnet w × h × t (with its tape); flexible or rigid? | calipers; bend test | | TODO |
| MAGNET_Y | centre of the steel plate inside the remote, from the remote centre | slide a magnet over the back, mark the strongest spot | | TODO |
| MAGNET_END_R | corner radius of the supplied magnet's ends (the recess bottom follows it; the magnet is cut straight at the top) | radius gauge or trace on paper | | TODO |
| SW_PANEL_T | Marquardt 1802.2504 snap-in panel range | drawing 1802.2504 rev g: 0.75–3 mm, cutout length steps 19.2/19.4/19.8; 1.5 mm chosen; confirm on `coupon_rocker` | 1.5 | TODO |
| SW_BEZEL | 1802.2504 flange w × h | drawing 1802.2504 rev g | 21 × 24 (mounted 24 × 21) | DONE (datasheet) |
| SW_ROCKER_H | rocker top above the panel face | drawing 1802.2504 rev g | 5.3 ± 0.5 | DONE (datasheet) |
| SW_BODY | body w × h; PCB seat below the panel face | drawing 1802.2504 rev g | 18.6 × 22; 16.2 | DONE (datasheet) |
| MSR | bare MSR-2 board w × h × max height | out of case, incl. USB-C and header | | TODO |
| — | MSR-2 powered from the mezzanine header 5V/GND | bench test | yes (human, 2026-10-07) | DONE |
| — | MSR-2 rear connector CN2: maker + MPN, and the mating plug's MPN (the GPIO add-on's CN4) | read the add-on's plug marking, or ask Apollo | 0.4 mm pitch, 2 rows (photo measurement, D-27) | TODO |
| — | CN2 contact count and contact-to-signal map (5V, 3V3, GND, SDA = IO1, SCL = IO0) | count + meter from the add-on's header to its plug | ~26-30 (photo) | TODO |
| MSR_CN2_IN, B2B, B2B_STACK | CN2 centre from the board end, housing size, mated stack height | calipers | 6.4; 7.6 × 3.0; 1.5 (photo estimates) | REF |
| MSR_BOARD | bare MSR-2 board w × h | calipers | 38.0 × 21.5 (Apollo case cavity 38.08 × 21.67, Printables 932026) | REF |
| MSR | MSR-2 envelope; its back plane sets the 1.8 mm under CN2 | calipers | | TODO |
| — | MSR-2 current draw at 5 V (sizes the sensor board's input protection) | USB meter, radar on | | TODO |
| LUX_POS | LTR-390 offset from board centre | calipers | | TODO |
| — | MSR-2 radar antenna position on board | photo | | TODO |
| SHT | chosen SHT45 breakout w × h × t | calipers | | TODO |
| BOX_D | box depth, per room | ruler to back wall | | TODO |
| — | box material per room (metal/plastic) | look | | TODO |
| — | neutral present per box (Y/N) | look/test with breaker off | | TODO |
| — | box ear positions / intrusion into opening | calipers; the insert fills the opening corners to ~10 mm deep (45° taper) and the bottom end to 0.75 mm of the wall | | TODO |
| V0_RATED_T | UL94 V-0 test thickness of the insert filament | filament TDS (cite) | Elegoo PC-FR data sheet states no UL94 class; deferred until a certified spool is chosen (2026-10-08) | TODO |
| — | 1802.2504 latch positions / spring-out below the panel | calipers | | TODO |
| — | wall finish to box face offset | ruler | | TODO |

## Estimates from photos and drawings (2026-10-08)

Human request: assume values from the available pictures, diagrams and drawings until a unit is
measured. Tagged `ESTIMATE` in `params.py`; replace each with a caliper reading before printing
anything final. Sources: FCC FHO-E2490 / FHO-E2489 photos (scratch/, steel rulers, perspective
fits), the IKEA label drawings for E2490 / E2489 (drawn 1:1, outline checks at 70.1 × 45.1), and
the IKEA UK product page (height 20 mm).

| Name | Estimate | ± | Source / method | Used |
| --- | --- | --- | --- | --- |
| B_D | 20.0 | 0.5 | IKEA UK product page | REF in params |
| B_SEAM_Z | 12.5 | 1.5 | FCC external photos 1 / 2: back shell (battery cover) ~12.5, front housing ~7 | yes |
| B_FRONT_R | 0.8 | 0.5 | FCC external photo 1 | yes |
| B_BACK_RUN / B_BACK_RISE | 9.1 / 9.0 | 0.4 / 3 | label drawing: flat back 51.8 × 26.7; rise not visible | yes |
| B_WHEEL_D / B_WHEEL_Y / B_WHEEL_GAP | 41.5 / +12.5 / 0.3 | 1.0 / 1.0 / 0.2 | FCC photos; wheel concentric with the end arc, at the radio-module (strap) end | yes |
| B_LED_Y / B_LED_PITCH | −12.0 / 3.9 | 1.0 / 0.3 | FCC photos; LEDs at the terminal (P1 / P2) end | yes |
| BC_STEEL (x × y × t) | 12.0 × 20.0 × 2.0 | measured | human, 2026-10-09: the plate in the cover is a magnet, not steel | DONE |
| MAGNET_Y (remote's plate centre) | 0.0 | 1.0 | FCC internal photo 1: centred in its cover | yes |
| BC_CELL_X | 11.2 | 0.5 | label drawing bays ±10.95; PCB contacts ±11.4 | yes |
| BC_CELL_Z | 6.8 | 0.8 | inferred: cover wall + clearance + cell radius | yes |
| BC_PCB_W | 11.6 (divider) | 0.3 | label drawing: divider 11.1 / 11.6 over its outer edges; the PCB strip is 11.1 | yes (divider) |
| BC_TERM_Y / BC_VBAT_X | −1 / −1 | — | FCC PCB photo: at the terminal end VBAT (P1) is the fixed dimple plate at −x, GND (P2) the leaf spring at +x | confirmed |
| Fixed plate pocket | ~5.6 across × 3.5 along | 0.7 | FCC internal photo 1; depth (BC_TERM_SETBACK) not visible | the S7081 dome (Ø1.3) fits |
| Leaf spring protrusion | ~2–3.5 from the end wall | low | FCC internal photo 1; travel not visible | — |
| MAGNET (supplied) | ~47.4 × 17.5, full round ends (R8.75), t 1.5–2.5 | 1.0 | label drawing back-view rings, FCC external photo 2 | yes: cut to an 18.5 mm piece (D-43) |
| B_SEAM_Z, BC_WALL | cover depth rim to back 9.8, shell 1.6 | measured | human, 2026-10-09 | DONE |
| BC_PRY | screwdriver notch in the rim at the bottom end | — | human, 2026-10-09: present; size MEASURE (6.0 × 1.2) | TODO |
| BC_SIDE_TAB, BC_SIDE_TAB_GAP | side ribs at mid-length, free-standing on the shell's curved floor (stiffening, no hook) | 36.1 inside spacing, top 3.8 above the inside floor (measured); length 6.0 × 1.5 thick (ESTIMATE, photos) | human, 2026-10-09 | DONE |
| — | supplied wall part: magnet or steel? The remote's plate is a magnet, so a second magnet must face it with opposite poles (mark the cut piece's orientation) | magnet / compass | | TODO |
| BC_LATCH_* (cover snap clips, top and bottom) | one clip per end at x 0, ~3.5 wide × 1.2, inner face ~31.4 from the centre (the bottom one at the pry notch); tops 4.7 (bottom) / 6.5 (top) above the inside floor (measured); hook size MEASURE (0.5) | 0.5 | human photos IMG_5088-5090, measurements 2026-10-09 | partly |
| E2489 outline / depth | 69.5 × 40.0 / ~20 | 0.3 / 2 | label drawing; photo comparison | backlog (E2489 version) |
| E2489 cell axes | ±9.6 across, ends ±22 | 0.4 | label drawing | backlog |

Not determinable from the pictures: BC_TERM_SETBACK, BC_BRIDGE_H, BC_STEEL thickness, the leaf
spring's travel, the magnet thickness. They stay MEASURE.

The supplied magnet appears to be about 47 × 17.5 mm (the drawing's ring, from a shape fit). Whole,
it would run into the switch well (NA) and the switch cup (EU) under the remote's upper half. The
user cuts it once across (human decision 2026-10-08): an 18.5 mm piece measured from one round end
(`MAGNET`), round end down into the recess's round end, straight cut edge up. Check the real size
before cutting; the piece length follows from `MAGNET_REC_Y` and the switch well.

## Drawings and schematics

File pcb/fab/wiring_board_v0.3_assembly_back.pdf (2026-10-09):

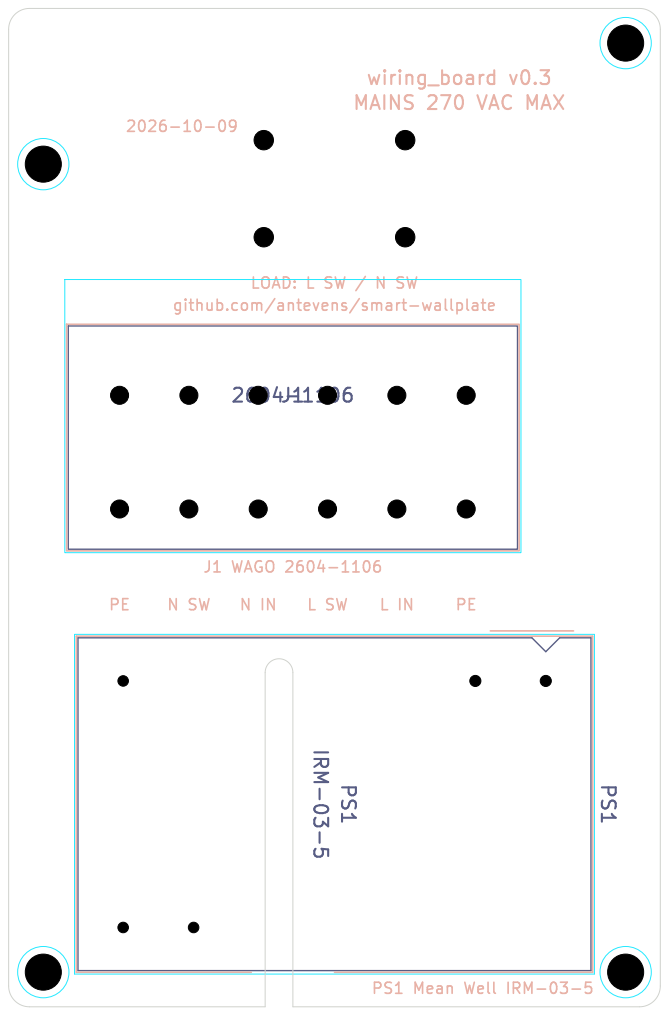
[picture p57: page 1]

github.com/antevens/smart-wallplate

Id: 1/1 Title: File: wiring_board.kicad_pcb Sheet:

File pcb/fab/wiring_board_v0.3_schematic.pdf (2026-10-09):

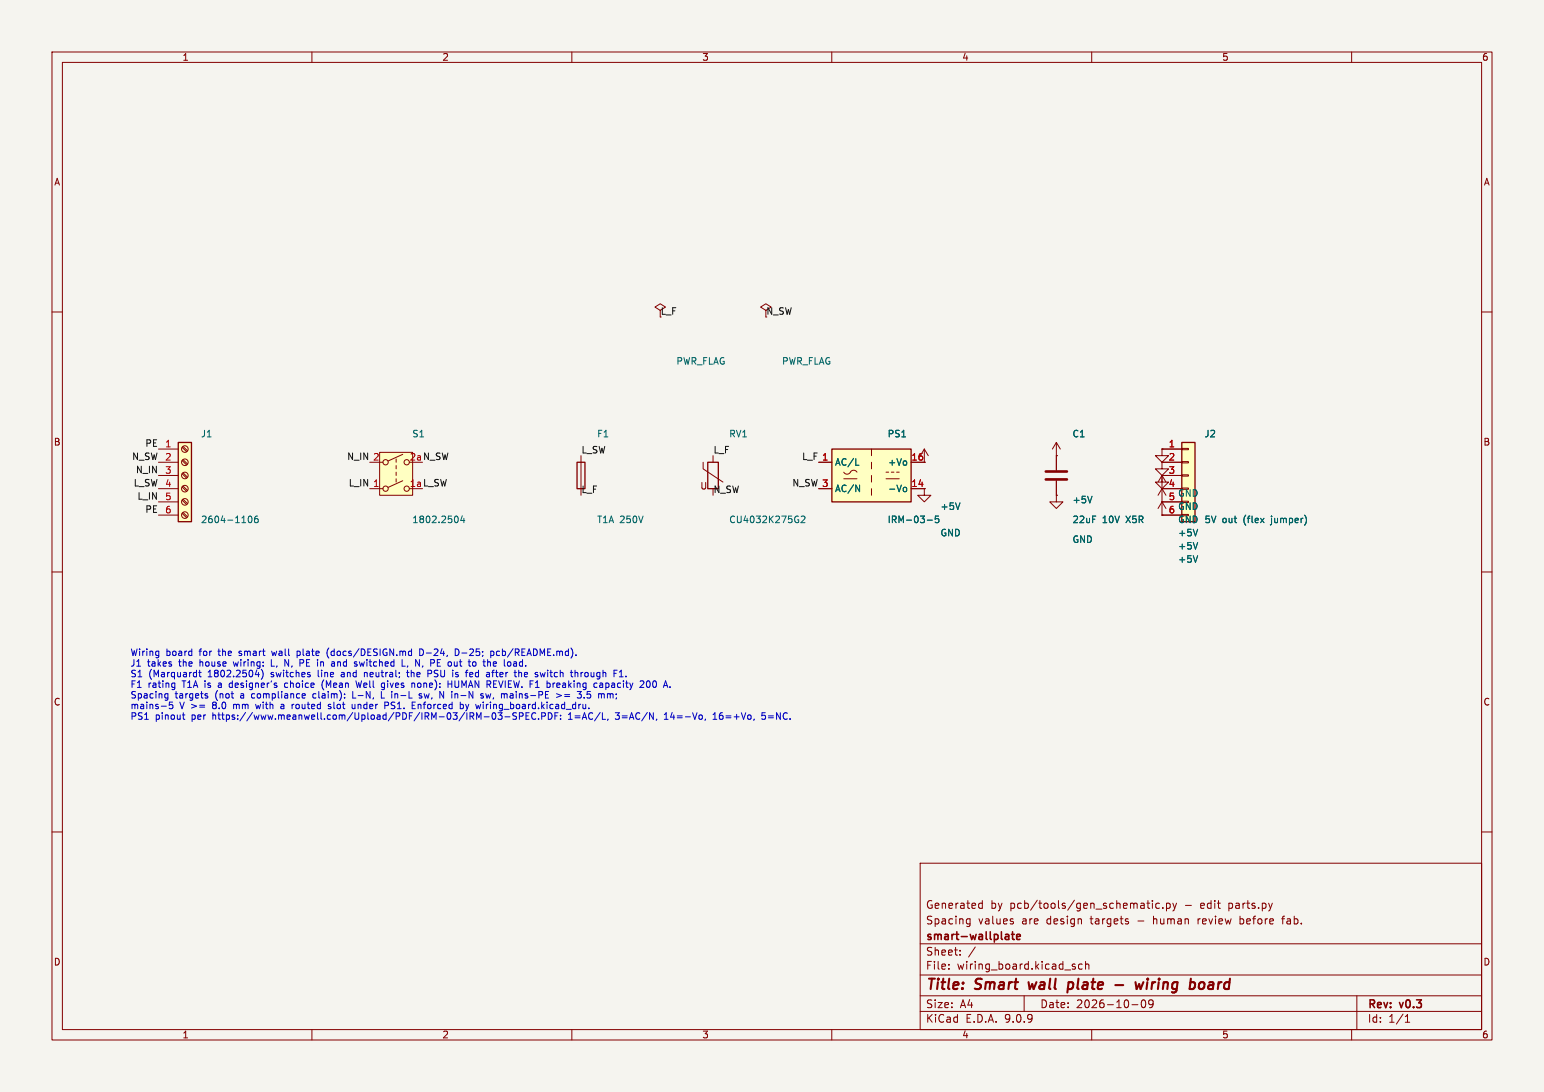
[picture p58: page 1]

J2 GND 5V out (flex jumper) GND GND

6 GND GND GND GND

File: wiring_board.kicad_sch Sheet: / smart-wallplate

Id: 1/1 Title: Smart wall plate - wiring board

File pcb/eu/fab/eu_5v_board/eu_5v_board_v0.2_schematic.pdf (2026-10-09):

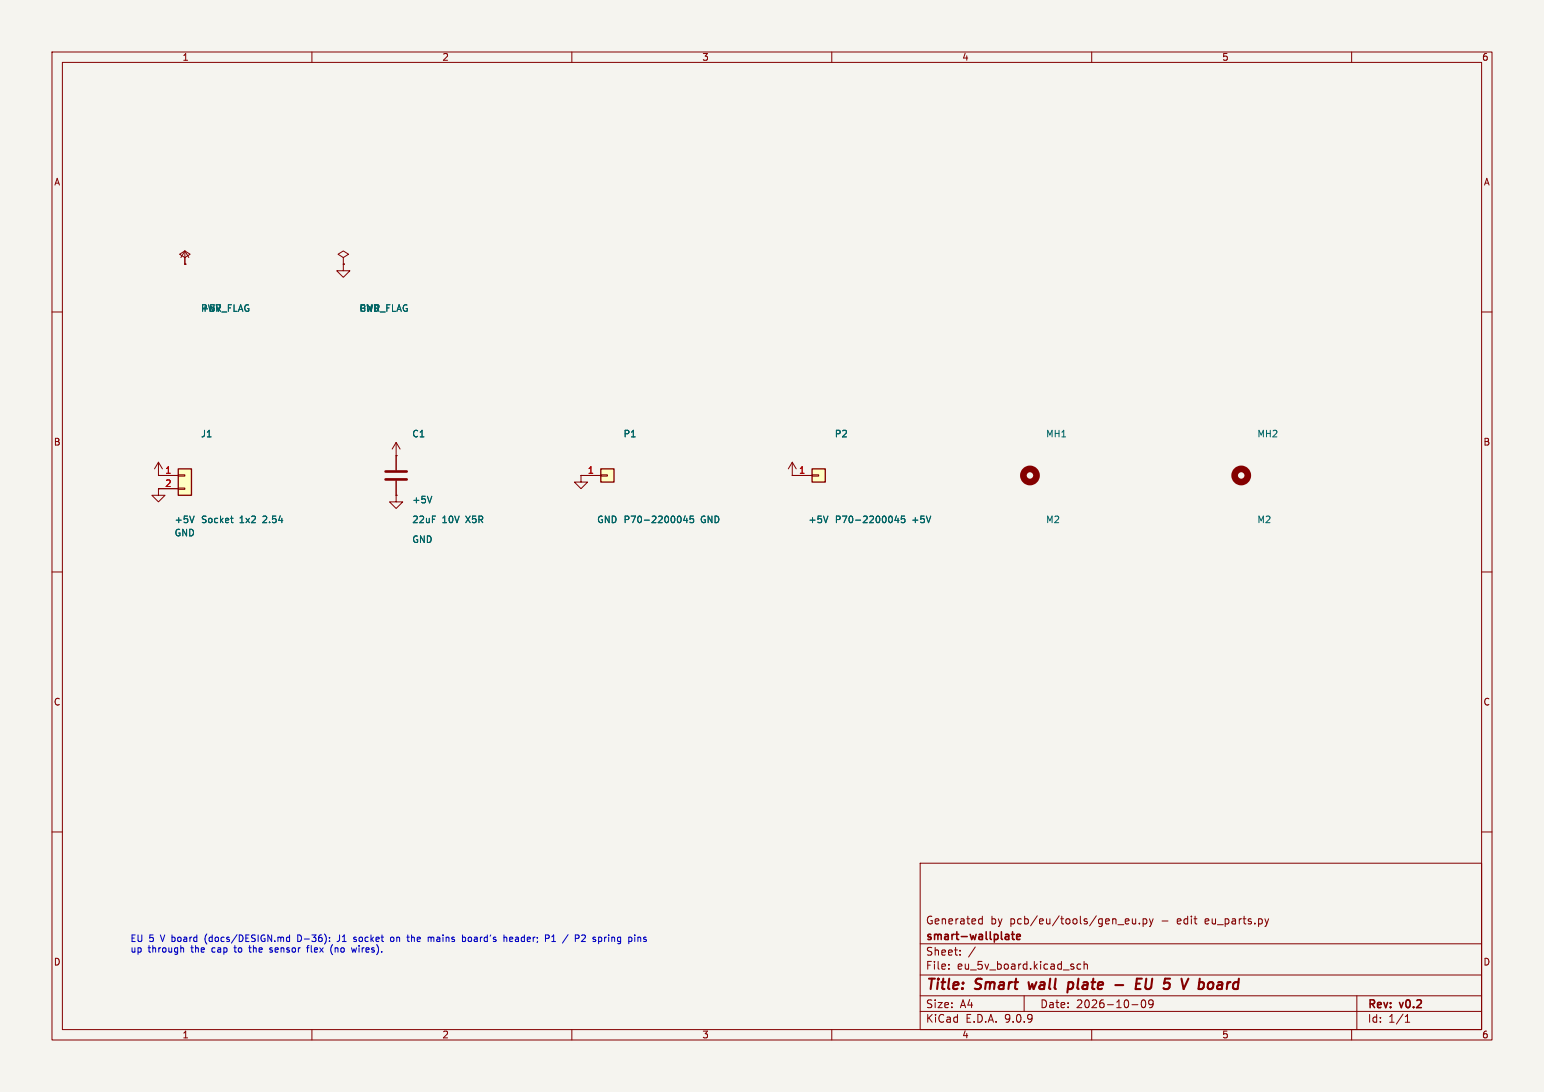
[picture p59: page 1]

Id: 1/1 Title: Smart wall plate - EU 5 V board

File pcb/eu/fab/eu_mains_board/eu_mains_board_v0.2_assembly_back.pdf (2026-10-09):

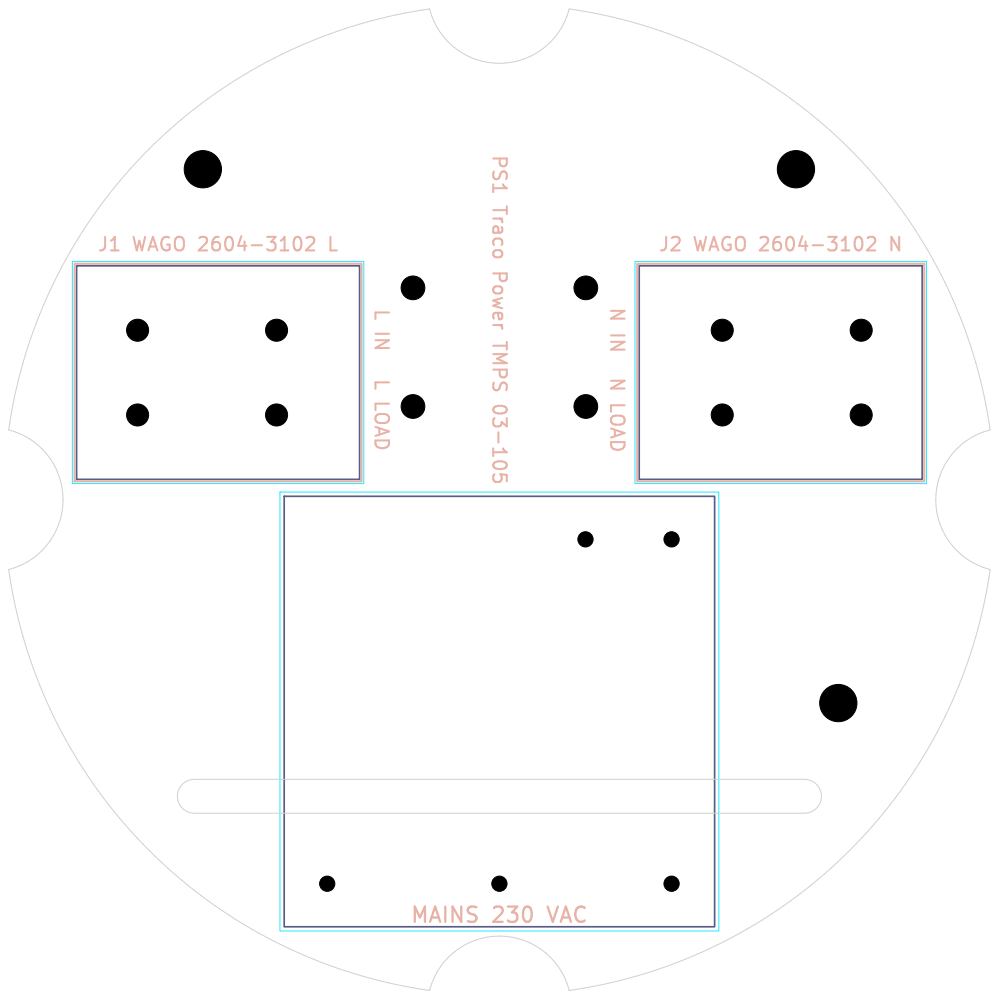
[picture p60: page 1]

N IN N LOAD PS1 Traco Power TMPS 03-105

L IN L LOAD MAINS 230 VAC

Id: 1/1 Title: File: eu_mains_board.kicad_pcb Sheet:

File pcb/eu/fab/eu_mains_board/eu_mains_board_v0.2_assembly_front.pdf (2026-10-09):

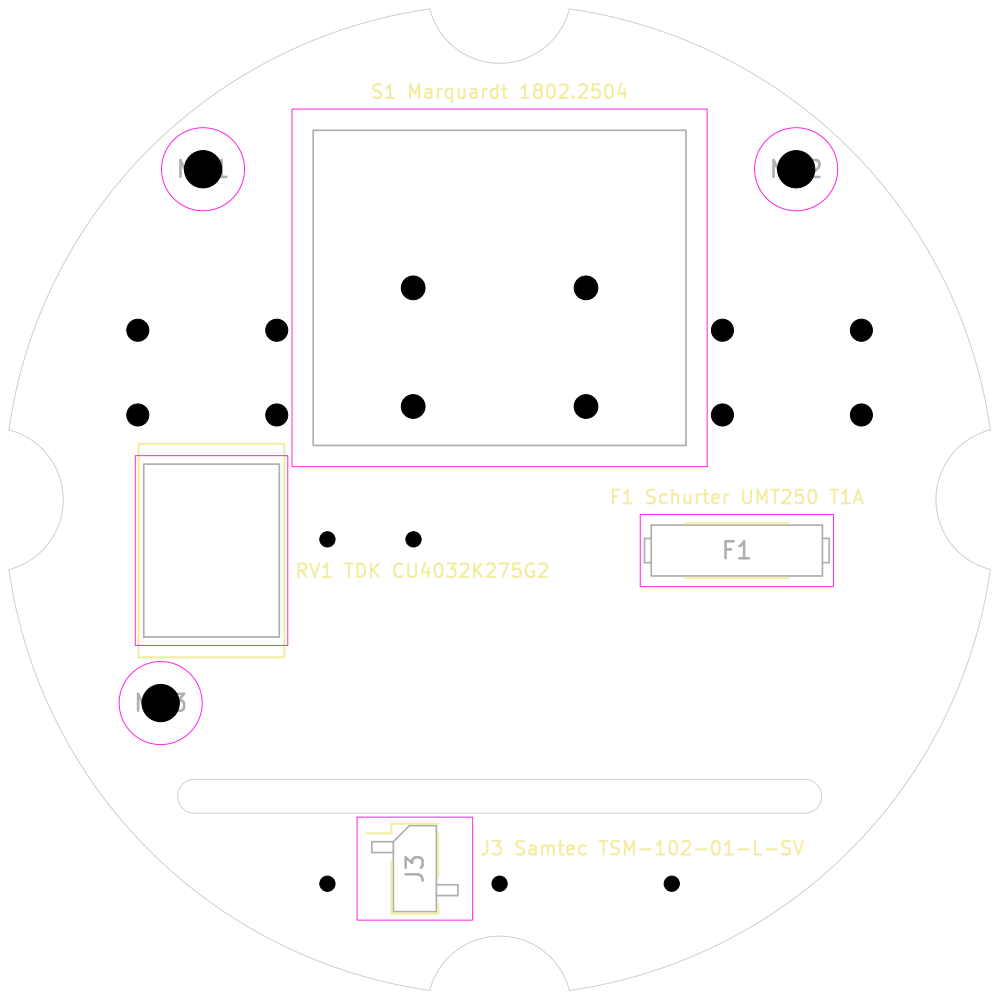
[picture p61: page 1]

Id: 1/1 Title: File: eu_mains_board.kicad_pcb Sheet:

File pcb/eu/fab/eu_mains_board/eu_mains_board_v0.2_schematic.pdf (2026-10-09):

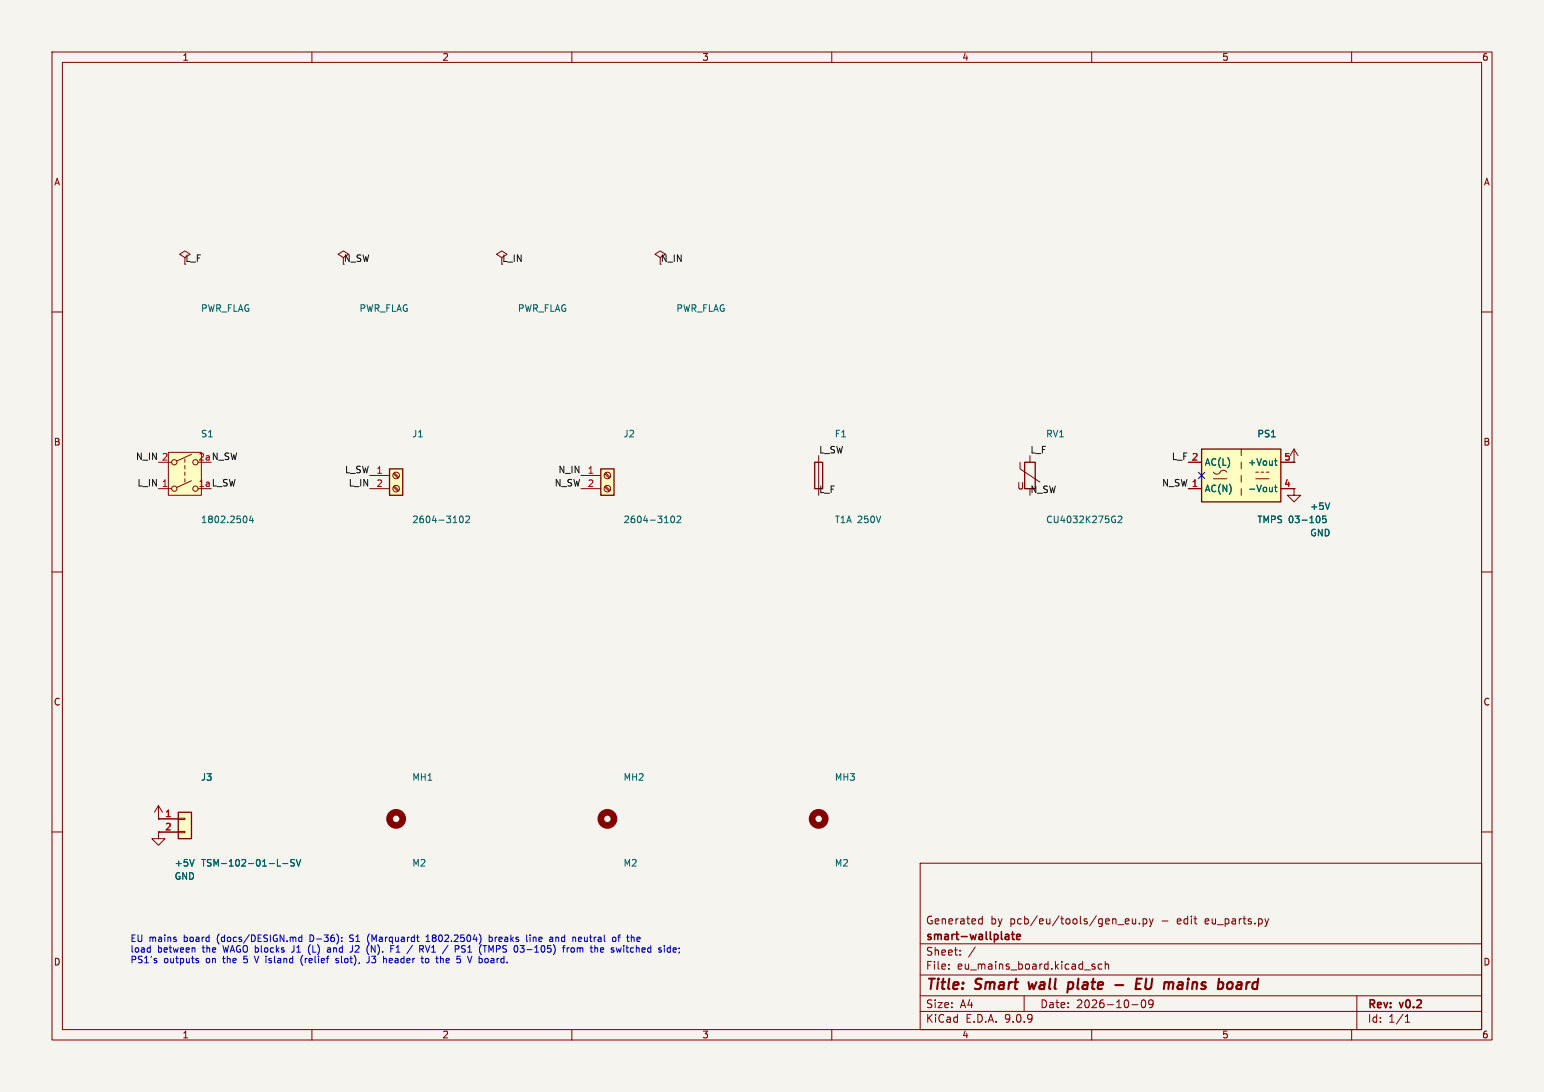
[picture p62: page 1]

Id: 1/1 Title: Smart wall plate - EU mains board

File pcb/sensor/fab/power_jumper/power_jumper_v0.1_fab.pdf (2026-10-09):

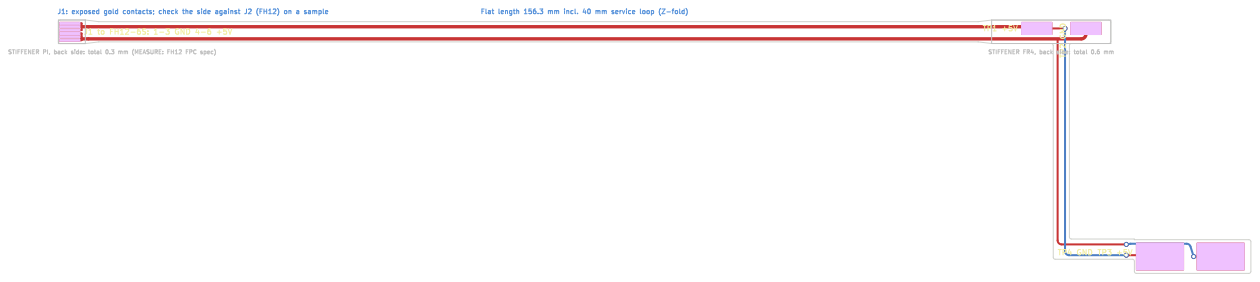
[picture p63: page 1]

Id: 1/1 Title: File: power_jumper.kicad_pcb Sheet:

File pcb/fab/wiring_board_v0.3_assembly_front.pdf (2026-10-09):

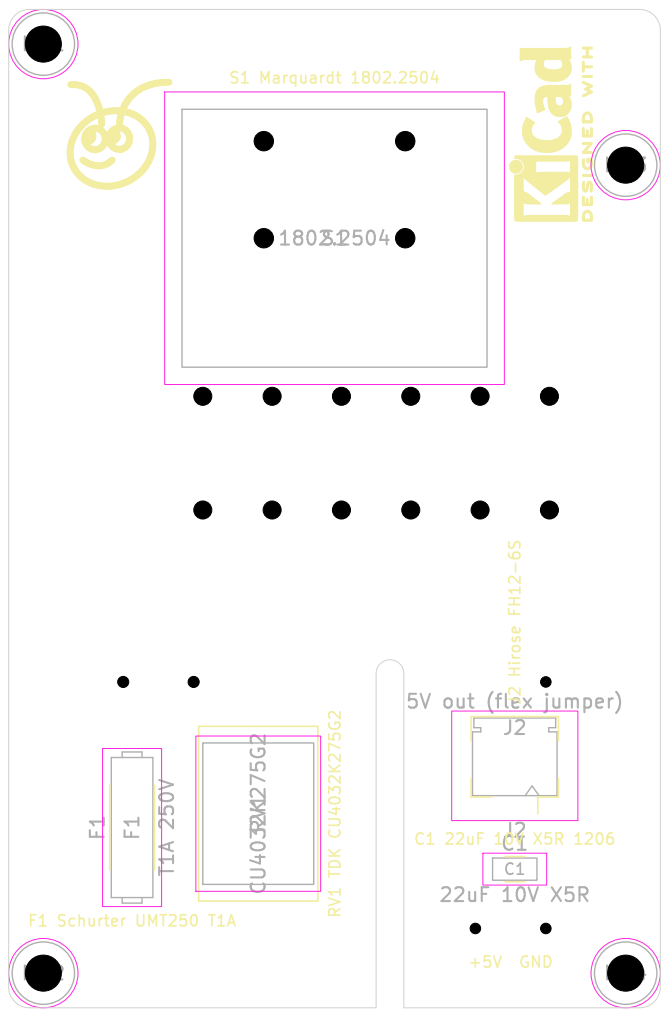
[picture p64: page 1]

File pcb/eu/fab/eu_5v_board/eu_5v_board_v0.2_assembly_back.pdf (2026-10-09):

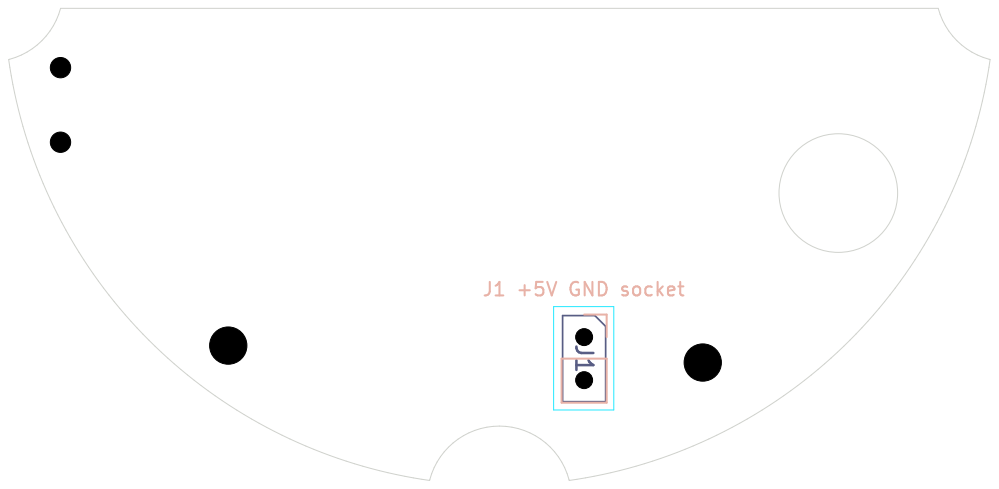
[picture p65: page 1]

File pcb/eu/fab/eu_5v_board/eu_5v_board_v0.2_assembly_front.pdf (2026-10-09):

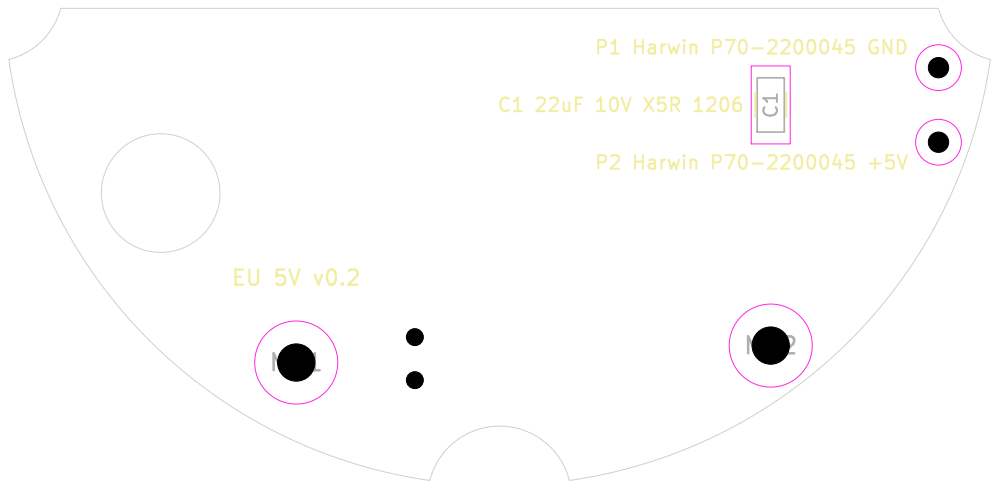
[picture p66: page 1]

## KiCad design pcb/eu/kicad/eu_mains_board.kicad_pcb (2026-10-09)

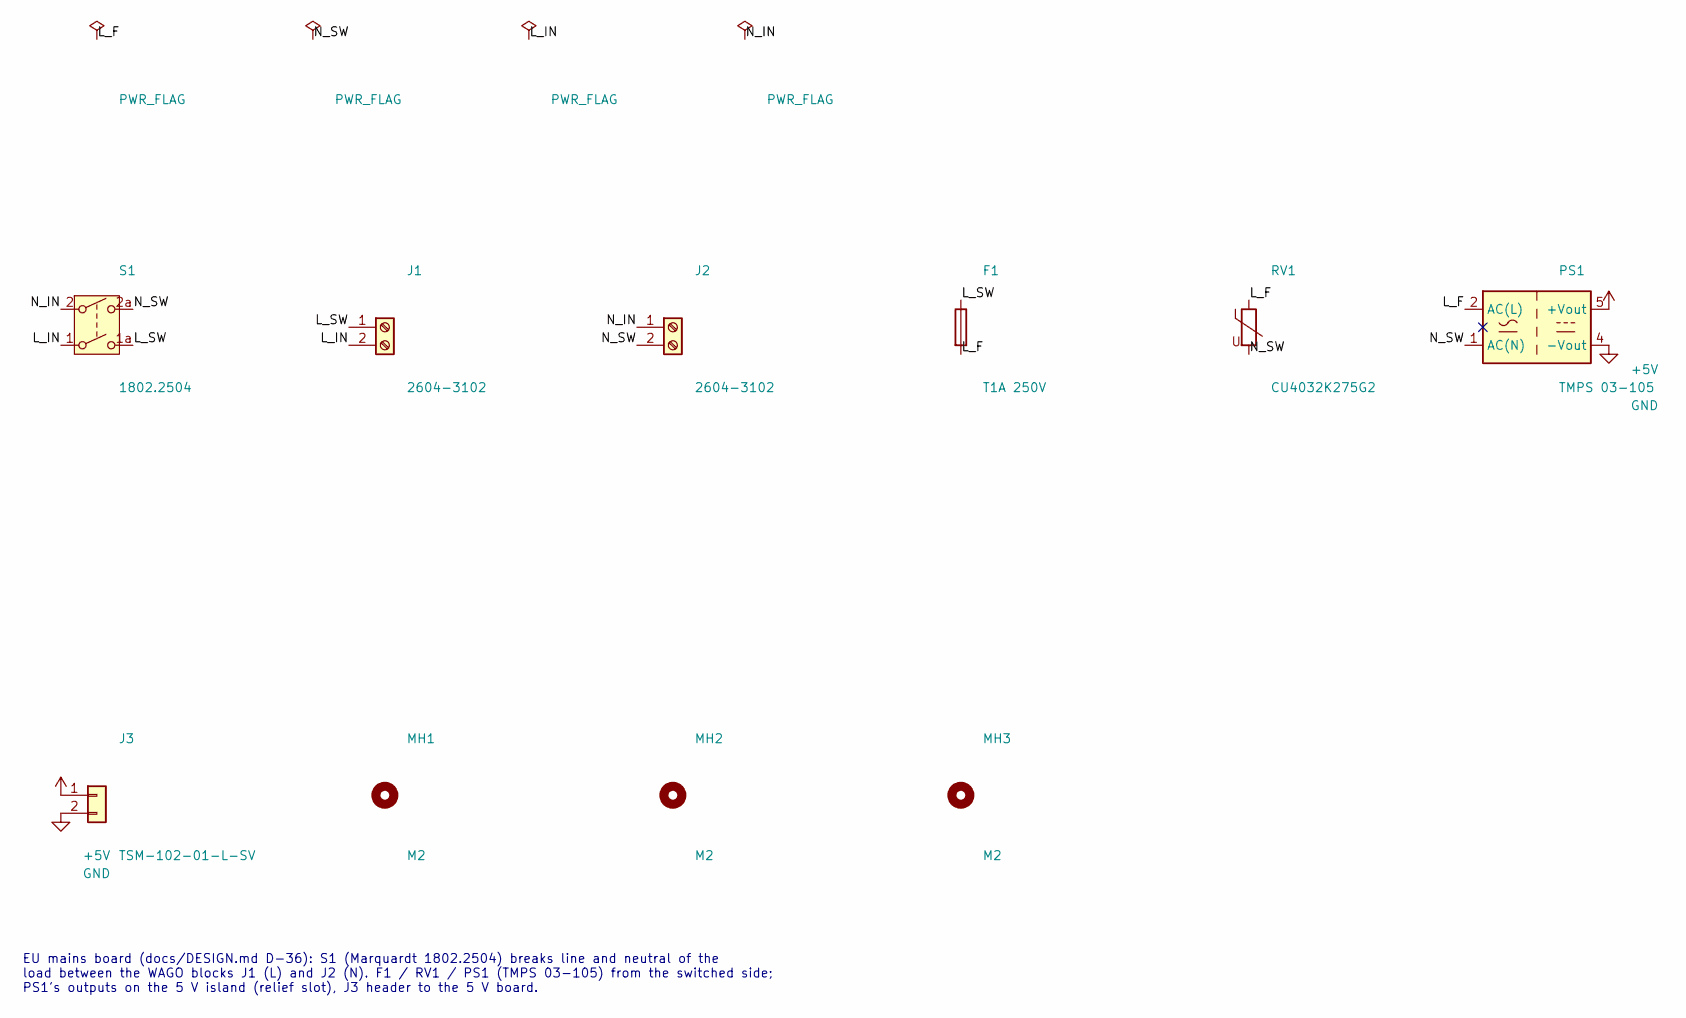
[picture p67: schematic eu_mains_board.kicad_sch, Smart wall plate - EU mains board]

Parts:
F1: T1A 250V; Fuse_Schurter_UMT250; MPN 3404.2416.22
J1, J2: 2604-3102; WAGO_2604-3102_1x02_P5.00mm_Vertical; MPN 2604-3102
J3: TSM-102-01-L-SV; PinHeader_1x02_P2.54mm_Vertical_SMD_Pin1Left; MPN TSM-102-01-L-SV
MH1, MH2, MH3: M2; MountingHole_2.2mm_M2
PS1: TMPS 03-105; Converter_ACDC_TRACO_TMPS03_THT; MPN TMPS 03-105
RV1: CU4032K275G2; Varistor_TDK_CU4032; MPN B72660M0271K093
S1: 1802.2504; Marquardt_1802.2504_DPST_PCB; MPN 1802.2504

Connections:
+5V: J3.1, PS1.5 (+Vout)
/L_F: F1.2, PS1.2 (AC(L)), RV1.1
/L_IN: J1.2, S1.1
/L_SW: F1.1, J1.1, S1.1a (2)
/N_IN: J2.1, S1.2 (3)
/N_SW: J2.2, PS1.1 (AC(N)), RV1.2, S1.2a (4)
GND: J3.2, PS1.4 (-Vout)

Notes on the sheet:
EU mains board (docs/DESIGN.md D-36): S1 (Marquardt 1802.2504) breaks line and neutral of the load between the WAGO blocks J1 (L) and J2 (N). F1 / RV1 / PS1 (TMPS 03-105) from the switched side; PS1's outputs on the 5 V island (relief slot), J3 header to the 5 V board.

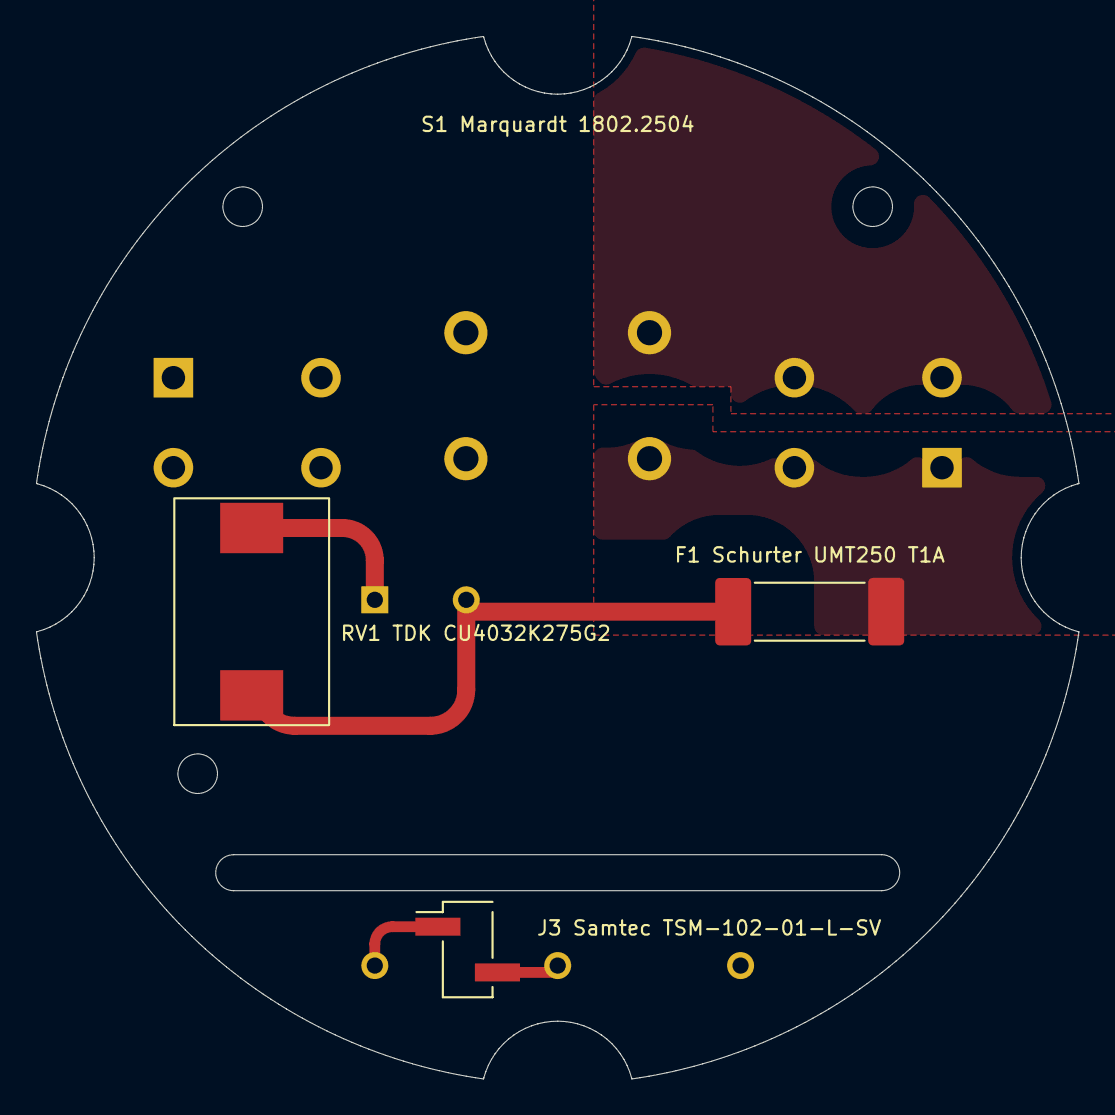
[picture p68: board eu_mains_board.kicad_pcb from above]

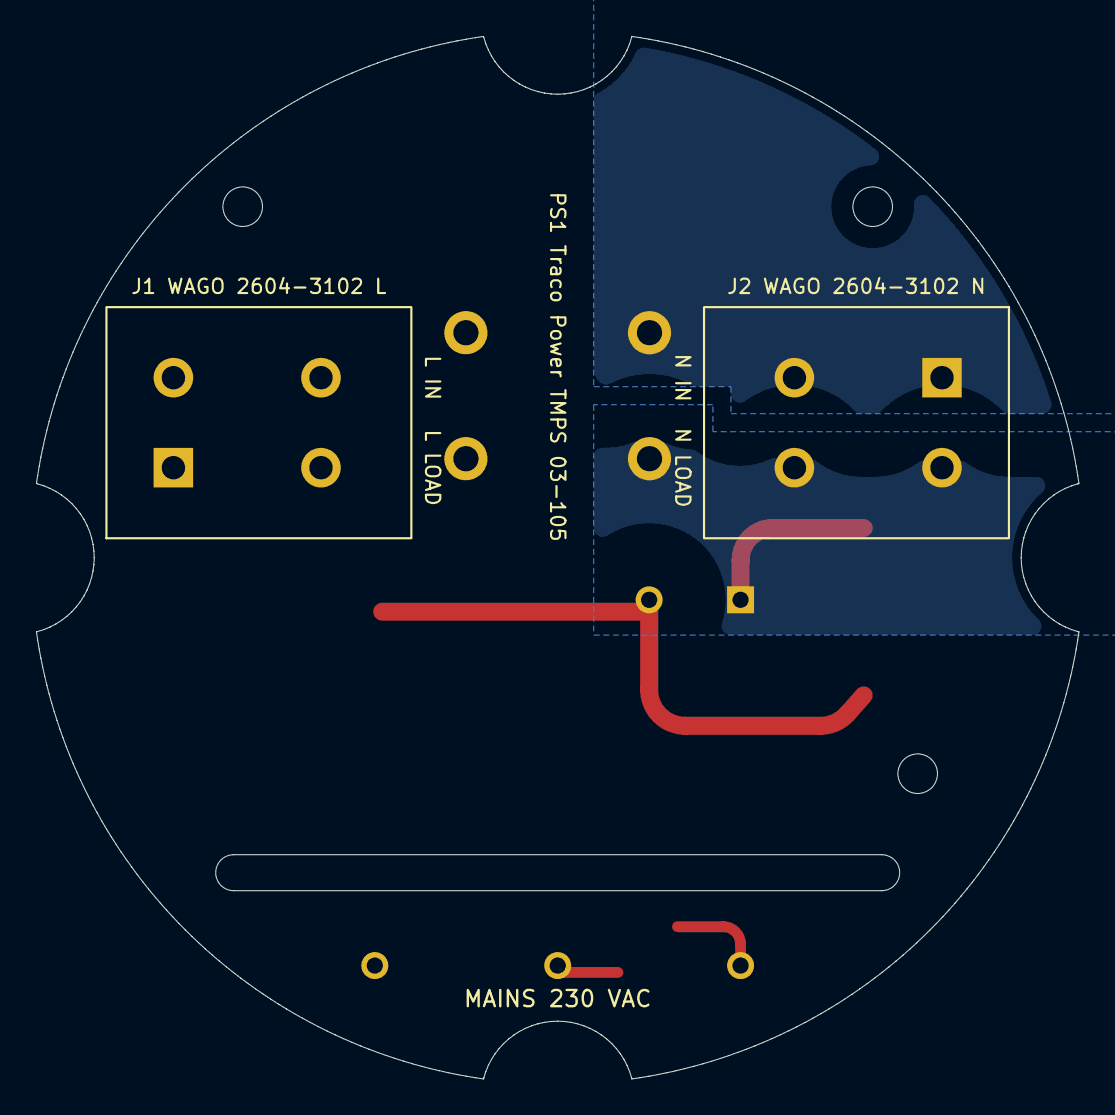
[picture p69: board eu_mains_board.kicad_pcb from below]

Board: 2 copper layers, 57.9 x 57.9 mm, 10 parts (3 on the bottom side), 7 nets.

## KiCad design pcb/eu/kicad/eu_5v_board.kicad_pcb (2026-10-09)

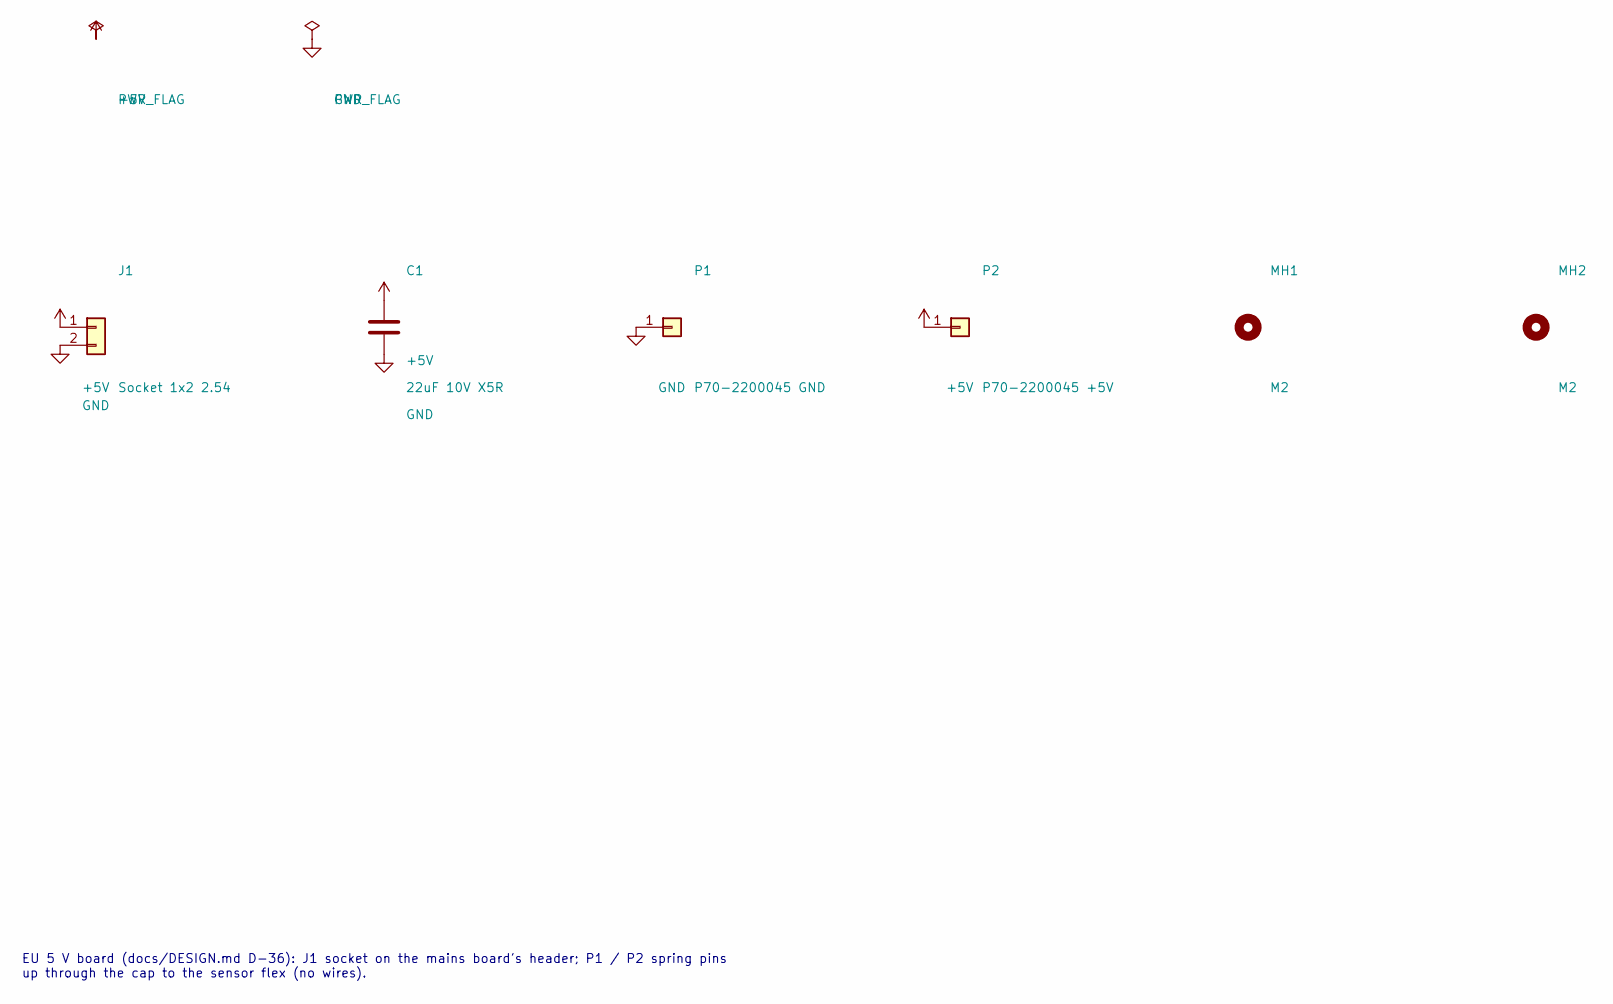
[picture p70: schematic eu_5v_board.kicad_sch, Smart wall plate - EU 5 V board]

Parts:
C1: 22uF 10V X5R; C_1206_3216Metric; MPN GRM31CR61A226KE19L
J1: Socket 1x2 2.54; PinSocket_1x02_P2.54mm_Vertical; MPN SSW-102-01-L-S
MH1, MH2: M2; MountingHole_2.2mm_M2
P1: P70-2200045 GND; Harwin_P70-2200045; MPN P70-2200045
P2: P70-2200045 +5V; Harwin_P70-2200045; MPN P70-2200045

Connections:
+5V: C1.1, J1.1, P2.1
GND: C1.2, J1.2, P1.1

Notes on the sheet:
EU 5 V board (docs/DESIGN.md D-36): J1 socket on the mains board's header; P1 / P2 spring pins up through the cap to the sensor flex (no wires).

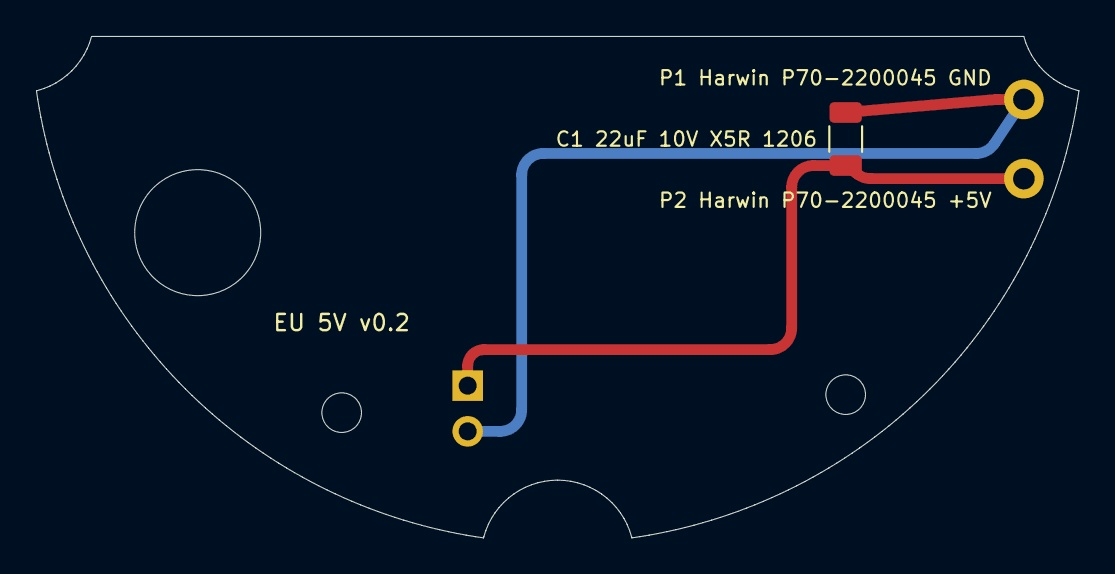
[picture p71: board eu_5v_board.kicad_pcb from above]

Board: 2 copper layers, 57.9 x 27.9 mm, 6 parts (1 on the bottom side), 2 nets.

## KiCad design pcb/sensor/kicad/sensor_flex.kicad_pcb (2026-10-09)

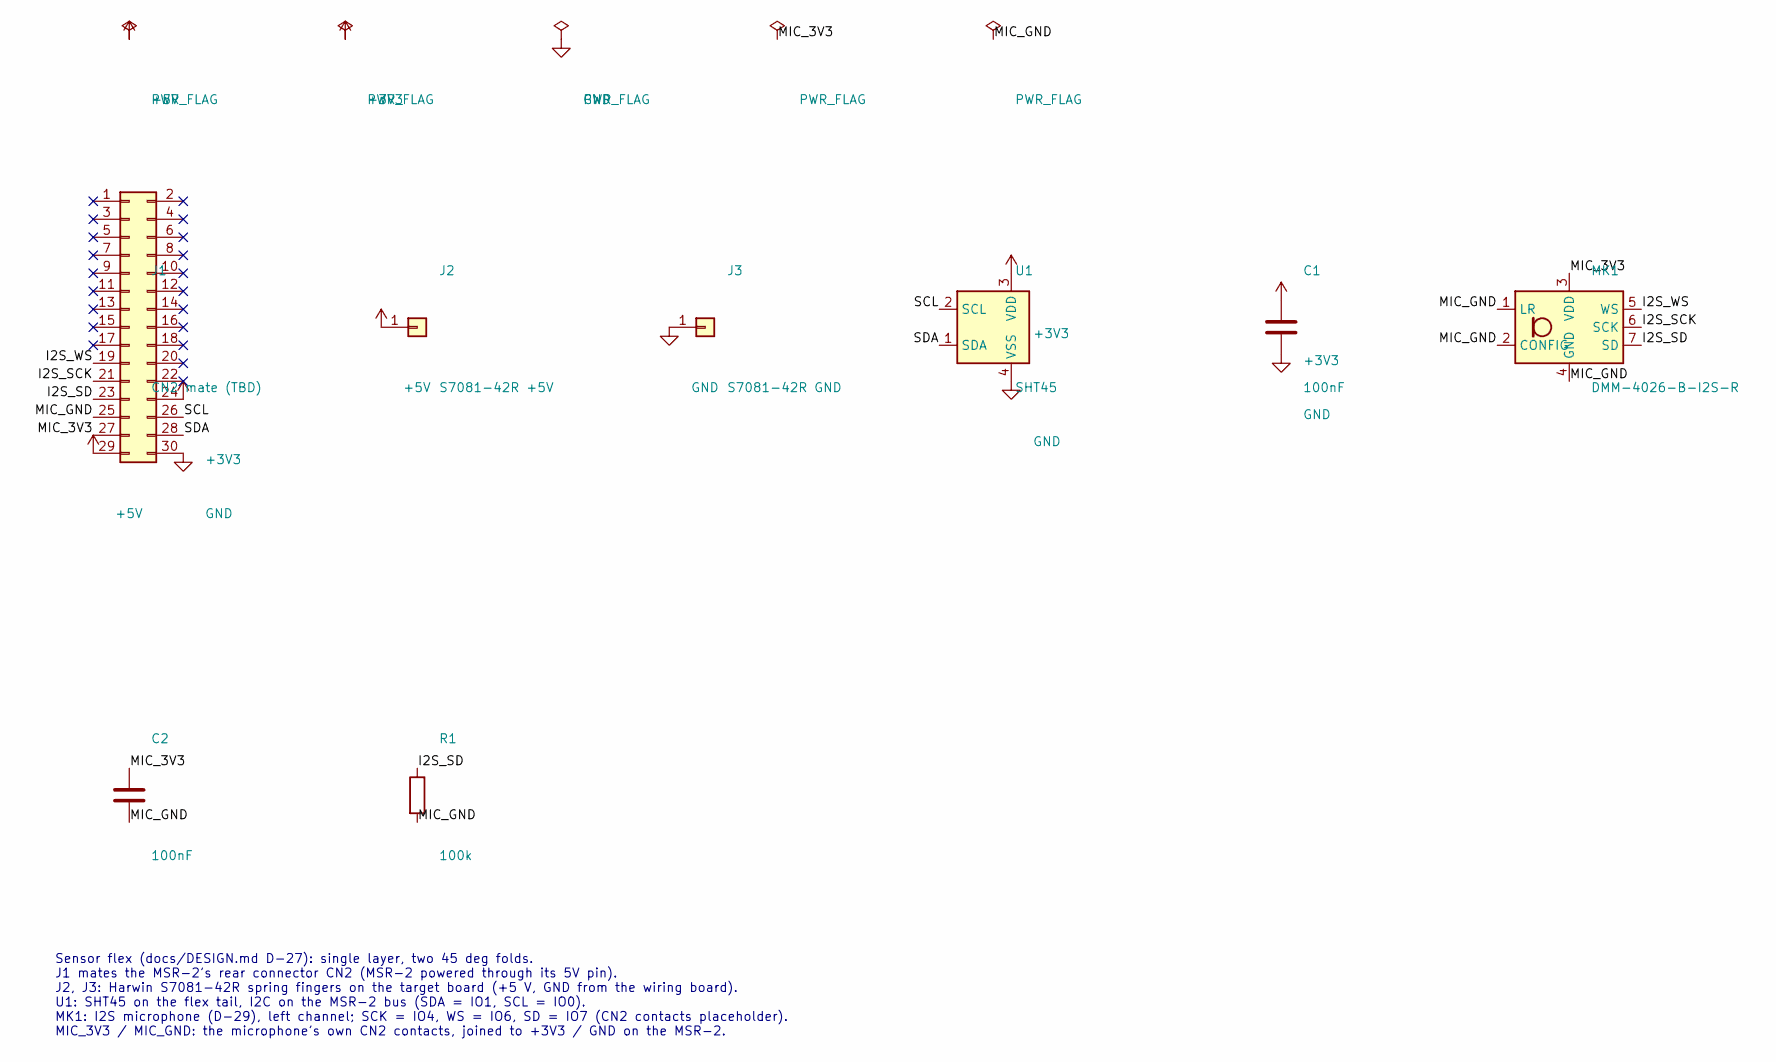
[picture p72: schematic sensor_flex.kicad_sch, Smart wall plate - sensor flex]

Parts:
C1, C2: 100nF; C_0402_1005Metric; MPN 0402 X7R 100 nF 16 V
J1: CN2 mate (TBD); B2B_0.4mm_2x15_PLACEHOLDER; MPN TBD
J2: S7081-42R +5V; Harwin_S7081-42R; MPN S7081-42R
J3: S7081-42R GND; Harwin_S7081-42R; MPN S7081-42R
MK1: DMM-4026-B-I2S-R; PUI_DMM-4026-B-I2S_4x3mm; MPN DMM-4026-B-I2S-R
R1: 100k; R_0402_1005Metric; MPN 0402 1% 100 kOhm
U1: SHT45; Sensirion_DFN-4_1.5x1.5mm_P0.8mm_SHT4x_NoCentralPad; MPN SHT45-AD1B-R2

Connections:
+3V3: C1.1, J1.24, U1.3 (VDD)
+5V: J1.29, J2.1
/I2S_SCK: J1.21, MK1.6 (SCK)
/I2S_SD: J1.23, MK1.7 (SD), R1.1
/I2S_WS: J1.19, MK1.5 (WS)
/MIC_3V3: C2.1, J1.27, MK1.3 (VDD)
/MIC_GND: C2.2, J1.25, MK1.1 (LR), MK1.2 (CONFIG), MK1.4 (GND), R1.2
/SCL: J1.26, U1.2 (SCL)
/SDA: J1.28, U1.1 (SDA)
GND: C1.2, J1.30, J3.1, U1.4 (VSS)

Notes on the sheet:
Sensor flex (docs/DESIGN.md D-27): single layer, two 45 deg folds. J1 mates the MSR-2's rear connector CN2 (MSR-2 powered through its 5V pin). J2, J3: Harwin S7081-42R spring fingers on the target board (+5 V, GND from the wiring board). U1: SHT45 on the flex tail, I2C on the MSR-2 bus (SDA = IO1, 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

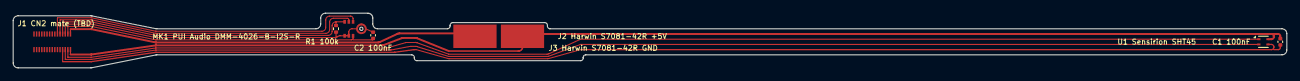
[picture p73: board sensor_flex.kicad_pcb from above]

Board: 2 copper layers, 195.7 x 8.4 mm, 8 parts (0 on the bottom side), 10 nets.

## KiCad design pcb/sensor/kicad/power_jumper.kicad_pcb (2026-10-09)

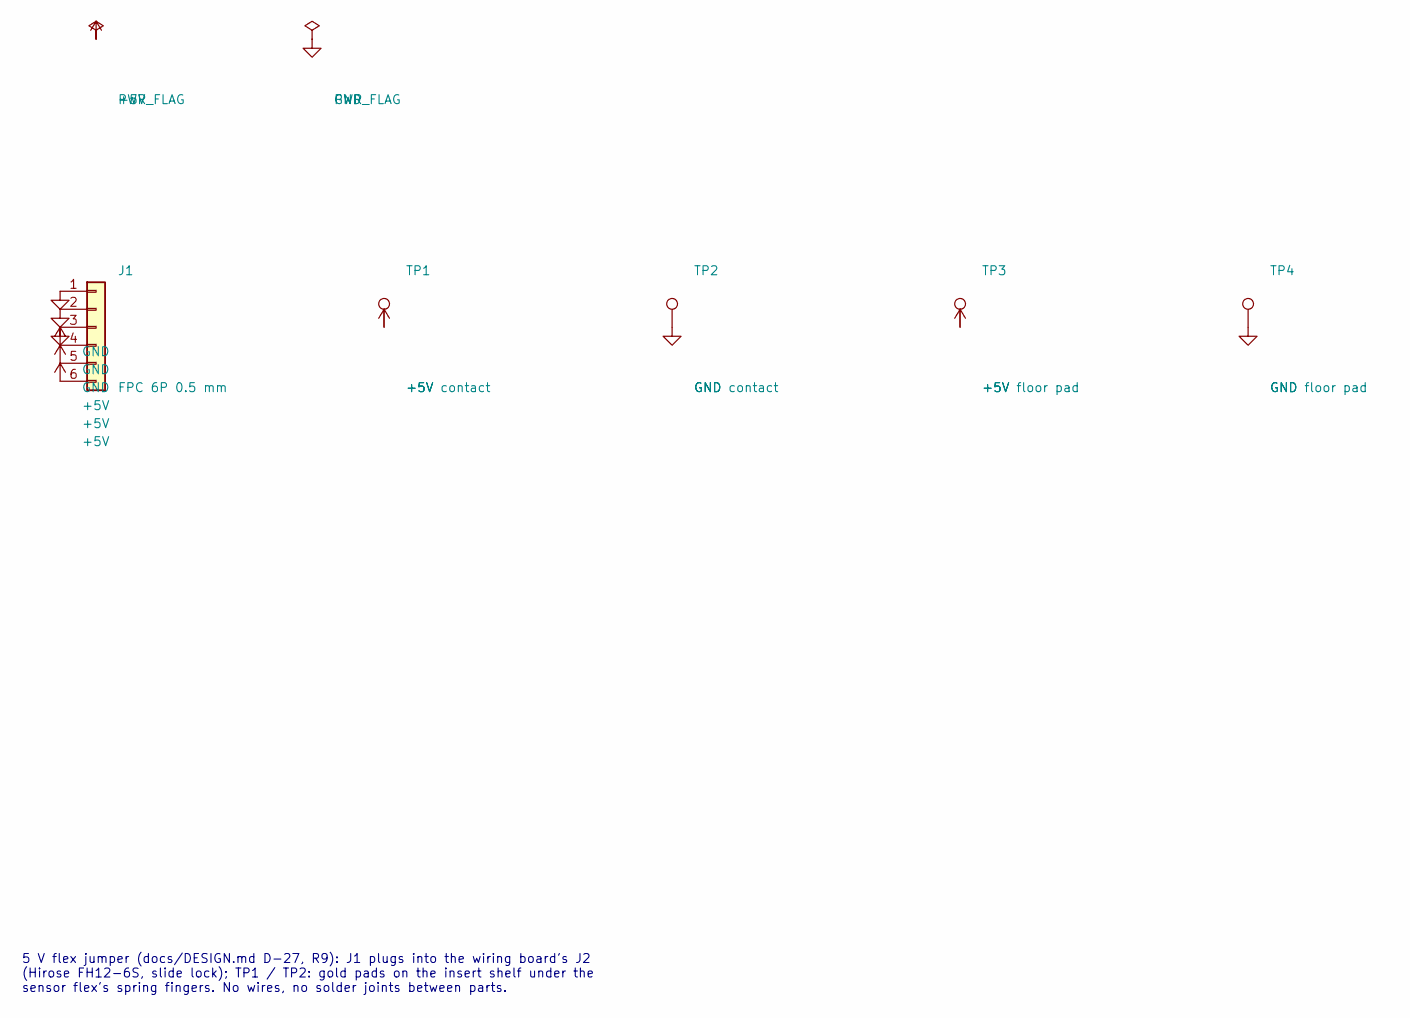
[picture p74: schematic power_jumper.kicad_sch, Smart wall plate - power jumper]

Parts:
J1: FPC 6P 0.5 mm; FPC_6P_P0.50mm_Contacts
TP1: +5V contact; Contact_Pad_2.2x4.5mm
TP2: GND contact; Contact_Pad_2.2x4.5mm
TP3: +5V floor pad; Contact_Pad_7x4mm
TP4: GND floor pad; Contact_Pad_7x4mm

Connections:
+5V: J1.4, J1.5, J1.6, TP1.1, TP3.1
GND: J1.1, J1.2, J1.3, TP2.1, TP4.1

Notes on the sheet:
5 V flex jumper (docs/DESIGN.md D-27, R9): J1 plugs into the wiring board's J2 (Hirose FH12-6S, slide lock); TP1 / TP2: gold pads on the insert shelf under the sensor flex's spring fingers. No wires, no solder joints between parts.

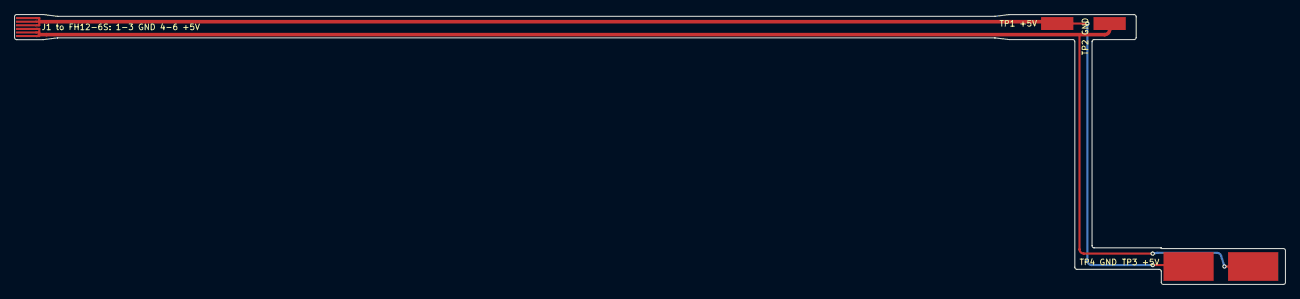
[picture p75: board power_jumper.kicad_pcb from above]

Board: 2 copper layers, 177.1 x 37.6 mm, 5 parts (0 on the bottom side), 2 nets.

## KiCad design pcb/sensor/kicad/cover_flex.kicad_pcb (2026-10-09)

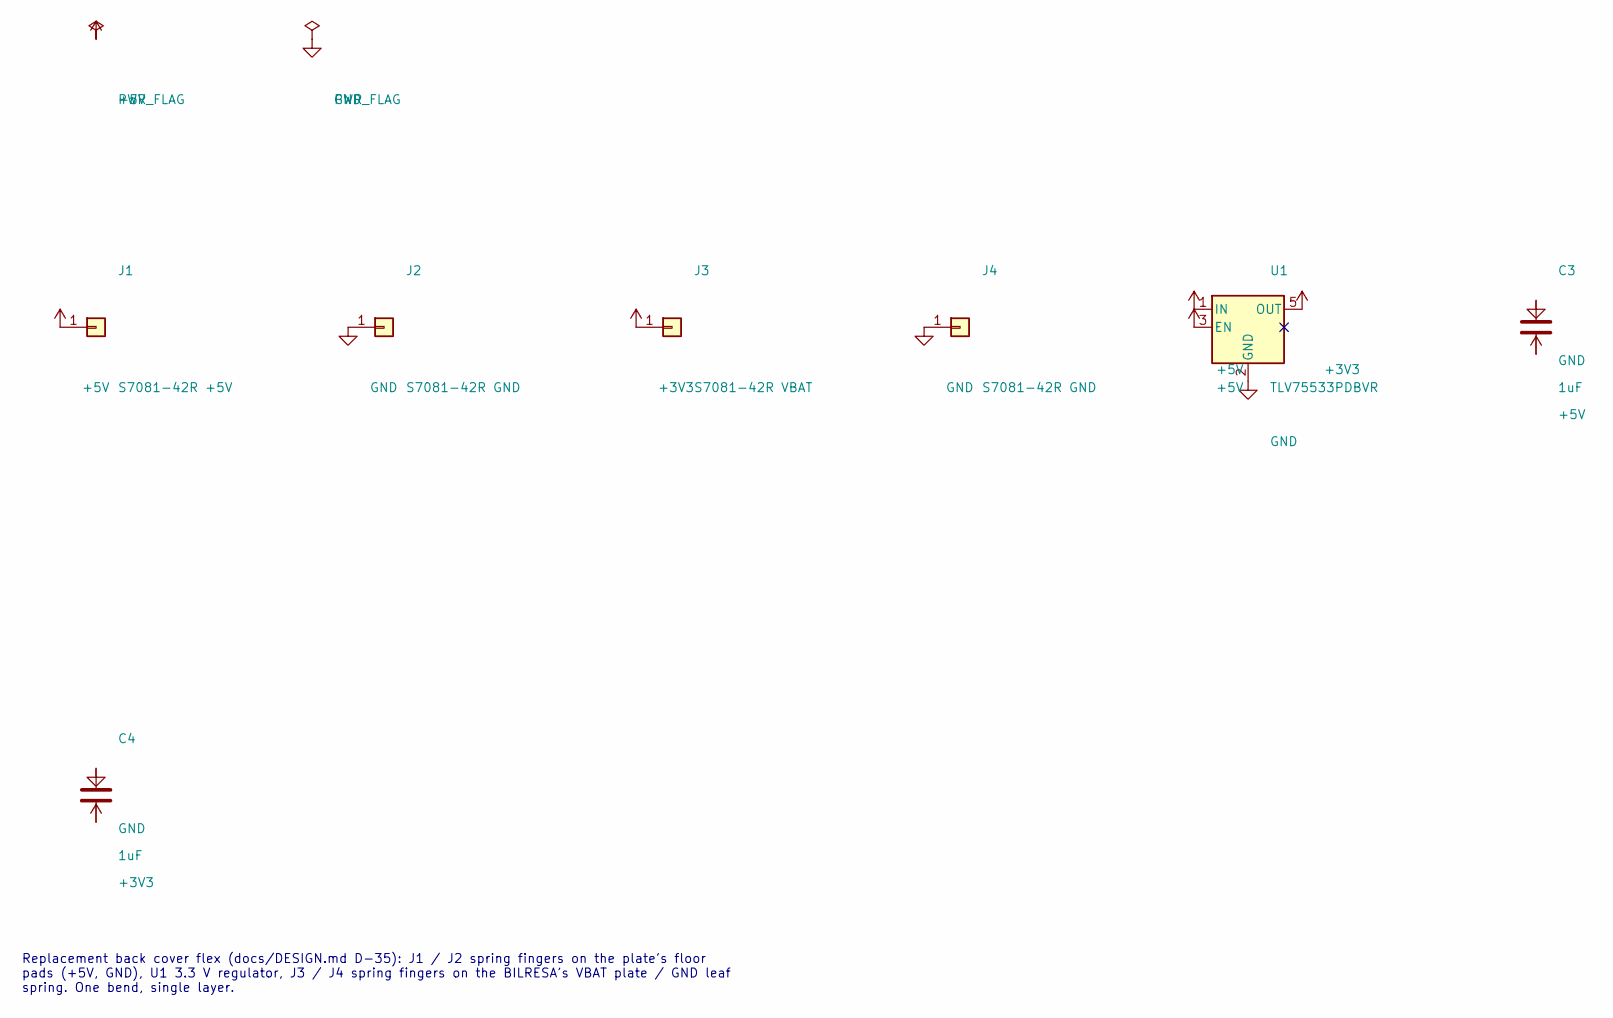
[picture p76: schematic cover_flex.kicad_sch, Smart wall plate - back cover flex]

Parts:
C3, C4: 1uF; C_0402_1005Metric; MPN GRM155R61A105KE15D
J1: S7081-42R +5V; Harwin_S7081-42R; MPN S7081-42R
J2, J4: S7081-42R GND; Harwin_S7081-42R; MPN S7081-42R
J3: S7081-42R VBAT; Harwin_S7081-42R; MPN S7081-42R
U1: TLV75533PDBVR; SOT-23-5; MPN TLV75533PDBVR

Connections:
+3V3: C4.2, J3.1, U1.5 (OUT)
+5V: C3.2, J1.1, U1.1 (IN), U1.3 (EN)
GND: C3.1, C4.1, J2.1, J4.1, U1.2 (GND)

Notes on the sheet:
Replacement back cover flex (docs/DESIGN.md D-35): J1 / J2 spring fingers on the plate's floor pads (+5V, GND), U1 3.3 V regulator, J3 / J4 spring fingers on the BILRESA's VBAT plate / GND leaf spring. One bend, single layer.

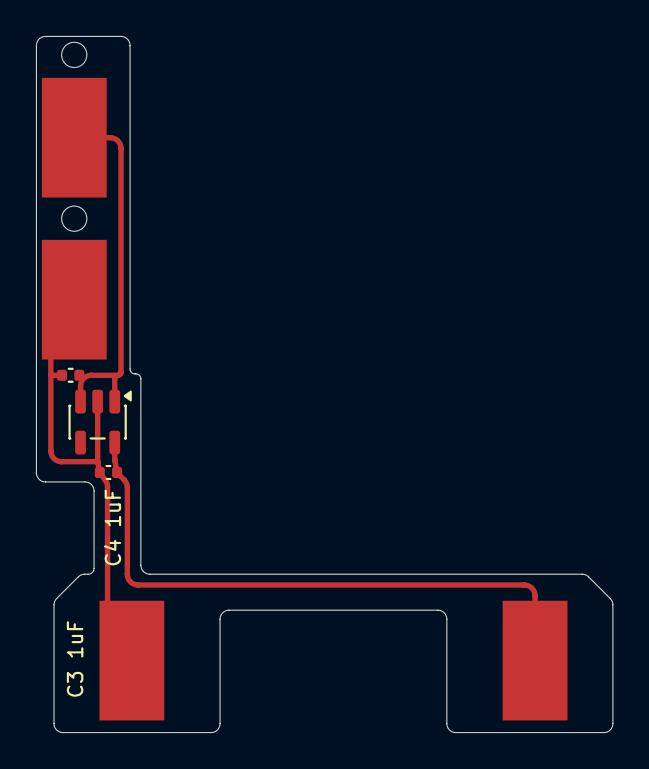
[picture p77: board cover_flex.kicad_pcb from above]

Board: 2 copper layers, 32.0 x 38.7 mm, 7 parts (0 on the bottom side), 3 nets.

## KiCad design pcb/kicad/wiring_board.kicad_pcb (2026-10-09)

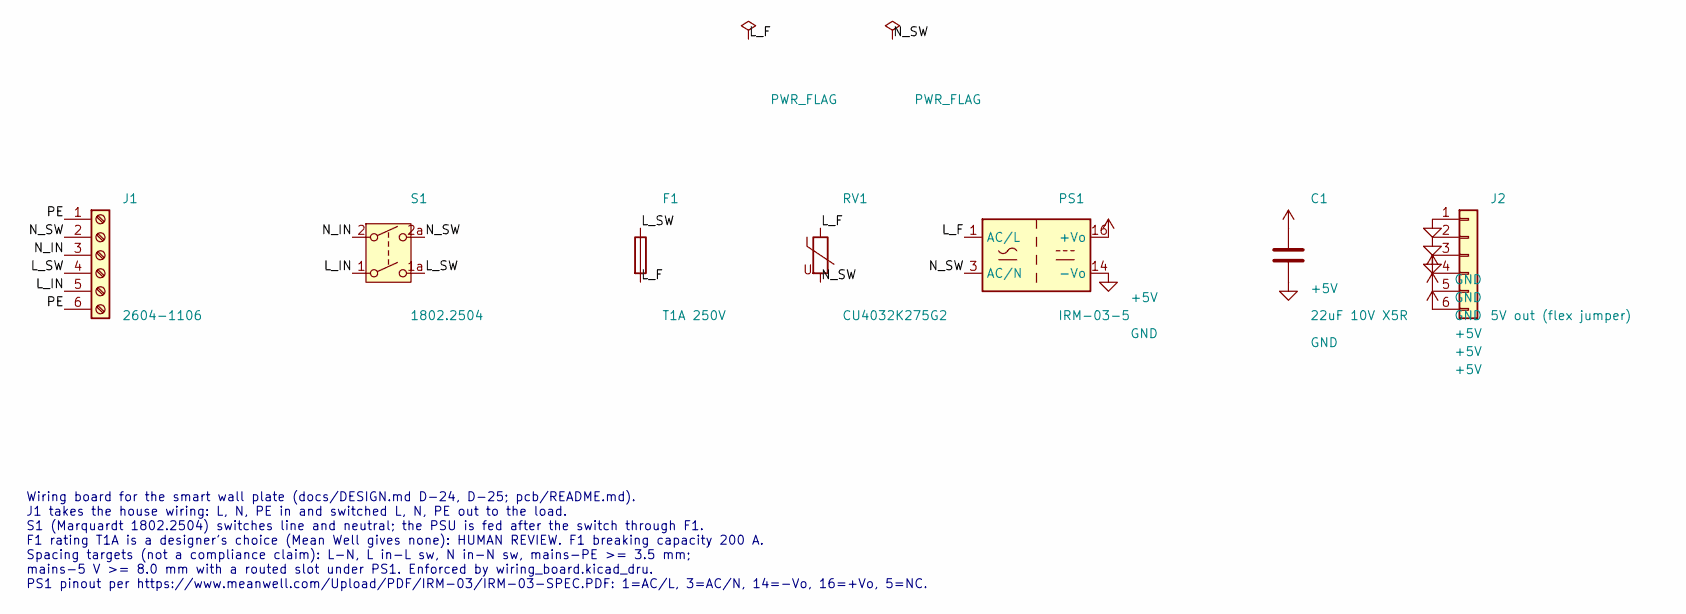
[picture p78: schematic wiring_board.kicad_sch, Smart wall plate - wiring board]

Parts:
C1: 22uF 10V X5R; C_1206_3216Metric; MPN GRM31CR61A226KE19L
F1: T1A 250V; Fuse_Schurter_UMT250; MPN 3404.2416.22
J1: 2604-1106; WAGO_2604-1106_1x06_P5.00mm_Horizontal; MPN 2604-1106
J2: 5V out (flex jumper); Hirose_FH12-6S-0.5SH_1x06-1MP_P0.50mm_Horizontal; MPN FH12-6S-0.5SH(55)
PS1: IRM-03-5; Converter_ACDC_MeanWell_IRM-03-xx_THT; MPN IRM-03-5
RV1: CU4032K275G2; Varistor_TDK_CU4032; MPN B72660M0271K093
S1: 1802.2504; Marquardt_1802.2504_DPST_PCB; MPN 1802.2504

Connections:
+5V: C1.1, J2.4, J2.5, J2.6, PS1.16 (+Vo)
/L_F: F1.2, PS1.1 (AC/L), RV1.1
/L_IN: J1.5, S1.1
/L_SW: F1.1, J1.4, S1.1a (2)
/N_IN: J1.3, S1.2 (3)
/N_SW: J1.2, PS1.3 (AC/N), RV1.2, S1.2a (4)
/PE: J1.1, J1.6
GND: C1.2, J2.1, J2.2, J2.3, PS1.14 (-Vo)

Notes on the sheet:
Wiring board for the smart wall plate (docs/DESIGN.md D-24, D-25; pcb/README.md). J1 takes the house wiring: L, N, PE in and switched L, N, PE out to the load. S1 (Marquardt 1802.2504) switches line and neutral; the PSU is fed after the switch through F1. F1 rating T1A is a designer's choice (Mean 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



Board: 2 copper layers, 47.0 x 72.0 mm, 13 parts (2 on the bottom side), 8 nets.

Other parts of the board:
LOGO1: Ant_Logo_8mm_SilkScreen
LOGO2: KiCad-Logo2_5mm_SilkScreen
MH1, MH2, MH3, MH4: MountingHole_2.6mm_NPTH

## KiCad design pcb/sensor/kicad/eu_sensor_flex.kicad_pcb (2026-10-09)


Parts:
C1, C2: 100nF; C_0402_1005Metric; MPN 0402 X7R 100 nF 16 V
J1: CN2 mate (TBD); B2B_0.4mm_2x15_PLACEHOLDER; MPN TBD
MK1: DMM-4026-B-I2S-R; PUI_DMM-4026-B-I2S_4x3mm; MPN DMM-4026-B-I2S-R
R1: 100k; R_0402_1005Metric; MPN 0402 1% 100 kOhm
TP1: GND pin pad; Contact_Pad_D2.4mm
TP2: +5V pin pad; Contact_Pad_D2.4mm
TP3: +5V floor pad; Contact_Pad_2.9x7mm
TP4: GND floor pad; Contact_Pad_2.9x7mm
U1: SHT45; Sensirion_DFN-4_1.5x1.5mm_P0.8mm_SHT4x_NoCentralPad; MPN SHT45-AD1B-R2

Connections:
+3V3: C1.1, J1.29, U1.3 (VDD)
+5V: J1.21, TP2.1, TP3.1
/GND_SHT: C1.2, J1.23, U1.4 (VSS)
/I2S_SCK: J1.26, MK1.6 (SCK)
/I2S_SD: J1.24, MK1.7 (SD), R1.2
/I2S_WS: J1.28, MK1.5 (WS)
/MIC_3V3: C2.1, J1.20, MK1.3 (VDD)
/MIC_GND: C2.2, J1.22, MK1.1 (LR), MK1.2 (CONFIG), MK1.4 (GND), R1.1
/SCL: J1.27, U1.2 (SCL)
/SDA: J1.25, U1.1 (SDA)
GND: J1.19, TP1.1, TP4.1

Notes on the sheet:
EU sensor flex (docs/DESIGN.md D-30, D-41): single layer, two 45 deg folds and the tongue's. J1 mates the MSR-2's rear connector CN2 (MSR-2 powered through its 5V pin). TP1 / TP2: pads under the 5 V board's spring pins (GND, +5 V). TP3 / TP4: floor pads under the replacement back cover's fingers (+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


Board: 2 copper layers, 171.3 x 30.4 mm, 10 parts (0 on the bottom side), 11 nets.

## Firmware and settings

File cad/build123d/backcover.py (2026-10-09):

"""REPLACEMENT BACK COVER (D-35): replaces the BILRESA E2490's back cover; the remote runs without
cells from the plate's +3V3.

The cover keeps the remote's back shape (cut to a 45 deg chamfer below the curve's 45 deg point,
so it prints back down without supports) and carries the remote's steel plate. Inside, a
single-layer flex lies copper down on a ledge BC_FLEX_Z above the back face; two Harwin S7081-42R
spring fingers on it reach down through windows in the back. The flex runs to the terminal end,
bends up once and stands against two contact blocks; two more S7081-42R fingers on it, on the cell
axes, press on the remote's VBAT (fixed plate) and GND (leaf spring) battery contacts. The fingers
on the back take +5 V; a 3.3 V regulator on the flex (copper down, in a recess in the cover) feeds
VBAT. No cells: the remote's strap joins the bridge-end contacts.

On the face plate side a printed pocket-floor insert carries a tongue of the sensor flex in a
recess, its two gold pads flush under the fingers. The magnet holds the cover's back down on the
insert: that hard stop sets the fingers' working height.

Remote coordinates: origin = remote centre, x / y as the front view, z = 0 the back's outer face.
Sizes marked MEASURE / REF in params.py.
"""
from math import atan2, cos, degrees, pi, sin, sqrt
from build123d import Axis, Box, Cylinder, Plane, Pos, Rot, chamfer, loft
from params import *
from common import stadium, slab
import bilresa

Z_BEND = BC_FLEX_Z + FLEX_T / 2                          # flex mid-plane on the ledge
EDGE_C = 2 * B_BACK_RUN * (1 - sqrt(2) / 2)              # 45 deg chamfer tangent to the R B_BACK_RUN back curve


def copper_y():
    """y of the end section's copper face: FINGER_WH from the fixed contact plate, towards the cells."""
    return BC_COPPER_Y


def stiffener_y():
    """y of the stiffener's far face (towards the cells): the contact blocks start here."""
    return copper_y() - BC_TERM_Y * (FLEX_T + BC_END_T)


def end_blocks():
    """End section outline in the (x, z) plane: two pad blocks and the band under the PCB strip."""
    z0, z1 = BC_FLEX_Z, BC_FLEX_Z + BC_END_H
    xi = BC_PCB_W / 2 + BC_PCB_CLR
    xo = BC_CELL_X + BC_CONTACT_W / 2 + 0.5
    return [(-xo, -xi, z0, z1), (xi, xo, z0, z1), (-xi, xi, z0, z0 + BC_BRIDGE_H)]


def strip_top():
    return max(y for _, y in BC_FINGERS) + FINGER[1] / 2 + BC_PEG_END


def strip_bottom():
    """Lower end of the pad section; the run continues to the terminal end after BC_JOG."""
    return min(y for _, y in BC_FINGERS) - FINGER[1] / 2 - 1.0


def strip_boxes(clr=0.0):
    """Flex path on the ledge as (x0, x1, y0, y1): pad section, jog, run to the terminal end."""
    yc = copper_y()
    yt, yb = strip_top(), strip_bottom()
    yj = yb - BC_JOG
    xs0, xs1 = BC_STRIP
    xr0, xr1 = BC_RUN
    return [(xs0 - clr, xs1 + clr, yb, yt), (min(xs0, xr0) - clr, max(xs1, xr1) + clr, yj, yb),
            (xr0 - clr, xr1 + clr, min(yc, yj), max(yc, yj))]


def back_shape(inset=0.0, lift=0.0):
    """The remote's back (flat pad, quarter-circle round-over, straight sides) inset by `inset` all
    round and raised by `lift`. Below the curve's 45 deg point the round-over is replaced by its
    45 deg tangent (a frustum), so the cover prints back down without supports."""
    n = bilresa.N_SECT
    secs = []
    for i in range(n // 2, n + 1):                        # from the 45 deg point up
        t = (pi / 2) * i / n
        run = B_BACK_RUN * (1 - sin(t)) + inset
        secs.append(Plane.XY.offset(lift + B_BACK_RISE * (1 - cos(t))) * stadium(B_W - 2 * run, B_H - 2 * run))
    w, h = B_W - 2 * inset, B_H - 2 * inset
    zt = EDGE_C / 2                                       # height of the 45 deg point (n even)
    frustum = chamfer(slab(stadium(w, h), lift, lift + B_SEAM_Z).edges().group_by(Axis.Z)[0], EDGE_C)
    frustum &= Pos(0, 0, lift + zt / 2) * Box(B_W + 2, B_H + 2, zt)
    top = slab(stadium(w, h), lift + B_BACK_RISE - 0.01, lift + B_SEAM_Z + 5)
    return frustum + loft(secs, ruled=False) + top


def outer():
    return back_shape() & Pos(0, 0, B_SEAM_Z / 2) * Box(B_W + 2, B_H + 2, B_SEAM_Z)


def shell():
    """Cover shell: back_shape hollowed by BC_WALL (inset sideways and raised), open at the seam."""
    return outer() - back_shape(BC_WALL, BC_WALL)


def corner_cuts():
    """45 deg prisms removing the end section's lower outer corners (flex outline follows)."""
    out = None
    yc = copper_y()
    for sx in (-1, 1):
        xo = BC_CELL_X + BC_CONTACT_W / 2 + 0.5
        c = Pos(sx * xo, yc, BC_FLEX_Z) * Rot(0, 45, 0) * Box(BC_END_CORNER * sqrt(2), 10, BC_END_CORNER * sqrt(2))
        out = c if out is None else out + c
    return out


def latches():
    """Snap clips at both ends (x = 0): columns standing on the shell's curved inner surface (fused into it at the
    base, a gap to the end wall above it), tops BC_LATCH_TOPS above the inside floor, a hook at the tip pointing
    inwards over the housing's wall (45 deg top, so the cover prints back down without supports)."""
    from build123d import Polyline, Plane, extrude, make_face
    out = None
    yc = B_H / 2 - BC_LATCH_IN                          # clip centre line (outwards distance from the remote centre)
    t, h = BC_LATCH_T, BC_LATCH_HOOK
    yi, yo = yc - t / 2, yc + t / 2                     # clip faces (inner, outer)
    for s, top_in in ((-1, BC_LATCH_TOPS[0]), (1, BC_LATCH_TOPS[1])):
        top = BC_WALL + top_in
        pts = [(yi, 0.3), (yo, 0.3), (yo, top), (yi - h, top - h), (yi - h, top - 2 * h), (yi, top - 3 * h), (yi, 0.3)]
        prof = extrude(Plane.YZ * make_face(Polyline(*pts)), BC_LATCH_W / 2, both=True)   # profile y / z, along x
        prof &= back_shape(0.0, 0.0)                    # not through the outside
        e = prof if s > 0 else prof.mirror(Plane.XZ)
        out = e if out is None else out + e
    return out


def side_tabs():
    """Free-standing ribs at mid-length, BC_SIDE_TAB_GAP apart on their inner faces, from the shell's curved floor up
    to just below the rim (no hook): they keep the sides from flexing."""
    w, t, rise = BC_SIDE_TAB
    x0 = BC_SIDE_TAB_GAP / 2                            # rib's inner face
    z0, z1 = 0.5, BC_WALL + rise                        # from inside the shell (fuses with it), top above the floor
    out = None
    for s in (1, -1):
        tab = Pos(s * (x0 + t / 2), 0, (z0 + z1) / 2) * Box(t, w, z1 - z0)
        out = tab if out is None else out + tab
    out &= back_shape(0.0, 0.0) + Pos(0, 0, 50 + B_SEAM_Z - 0.01) * Box(200, 200, 100)   # not through the outside
    return out


def cover():
    """Printed cover: shell, flex ledge, contact blocks, finger windows, steel-plate pocket, snap ears, side tabs."""
    body = shell()
    yc, ys = copper_y(), stiffener_y()
    for x0, x1, y0, y1 in strip_boxes():
        body += Pos((x0 + x1) / 2, (y0 + y1) / 2, (BC_WALL + BC_FLEX_Z) / 2 - 0.25) * Box(x1 - x0, y1 - y0,
                                                                                       BC_FLEX_Z - BC_WALL + 0.5)
    for a, b, z0, z1 in end_blocks()[:2]:
        yb = ys - BC_TERM_Y * BC_BLOCK_T / 2
        body += Pos((a + b) / 2, yb, (BC_WALL + z1) / 2 - 0.25) * Box(b - a, BC_BLOCK_T, z1 - BC_WALL + 0.5)
    body += end_retainers()
    # slot under the GND contact block for the run (the flex slides in from the cell side)
    xr0, xr1 = BC_RUN
    yb = ys - BC_TERM_Y * BC_BLOCK_T / 2
    body -= Pos((xr0 + xr1) / 2, yb, BC_FLEX_Z + (FLEX_T + 0.08) / 2) * Box(xr1 - xr0 + 0.3, BC_BLOCK_T + 1.0,
                                                                            FLEX_T + 0.08)
    for x0, x1, y0, y1 in strip_boxes(0.1):               # relief over the flex where the 45 deg fill reaches it
        body -= Pos((x0 + x1) / 2, (y0 + y1) / 2, BC_FLEX_Z + (FLEX_T + 0.3) / 2) * Box(x1 - x0, y1 - y0, FLEX_T + 0.3)
    body &= Pos(0, 0, 50) * Box(200, 200, 100)                             # nothing below the back face
    body &= outer() + Pos(0, 0, 50 + B_SEAM_Z - 0.01) * Box(200, 200, 100)  # blocks may rise above the seam
    body += latches() + side_tabs()
    w, d = BC_PRY                                       # flat-blade screwdriver notch in the rim at the bottom end
    body -= Pos(0, -B_H / 2, B_SEAM_Z - d / 2 + 0.01) * Box(w, 2 * (BC_WALL + 1.0), d + 0.02)
    for x, y in BC_FINGERS:
        body -= Pos(x, y, BC_FLEX_Z / 2) * Box(FINGER[0] + 2 * BC_WIN_CLR, FINGER[1] + 2 * BC_WIN_CLR, BC_FLEX_Z + 1.0)
    cw, ct, ch, cg = BC_STEEL_CLIP
    ext = 0.15 + ct + cg                                 # pocket longer at both ends for the clips
    body -= Pos(0, BC_STEEL_Y, BC_STEEL_FLOOR + 5.0) * Box(BC_STEEL[0] + 0.3, BC_STEEL[1] + 0.3 + 2 * ext, 10.0)
    body += steel_clips() + pegs()
    x0, x1, y0, y1 = BC_REG_RECESS
    body -= Pos((x0 + x1) / 2, (y0 + y1) / 2, (BC_STEEL_FLOOR + BC_FLEX_Z) / 2) * Box(x1 - x0, y1 - y0,
                                                                                      BC_FLEX_Z - BC_STEEL_FLOOR)
    return body


def pegs():
    """Heat-stake pegs on the ledge through the flex and its pad-section stiffener (melted over at assembly)."""
    from build123d import Cylinder
    z0, z1 = BC_FLEX_Z - 0.3, BC_FLEX_Z + FLEX_T + BC_PAD_STIFF_T + BC_PEG_STAKE
    out = None
    for x, y in BC_PEGS:
        p = Pos(x, y, (z0 + z1) / 2) * Cylinder(BC_PEG_D / 2, z1 - z0)
        out = p if out is None else out + p
    return out


def peg_holes(z0, z1):
    from build123d import Cylinder
    out = None
    for x, y in BC_PEGS:
        h = Pos(x, y, (z0 + z1) / 2) * Cylinder(BC_PEG_HOLE / 2, z1 - z0)
        out = h if out is None else out + h
    return out


def pad_stiffener():
    """FR4 on the flex's pad and regulator sections (non-copper side), with the peg holes."""
    z0 = BC_FLEX_Z + FLEX_T
    out = None
    for x0, x1, y0, y1 in strip_boxes()[:2]:
        s = Pos((x0 + x1) / 2, (y0 + y1) / 2, z0 + BC_PAD_STIFF_T / 2) * Box(x1 - x0, y1 - y0, BC_PAD_STIFF_T)
        out = s if out is None else out + s
    return out - peg_holes(z0 - 0.1, z0 + BC_PAD_STIFF_T + 0.1)


def end_retainers():
    """End section retention on each contact block: a lip in front of its foot (the section's lower edge drops into
    the slot between lip and stiffener) and a hook on its top over the section's top edge (snaps in, 45 deg lead-in;
    printed back down: the hook's underside is the only overhang, BC_END_HOOK wide)."""
    from build123d import Polyline, Plane, extrude, make_face
    t, h, gap = BC_END_LIP
    yc = copper_y()
    sy = -BC_TERM_Y                                      # +1: cells side (blocks) is +y
    ys = stiffener_y()                                   # stiffener's far face (the blocks start here)
    out = None
    for a, b, z0, z1 in end_blocks()[:2]:
        a2, b2 = a + 0.5, b - 1.6                        # clear of the 45 deg corner cut and the notch side
        y_l0, y_l1 = yc - sy * gap, yc - sy * (gap + t)  # lip faces
        lip = Pos((a2 + b2) / 2, (y_l0 + y_l1) / 2, (BC_WALL + BC_FLEX_Z + h) / 2) * Box(
            b2 - a2, t, BC_FLEX_Z + h - BC_WALL)
        # hook: from the block's top over the stiffener and flex to the copper face, lead-in on top
        y_b, y_f = ys, yc - sy * BC_END_HOOK
        hk = BC_END_HOOK
        pts = [(y_b + sy * 0.5, z1), (y_b + sy * 0.5, z1 + 1.2), (y_f, z1 + 0.2 + hk), (y_f, z1), (y_b + sy * 0.5, z1)]
        prof = extrude(Plane.YZ * make_face(Polyline(*pts)), (b2 - a2) / 2, both=True)
        part = lip + Pos((a2 + b2) / 2, 0, 0) * prof
        out = part if out is None else out + part
    return out


def flex():
    """The flex in place (FLEX_T thick): pad section and strip on the ledge, end section up the blocks."""
    yc = copper_y()
    yf = yc - BC_TERM_Y * FLEX_T / 2
    out = None
    for x0, x1, y0, y1 in strip_boxes():
        b = Pos((x0 + x1) / 2, (y0 + y1) / 2, Z_BEND) * Box(x1 - x0, y1 - y0, FLEX_T)
        out = b if out is None else out + b
    for a, b, z0, z1 in end_blocks():
        out += Pos((a + b) / 2, yf, (z0 + z1) / 2) * Box(b - a, FLEX_T, z1 - z0)
    return out - corner_cuts() - peg_holes(BC_FLEX_Z - 0.1, BC_FLEX_Z + FLEX_T + 0.1)


def stiffener():
    ys = copper_y() - BC_TERM_Y * (FLEX_T + BC_END_T / 2)
    out = None
    for a, b, z0, z1 in end_blocks():
        s = Pos((a + b) / 2, ys, (z0 + z1) / 2) * Box(b - a, BC_END_T, z1 - z0)
        out = s if out is None else out + s
    return out - corner_cuts()


def pads():
    """The contact fingers' solder pads on the end section's copper face."""
    yc = copper_y()
    out = None
    for sx in (-1, 1):
        p = Pos(sx * BC_CELL_X, yc + BC_TERM_Y * 0.01, BC_CELL_Z) * Box(FINGER_PAD[1], 0.02, FINGER_PAD[0])
        out = p if out is None else out + p
    return out


def end_fingers(h=FINGER_WH):
    """S7081-42R on the end section at the cell axes, domes towards the terminals; long axis vertical with the
    bend end up, so the battery contacts ride down the arm's ramp onto the dome as the cover goes on."""
    out = None
    for sx in (-1, 1):
        f = Pos(sx * BC_CELL_X, copper_y(), BC_CELL_Z) * Rot(90 * BC_TERM_Y, 0, 0) * finger(h)
        out = f if out is None else out + f
    return out


def finger(h):
    """One S7081-42R (drawing iss. 7) hanging from the flex underside at height h: foot on the flex,
    arm down from the bend end, contact dome at the bottom. Local: long axis y, origin at the body centre."""
    foot = Pos(0, 0, -0.075) * Box(FINGER[0], FINGER[1], 0.15)
    yb = -FINGER[1] / 2 + 0.3                             # bend end
    yd = BC_DOME_DY                                       # dome
    run, drop = yd - yb, h - 0.15 - 0.33
    length = sqrt(run * run + drop * drop)
    ang = degrees(atan2(drop, run))
    arm = Pos(0, (yb + yd) / 2, -0.15 - drop / 2) * Rot(-ang, 0, 0) * Box(FINGER[0] - 0.4, length, 0.15)
    dome = Pos(0, yd, -h + 0.33 / 2) * Cylinder(1.3 / 2, 0.33)
    return foot + arm + dome


def fingers(h=FINGER_WH):
    out = None
    for x, y in BC_FINGERS:
        f = Pos(x, y, BC_FLEX_Z) * finger(h)
        out = f if out is None else out + f
    return out


def regulator():
    """TLV75533 and its two capacitors hanging from the flex underside (copper down) into the recess."""
    out = None
    for ref, (x, y) in BC_REG.items():
        w, h, t = BC_REG_BODY if ref == "U1" else BC_CAP0402
        p = Pos(x, y, BC_FLEX_Z - t / 2) * Box(w, h, t)
        out = p if out is None else out + p
    return out


def steel_clips():
    """A clip at each end of the steel plate: a tab from the pocket floor beside the plate's end (a gap behind it to
    flex), a hook over the plate's edge with a 45 deg lead-in on top, so the plate snaps in from above."""
    from build123d import Polyline, Plane, extrude, make_face
    cw, ct, ch, cg = BC_STEEL_CLIP
    z0, zh = BC_STEEL_FLOOR, BC_STEEL_FLOOR + BC_STEEL[2] + 0.1           # pocket floor, hook underside
    out = None
    for s in (1, -1):
        ye = BC_STEEL[1] / 2 + 0.15                     # tab inner face, outwards distance from the plate centre
        pts = [(ye, z0 - 0.01), (ye + ct, z0 - 0.01), (ye + ct, zh + 2 * ch), (ye - ch, zh + ch), (ye - ch, zh),
               (ye, zh), (ye, z0 - 0.01)]
        prof = extrude(Plane.YZ * make_face(Polyline(*pts)), cw / 2, both=True)
        c = Pos(0, BC_STEEL_Y, 0) * (prof if s > 0 else prof.mirror(Plane.XZ))
        out = c if out is None else out + c
    return out


def steel():
    return Pos(0, BC_STEEL_Y, BC_STEEL_FLOOR + BC_STEEL[2] / 2 + 0.01) * Box(*BC_STEEL)


def cover_parts(free=False):
    """The cover assembly in remote coordinates (fingers free or at working height)."""
    h = FINGER_FREE if free else FINGER_WH
    return {"cover": cover(), "flex": flex(), "stiffener": stiffener(), "pads": pads(),
            "fingers": fingers(h), "contacts": end_fingers(h), "regulator": regulator(), "steel": steel(),
            "pad_stiffener": pad_stiffener()}


def tongue_path(wall_x):
    """Sensor-flex tongue in the floor insert: (x0, x1, y0, y1, layers) boxes. It enters along y =
    BC_TONGUE_Y from the right channel (copper down, as the flex's pin pads), folds 45 deg under the
    pads' column (copper up) and runs up past both pads."""
    w = BC_TONGUE_W
    xf = BC_FINGERS[0][0]
    ys = [y for _, y in BC_FINGERS]
    y_top = max(ys) + BC_FLOOR_PAD[1] / 2 + 1.0
    run = (xf + w / 2, wall_x, BC_TONGUE_Y - w / 2, BC_TONGUE_Y + w / 2, 1)
    fold = (xf - w / 2, xf + w / 2, BC_TONGUE_Y - w / 2, BC_TONGUE_Y + w / 2, 2)
    up = (xf - w / 2, xf + w / 2, BC_TONGUE_Y + w / 2, y_top, 1)
    return [run, fold, up]


def floor_insert(pocket_in, wall_x, cutouts=(), path=None, pads=None):
    """Pocket-floor insert (face plate side), z = 0 its underside: printed floor with the tongue's
    recess, the tongue, its flush pads. cutouts: (x, y, w, h) openings (switch, trim tabs, bosses),
    each with BC_FLOOR_CLR all round. path: the tongue's (x0, x1, y0, y1, layers) boxes on the floor
    (default: tongue_path(wall_x)). pads: (x0, x1, y0, y1) of the flush pads (default: BC_FLOOR_PAD under the
    fingers)."""
    w, h = pocket_in[0] - 2 * BC_FLOOR_CLR, pocket_in[1] - 2 * BC_FLOOR_CLR
    plate = slab(stadium(w, h), 0, BC_FLOOR_T)
    for x, y, cw, ch in cutouts:
        plate -= Pos(x, y, BC_FLOOR_T / 2) * Box(cw + 2 * BC_FLOOR_CLR, ch + 2 * BC_FLOOR_CLR, BC_FLOOR_T + 1)
    tongue = None
    for x0, x1, y0, y1, n in (path or tongue_path(wall_x)):
        d = n * FLEX_T
        rec = Pos((x0 + x1) / 2, (y0 + y1) / 2, BC_FLOOR_T - (d + BC_RECESS_CLR) / 2 + 0.005) * \
            Box(x1 - x0 + 0.3, y1 - y0 + 0.3 * (n == 1), d + BC_RECESS_CLR + 0.01)
        plate -= rec
        t = Pos((x0 + x1) / 2, (y0 + y1) / 2, BC_FLOOR_T - d / 2) * Box(x1 - x0, y1 - y0, d)
        tongue = t if tongue is None else tongue + t
    pd = None
    for x0, x1, y0, y1 in (pads or [(x - BC_FLOOR_PAD[0] / 2, x + BC_FLOOR_PAD[0] / 2, y - BC_FLOOR_PAD[1] / 2,
                                      y + BC_FLOOR_PAD[1] / 2) for x, y in BC_FINGERS]):
        p = Pos((x0 + x1) / 2, (y0 + y1) / 2, BC_FLOOR_T + 0.005) * Box(x1 - x0, y1 - y0, 0.01)
        pd = p if pd is None else pd + p
    return {"floor": plate, "floor_flex": tongue, "floor_pads": pd}


def remote_front():
    """The remote above its parting line (its own back cover removed), z = 0 its back face."""
    r = Pos(0, 0, -SEAT_Z) * bilresa.build()
    r &= Pos(0, 0, 50 + B_SEAM_Z) * Box(200, 200, 100)
    return r


if __name__ == "__main__":
    from pathlib import Path
    from build123d import export_step, export_stl
    out = Path(__file__).resolve().parents[2] / "build"
    out.mkdir(exist_ok=True)
    c = cover()
    print("cover valid:", c.is_valid, "solids:", len(c.solids()), f"volume {c.volume / 1000:.2f} cm3")
    export_step(c, str(out / "back_cover.step"))
    export_stl(c, str(out / "back_cover.stl"))

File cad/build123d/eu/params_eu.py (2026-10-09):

"""EU variant (D-30): geometry for a round EU flush box (DIN 49073, 68 mm hole saw, Ø60 inside).

A design of its own (shares only the BILRESA, the MSR-2, the SHT45 and the microphone with the NA
plate). Coordinates as in params.py, origin = box centre = remote centre: X width, Y up, Z out of
the wall, z = 0 the wall surface, z < 0 inside the box (MAINS SIDE).

- The BILRESA cannot go below the wall in a Ø60 box (its flat back alone spans ~Ø60), so it sits
  on a 1.6 mm V-0 floor over the box, its top flush with the face: the plate stands out by the
  floor plus the remote.
- The barrier is one flat V-0 cap over the box and the seal band: the floor under the remote, a
  cup down to the panel of the emergency rocker (Marquardt 1802.2504, DPST, PCB pins) under the
  remote's upper half, two holes for the 5 V board's spring pins. Two countersunk screws into the
  box's top and bottom domes, in the pocket floor under the remote.
- The supplied magnet is glued to the floor's underside (box side), under the back cover's steel plate.
- Two boards (D-36). The mains board, at the rocker's PCB seat, carries the rocker, two WAGO
  2604-3102 push-in blocks (L in / switched, N in / switched; wires enter from the back of the box),
  fuse, MOV and the PSU (Traco TMPS 03-105) over a routed relief slot; the PSU's outputs land on a
  5 V island cut off by the slot, with a pin header. The 5 V board, just under the cap, takes 5 V
  from that header through a pin socket and carries the two spring pins that reach through the cap
  onto gold pads on the sensor flex (R9, R10). Both hang from bosses under the cap.
- The trim (PETG) carries everything visible: face, remote pocket walls, finger scoops, MSR-2 and
  SHT45 bays. Two M2 screws through tabs at the bottom of the pocket wall (under the remote's
  rounded back edge) hold it to bosses under the cap.
"""
import sys
from math import sqrt
from pathlib import Path

sys.path.insert(0, str(Path(__file__).resolve().parents[1]))
from params import (B_W, B_H, B_D, B_BACK_RUN, B_BACK_RISE, CLR, POCKET_WALL, MAGNET, MAGNET_Y, MAGNET_END_R,  # noqa: E402,F401
                    MSR, RADAR_WALL, MSR_HOOK, LUX_POS, SHT, SKIN, FACE_CHAMFER, PR, SPLIT_CLR, BARRIER_MIN, V0_RATED_T,
                    PASS_D, MSR_BOARD, MSR_CN2_IN, B2B, B2B_STACK, FLEX_W, FLEX_T, STIFF_T, FLEX_SKIN_GAP,
                    FLEX_PLUG, FLEX_NECK_L, flex_half_width, SHT_CHIP, MIC, MIC_PORT_IN, MIC_FLEX_Y, MIC_FLEX_HOLE_D,
                    MIC_GASKET_D, MIC_SKIN_HOLE_D, BC_FLOOR_T, BC_FLOOR_CLR, BC_TONGUE_W, BC_TONGUE_Y,
                    BC_FINGERS, BC_FLOOR_PAD, BC_DOME_DY, BC_STEEL_FLOOR, BC_STEEL_Y, BC_STEEL, BC_RECESS_CLR,
                    SW_CUT, SW_PANEL_T, SW_BEZEL, SW_ROCKER_H, SW_ROCKER_TOL, SW_ROCKER_CLR, SW_BODY, SW_PIN_GRID, PAD_BODY_GAP)

VARIANT = "eu"

# ---- EU flush box: DIN 49073, Ø68 hole saw ----
# Catalogue values (DIN 49073 box listings, e.g. Kaiser 1555-04; docs/MEASUREMENTS.md), not measured.
BOX_DIA = 60.0                            # MEASURE inside diameter = device opening
BOX_HOLE = 68.0                           # MEASURE hole in the wall (box rim outer diameter)
BOX_D = 47.0                              # MEASURE standard depth
DOME_PITCH = 60.0                         # MEASURE device screw domes: 4 per box at 90 deg, on the box wall
DOME_D = 7.0                              # MEASURE screw dome diameter, full box depth, top at the wall plane
DOME_CLR = 0.75                           # board / parts to a dome
SCREW_D, SCREW_HEAD_D = 3.2, 6.0          # MEASURE device screws 3.2 mm, countersunk head
PLUG_CLR = 0.75                           # cap cup / board to the box wall
COLLAR_LIP = 1.25                         # flat seal band on the wall beyond the box hole
WIRE_SPACE_MIN = 10.0                     # free depth wanted behind the deepest part (reported, not enforced: human
                                          # decision 2026-10-08, depth to be tested in a box)

# ---- emergency rocker: Marquardt 1802.2504, DPST, PCB pins (as the NA plate, D-26; values in params.py) ----
SW_Y = 12.5                               # rocker centre: cup clear of the top screw dome and of the magnet
SW_SW_DIR = -1                            # switched pins (1a / 2a) 7 mm below the in pins (1 / 2, on SW_Y)
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

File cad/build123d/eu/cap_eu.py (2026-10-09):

"""EU CAP (D-30, D-36): the whole mains / low-voltage barrier of the EU plate.

A flat 1.6 mm floor over the box and the seal band round the Ø68 hole (the remote rests on the
pocket-floor insert on it), a cup under the remote's upper half down to the emergency rocker's
panel (Marquardt 1802.2504; the rocker body plugs the cutout), bosses for the trim's two screws, for
the 5 V board and (long) for the mains board, two holes for the 5 V board's spring pins (5 V to the
flex, no wires). Two countersunk screws into the box's top and bottom domes, in the pocket floor,
fix it. The supplied magnet is glued to its underside.
Print: UL94 V-0 filament, top face down (export flips it), no supports.
Run:  python cap_eu.py  -> ../../../build/eu/cap.step / .stl
"""
from build123d import Cone, Cylinder, Pos, Rectangle
from params_eu import *
from common import rr, slab


def screw_hole(x, y):
    bore = Pos(x, y, CAP_T / 2) * Cylinder(SCREW_D / 2, CAP_T + 2)
    sink = (SCREW_HEAD_D - SCREW_D) / 2
    head = Pos(x, y, CAP_T - sink / 2 + 0.01) * Cone(SCREW_D / 2, SCREW_HEAD_D / 2, sink)
    return bore + head


def trim_bosses():
    out = None
    for sx in (-1, 1):
        b = Pos(sx * TRIM_SCREW_X, TRIM_SCREW_Y, -TRIM_BOSS_L / 2 + 0.01) * Cylinder(TRIM_BOSS_D / 2, TRIM_BOSS_L)
        out = b if out is None else out + b
    return out


def board_bosses():
    """Bosses from the floor's underside down to the 5 V board's front, M2 bores from below."""
    out = None
    for x, y in WB_MOUNT:
        b = Pos(x, y, WB_FRONT / 2 + 0.01) * Cylinder(WB_BOSS_D / 2, -WB_FRONT + 0.02)
        b -= Pos(x, y, WB_FRONT + 2.5 - 0.01) * Cylinder(WB_MOUNT_D * 0.75 / 2, 5.0)
        out = b if out is None else out + b
    return out


def mains_bosses():
    """Long bosses from the floor's underside down to the mains board's front, M2 bores from below."""
    out = None
    for x, y in MB_BOSS:
        b = Pos(x, y, MB_FRONT / 2 + 0.01) * Cylinder(MB_BOSS_D / 2, -MB_FRONT + 0.02)
        b -= Pos(x, y, MB_FRONT + 3.0 - 0.01) * Cylinder(WB_MOUNT_D * 0.75 / 2, 6.0)
        out = b if out is None else out + b
    return out


def trim_bores():
    """Blind tap-drill bores for the trim screws: through the floor into the bosses, closed at the bottom."""
    out = None
    depth = CAP_T + TRIM_BOSS_L - 1.0
    for sx in (-1, 1):
        b = Pos(sx * TRIM_SCREW_X, TRIM_SCREW_Y, CAP_T - depth / 2 + 0.01) * Cylinder(TRIM_SCREW_D * 0.8 / 2, depth)
        out = b if out is None else out + b
    return out


def cup():
    """Switch cup: walls from the floor down to the rocker's panel, panel with the snap-in cutout."""
    outer = Pos(0, SW_Y, 0) * slab(rr(*CUP_OUT, 1.0), PANEL_BOT_Z, 0.01)
    return outer


def cup_cut():
    inner = Pos(0, SW_Y, 0) * slab(rr(*CUP_IN, 0.5), PANEL_TOP_Z, CAP_T + 1)
    cutout = Pos(0, SW_Y, 0) * slab(Rectangle(*SW_CUT), PANEL_BOT_Z - 1, PANEL_TOP_Z + 0.1)
    return inner + cutout


def pin_holes():
    """Two of the cap's openings: one round each spring pin (5 V side, R9); the third is the rocker's cutout."""
    out = None
    for x, y in PINS:
        h = Pos(x, y, CAP_T / 2) * Cylinder(PIN_CAP_HOLE_D / 2, CAP_T + 2)
        out = h if out is None else out + h
    return out


def build():
    body = Pos(0, 0, CAP_T / 2) * Cylinder(CAP_R, CAP_T)
    body += cup()
    body += trim_bosses()
    body += board_bosses()
    body += mains_bosses()
    body -= cup_cut()
    for x, y in SCREWS:
        body -= screw_hole(x, y)
    body -= trim_bores()
    body -= pin_holes()
    return body


if __name__ == "__main__":
    from pathlib import Path
    from build123d import export_step, export_stl
    out = Path(__file__).resolve().parents[3] / "build" / "eu"
    out.mkdir(parents=True, exist_ok=True)
    p = build()
    bb = p.bounding_box()
    print(f"cap bbox x {bb.min.X:.1f}..{bb.max.X:.1f} y {bb.min.Y:.1f}..{bb.max.Y:.1f} z {bb.min.Z:.1f}..{bb.max.Z:.1f}"
          f"  vol {p.volume/1000:.1f} cm3 valid={p.is_valid} solids={len(p.solids())}")
    export_step(p, str(out / "cap.step"))
    export_stl(p, str(out / "cap.stl"), tolerance=0.02, angular_tolerance=0.1)

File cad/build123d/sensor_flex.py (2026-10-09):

"""SENSOR FLEX (D-27): single-layer flex in the trim from the MSR-2's CN2 to the SHT45.

Route: plug end under the MSR-2 (CN2 at the board's right end), out through the bay frame,
up the top-right corner to just under the face skin, down the right channel, then along the
bottom to the SHT45 bay, the SHT45 soldered on the flex tail. In the channel two Harwin
S7081-42R spring fingers (+5 V, GND) on the flex underside press on the gold pads of the 5 V
jumper's pad end (D-31), which lies on a shelf off the insert flange.
Above the finger section the flex widens towards the flange for the I2S microphone (D-29), on the
flex underside, its port facing the face skin.
Open (D-27): CN2's exact part, contact count and pin map (MEASURE).
"""
from math import atan2, degrees, hypot
from build123d import Box, Cylinder, Pos, Rot
from params import *

Z_LO = STIFF_T + FLEX_T / 2                      # flex centre at the MSR-2 end
Z_HI = FLEX_HI_Z + FLEX_T / 2                    # flex centre in the channel
Z_SHT = SKIN_Z - 0.5 - SHT_CHIP[2] - FLEX_T / 2  # SHT45 on the flex top, 0.5 mm under the face vents

ROUTE = [(MSR_CN2_X, MSR_Y, Z_LO), (FLEX_X, MSR_Y, Z_LO),
         (FLEX_X, MSR_Y - FLEX_RISE_DY, Z_HI), (FLEX_X, SHT_Y, Z_HI),
         (SHT_ENTRY, SHT_Y, Z_HI), (0.0, SHT_Y, Z_SHT)]


def segment(a, b):
    """Flat strip FLEX_W x FLEX_T from a to b (straight run in x or in the y-z plane)."""
    dx, dy, dz = b[0] - a[0], b[1] - a[1], b[2] - a[2]
    c = Pos((a[0] + b[0]) / 2, (a[1] + b[1]) / 2, (a[2] + b[2]) / 2)
    if abs(dy) < 1e-9 and abs(dz) < 1e-9:
        return c * Box(abs(dx) + 0.01, FLEX_W, FLEX_T)
    if abs(dx) < 1e-9:
        tilt = degrees(atan2(dz, dy))
        return c * Rot(tilt, 0, 0) * Box(FLEX_W, hypot(dy, dz) + 0.01, FLEX_T)
    tilt = degrees(atan2(dz, dx))                 # x run with a drop in z
    return c * Rot(0, -tilt, 0) * Box(hypot(dx, dz) + 0.01, FLEX_W, FLEX_T)


def flex():
    out = plug_end()
    for a, b in zip(ROUTE, ROUTE[1:]):
        out += segment(a, b)
    return out


def plug_end():
    """Plug end and neck taper of the flex at the wall plane (outline from params.flex_half_width)."""
    from build123d import Polyline, extrude, make_face
    xs = [-FLEX_PLUG[0] / 2, FLEX_PLUG[0] / 2, FLEX_PLUG[0] / 2 + FLEX_NECK_L]
    top = [(MSR_CN2_X + x, MSR_Y + flex_half_width(x)) for x in xs]
    bot = [(MSR_CN2_X + x, MSR_Y - flex_half_width(x)) for x in reversed(xs)]
    face = make_face(Polyline(*top, *bot, top[0]))
    return Pos(0, 0, Z_LO - FLEX_T / 2) * extrude(face, FLEX_T)


def stiffeners():
    """FR4 stiffeners: under the CN2 plug (wall side) and over the spring fingers (skin side)."""
    plug = Pos(MSR_CN2_X, MSR_Y, STIFF_T / 2) * Box(B2B[0] + 2.0, FLEX_W, STIFF_T)
    x0, x1, (y0, y1) = FINGER_SEC_IN, FINGER_SEC_OUT, FINGER_SEC_Y
    fingers = Pos((x0 + x1) / 2, (y0 + y1) / 2, FLEX_HI_Z + FLEX_T + STIFF_T / 2) * Box(x1 - x0, y1 - y0, STIFF_T)
    return plug + fingers + mic_stiffener()


def mic_section():
    """Flex widened towards the flange over the microphone (D-29)."""
    (y0, y1), x1 = MIC_SEC_Y, FLEX_X + FLEX_W / 2
    return Pos((MIC_SEC_IN + x1) / 2, (y0 + y1) / 2, FLEX_HI_Z + FLEX_T / 2) * Box(x1 - MIC_SEC_IN, y1 - y0, FLEX_T)


def mic_stiffener():
    """FR4 stiffener over the microphone (skin side), port hole through flex and stiffener."""
    w, h = MIC[0] + 1.0, MIC[1] + 1.0
    z = FLEX_HI_Z + FLEX_T + STIFF_T / 2
    s = Pos(MIC_X, MIC_Y, z) * Box(w, h, STIFF_T)
    return s - Pos(*MIC_PORT, z) * Cylinder(MIC_FLEX_HOLE_D / 2, STIFF_T + 0.1)


def mic():
    """Microphone body under the flex and the adhesive gasket ring between stiffener and skin."""
    body = Pos(MIC_X, MIC_Y, FLEX_HI_Z - MIC[2] / 2) * Box(*MIC)
    z0 = FLEX_HI_Z + FLEX_T + STIFF_T
    ring = Pos(*MIC_PORT, (z0 + SKIN_Z) / 2) * (Cylinder(MIC_GASKET_D / 2, SKIN_Z - z0)
                                                - Cylinder(MIC_SKIN_HOLE_D / 2, SKIN_Z - z0 + 0.1))
    return body + ring


def finger_section():
    """Flex widened over the finger section: towards the flange over the pads, into the trim wall
    recess (longer) for the tracks that pass them."""
    z = FLEX_HI_Z + FLEX_T / 2
    xi0, xi1, (yi0, yi1) = FINGER_SEC_IN, FLEX_X + FLEX_W / 2, FINGER_SEC_Y
    xo0, xo1, (yo0, yo1) = FLEX_X - FLEX_W / 2, FINGER_SEC_OUT, FINGER_LANE_Y
    pads = Pos((xi0 + xi1) / 2, (yi0 + yi1) / 2, z) * Box(xi1 - xi0, yi1 - yi0, FLEX_T)
    lanes = Pos((xo0 + xo1) / 2, (yo0 + yo1) / 2, z) * Box(xo1 - xo0, yo1 - yo0, FLEX_T)
    return pads + lanes
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

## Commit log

2026-10-06 v0.1 handoff: build123d plate, docs, PCB spec
    [pcb_outline.dxf, plate.stl, wallplate.scad]
2026-10-07 PSU carrier: KiCad 9 project, DRC rules, PCBWay fab pack
    42 x 44 mm 2-layer THT board generated by pcb/tools (ERC/DRC clean at all
    severities with schematic parity). Netclass + custom rules for PRI-SEC
    clearance/creepage >= 6 mm and L-N >= 2.5 mm (targets, human review).
    F1 T1A is a designer's choice: Mean Well gives no fuse rating.
    [Fuse_TR5_D8.5mm_H8mm.step, pcb_outline.dxf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]
2026-10-07 v0.2 CAD: box insert + trim split, coupons, checks
    Insert carries all barrier geometry and prints floor-down without supports
    (thick floor, 45 deg taper, chamfered flange, gabled roof over the PCB).
    Fixes the v0.1 finger-scoop leak into the mains side. checks.py adds a
    barrier-continuity test, PSU STEP fit and a BREP overhang check.
    [coupons.py, params.py]
2026-10-07 Print: ElegooSlicer projects for the Centauri Carbon 2
    PC-FR insert, PETG test-fit insert, PETG trim, PETG coupons. print/slice.py
    rebuilds them from stock CC2 profiles plus small override sets.
    [coupons_PETG.3mf, insert_PC-FR.3mf, insert_PETG_testfit.3mf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]
2026-10-07 Docs: v0.2 decisions, printing, BOM part numbers, status
2026-10-07 Print: support OrcaSlicer, regenerate projects with OrcaSlicer 2.4.2
    slice.py finds OrcaSlicer or ElegooSlicer (SLICER / ORCA_SLICER /
    ELEGOO_SLICER or PATH), runs AppImages without FUSE, and keeps the CLI's
    result.json out of the repo. Settings match the ElegooSlicer build except
    printer metadata and unused cool-plate temperatures.
    [coupons_PETG.3mf, insert_PC-FR.3mf, insert_PETG_testfit.3mf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]
2026-10-07 Tooling: pin OrcaSlicer as the slicer
    make slicer downloads OrcaSlicer 2.4.2 into .tools/ and verifies its
    sha256; make print uses it unless SLICER is set. slice.py drops the
    ElegooSlicer lookups. tools/install-system-deps.sh installs KiCad 9 and
    the headless libraries the AppImage needs (make system-deps).
2026-10-07 PCB tools: find KiCad libraries and pcbnew Python portably
    gen_libs.py no longer assumes /usr/share/kicad: it uses KICAD9_SYMBOL_DIR /
    KICAD9_FOOTPRINT_DIR, the kicad-cli prefix and common distro/Flatpak/macOS
    paths, and keeps the committed project libraries when the stock ones are
    missing. export_fab.sh runs gen_pcb.py with a Python that can import
    pcbnew, so an active virtualenv no longer breaks it.
2026-10-07 BILRESA model at 45 x 70 mm, shaded 3D renders
    Model the remote with its rounded back, wheel, LEDs and parting line
    (bilresa.py) and use it in the assembly, the section sheet and a new
    clearance check. Size it 45 x 70 mm with an R8.5 back round-over, from
    IKEA UK's product size and a third-party mount pocket (reference values,
    docs/MEASUREMENTS.md). Pocket clearance 0.6 -> 0.5 mm so the pocket stays
    inside the insert's box-clearance outline (D-21).
    Add pyvista renders (render3d.py, make renders) and show them in the
    README. Regenerate the OrcaSlicer projects.
    [coupons_PETG.3mf, insert_PC-FR.3mf, insert_PETG_testfit.3mf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]
2026-10-07 Wiring board v0.3 replaces the v0.2 PSU carrier
    Single board (D-24..D-26) moves to pcb/: WAGO 2604-1106 terminal block,
    Marquardt 1802.2504 DPST rocker, IRM-03-5 PSU, OVC III spacing rules.
    Four mounting holes for the insert's screw-in snap posts (three plated
    into the PE ring), filleted trace bends and pour corners, ant and KiCad
    logos, project URL. make pcb now runs pcb/tools/build.sh: ERC/DRC, STEP
    and a PCBWay pack (S1 not fitted). The v0.2 carrier project is removed.
    [Fuse_TR5_D8.5mm_H8mm.step, Marquardt_1802.2504.step, WAGO_2604-1106.step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]
2026-10-07 CAD v0.3: rocker insert, board posts, sensor flex route, magnet slot
    Insert reworked for the Marquardt 1802.2504 (PSU rails removed), bosses
    with tapped M4 holes for four screw-in snap posts (post.py, print job),
    shelf for the spring-finger power contact. Sensor flex route in the trim
    (sensor_flex.py, D-27) with frame notches. Magnet recess runs to the end
    of the remote's flat back with a rounded bottom. Checks for board fit
    against the KiCad file, terminal entry vs PSU, mounting, flex stack and
    spring-finger working height.
    [coupons_PETG.3mf, insert_PC-FR.3mf, insert_PETG_testfit.3mf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]
2026-10-07 Docs and renders for v0.3
    Decisions D-21..D-28, BOM, measurements, printing and safety updated for
    the wiring board, board posts and sensor flex; v0.3 renders replace the
    v0.2 set, including wiring board, copper, flex route and power contact.
2026-10-07 Model the 5 V lead; widen the flex finger section
    lead.py: twin lead (2 x 0.8 mm, 300 V) from the wiring board's J2 across
    the gap at x 17, through the pass-through (kept low in the 45 deg leg so
    it exits under the trim skin) to the target board's lead pads; checks for
    the hole wall and clearance to every part. The flex widens over the
    spring fingers into a 1 mm recess in the trim's side wall so four tracks
    can pass the finger pads; route constants moved to params.
    [coupons_PETG.3mf, insert_PC-FR.3mf, insert_PETG_testfit.3mf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]
2026-10-07 Docs and renders: 5 V power path, lead in the BOM
    New v0.3_power view (insert cut at the pass-through), lead shown in the
    flex, contact and exploded views; BOM lead spec, AGENTS layout, D-20
    reference to the removed pcb/SPEC.md.
2026-10-09 Wiring board: J1 and rocker from vendor models, rocker clear of WAGO pins, LOAD labels
    [Fuse_Schurter_UMT250.step, Marquardt_1802.2504.step, Varistor_TDK_CU4032.step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]
2026-10-09 Sensor flexes: 2-layer 5 V jumper with tongue, back cover flex, EU sensor flex
    [Harwin_S7081-42R.step, PUI_DMM-4026-B-I2S_4x3mm.step, Sensirion_DFN-4_1.5x1.5mm_P0.8mm_SHT4x_NoCentralPad.step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]
2026-10-09 EU boards: WAGO 2604-3102 from its model, SMT header, order packs
    [Converter_ACDC_TRACO_TMPS03_THT.step, Fuse_Schurter_UMT250.step, Harwin_P70-2200045.step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]
2026-10-09 CAD: back cover, battery-free tongue and floor insert, part retention, estimates
2026-10-09 CAD EU variant: cap, trim, floor insert, sensor flex, checks, renders
    [cap_eu.py, params_eu.py, sensor_eu.py]
2026-10-09 Print projects: back cover, floor inserts, EU cap and trim
    [backcover_PETG.3mf, coupons_PETG.3mf, eu_cap_PC-FR.3mf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]
2026-10-09 Docs and renders: D-37 to D-45, assembly guide, EU and back cover renders
